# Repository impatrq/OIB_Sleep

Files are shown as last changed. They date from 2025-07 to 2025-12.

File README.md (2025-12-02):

 

ORTHOPEDICAL INTELLIGENT BED

INTEGRANTES:
Ezequiel Bourlot
Lorenzo Fernández
Joaquín Vignettta
Federico Domoñi

Objetivo:
Un colchón que se termo regule dependiendo del estado de sueño en el que se encuentre una persona 

Cómo surgió el proyecto?

La idea del proyecto surgio debido a problemas de sueño generales en la familia de un integrante y cuando buscamos estudios descubrimos que son muy comunes y tienen grandes efectos sobre la mayoria de la población y tambien que se podian aliviar con la temperatura durante el sueño

Video presentación:
https://youtu.be/yen7QRbAJQ8?si=tZINnR11tU10LYak

Página Web e instagram:
https://oib-sleep.vercel.app
https://www.instagram.com/oibsleep?igsh=MXVqZHRpbnUxYzlxYw==

Descripción y aplicaciones:
El proyecto cuenta con una férula la cual toma datos biométricos de la persona (ritmo cardiaco, temperatura ambiente, temperatura corporal, acelerómetro) para determinar el estado de sueño en el que se encuentra un a persona. 
De ahí, manda estos datos a unos tanques de agua donde se determinará si se tiene que mandar agua fría o caliente a través del colchón mediante la utilización de caños de cobre.
La idea es poder prolongar el estado de sueño REM de una persona para así mejorar su calidad de sueño. 
También, al regular la temperatura del colchón, se puede tratar distintas patologías en pacientes de hospitales, ya sean personas con problemas de migrañas, adultos mayores con poca termo regulación, personas cuadripléjicas que no pueden determinar la temperatura de su cuerpo, etc.

Agradecimientos: A Simmons, Layer by Layer y la cooperadora de la escuela por proveernos con los materiales para poder llevar acabo el proyecto y la ayuda.

Contactos:

Joaquin Vignetta: jvignetta@gmail.com
https://www.linkedin.com/in/joaquin-vignetta-2a78a7398 
https://github.com/joavig357

Federico Rodriguez Domoñi: federicorodriguezdomoni@gmail.com
https://www.linkedin.com/in/federico-rodriguez-domoñi-6005b51b8
https://github.com/FedericoRD

Ezequiel Bourlot: ezequiel.bourlot@gmail.com
https://www.linkedin.com/in/ezequiel-bourlot-a96094232
https://github.com/eze2508

Lorenzo Fernandez: lfern9407@gmail.com
https://www.linkedin.com/in/maximo-lorenzo-fernandez-39a160397
https://github.com/lorenzrt

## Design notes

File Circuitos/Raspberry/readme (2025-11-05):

Placa de la raspberry con todas las salidas necesarias

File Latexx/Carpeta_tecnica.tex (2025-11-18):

\documentclass{report}
\usepackage{graphicx}
\usepackage{fancyhdr}
\usepackage[top=2cm]{geometry}
\usepackage{tikz}
\usepackage{etoolbox}
\usepackage[spanish]{babel}
\usepackage[hidelinks]{hyperref}
\usepackage{enumitem}
\usepackage[utf8]{inputenc}
\usepackage[T1]{fontenc}
\usepackage{xcolor}
\usepackage{textgreek}
\usepackage{listings}
\usepackage{float}
\usepackage{amssymb}
\usepackage{amsmath}
\usepackage{siunitx}
\usetikzlibrary{shapes.geometric, arrows.meta, positioning, fit, calc}

\usetikzlibrary{shapes.geometric, arrows.meta, positioning, calc}

\tikzstyle{startstop} = [ellipse, minimum width=2cm, minimum height=0.8cm, text centered, draw=black, fill=blue!20, font=\small\bfseries]
\tikzstyle{process} = [rectangle, minimum width=2.5cm, minimum height=0.8cm, text centered, draw=black, fill=purple!15, font=\scriptsize]
\tikzstyle{decision} = [diamond, minimum width=2cm, minimum height=0.8cm, text centered, draw=black, fill=orange!20, font=\scriptsize, aspect=2]
\tikzstyle{score} = [rectangle, rounded corners, minimum width=2cm, minimum height=0.8cm, text centered, draw=black, fill=green!15, font=\scriptsize]
\tikzstyle{indicator} = [rectangle, rounded corners, minimum width=2cm, minimum height=0.8cm, text centered, draw=black, fill=yellow!20, font=\scriptsize\bfseries]
\tikzstyle{arrow} = [thick,->,>=Stealth]

\setlength{\fboxsep}{0pt}  % elimina el espacio interno
\setlength{\fboxrule}{1pt} % grosor del borde

\renewcommand{\contentsname}{\Huge Índice General}
\renewcommand{\listfigurename}{\Huge Índice de Figuras}
\definecolor{C}{HTML}{2A4190}
\definecolor{Y}{HTML}{FC9B32}

\fancypagestyle{plain}{%
  \fancyhf{}%
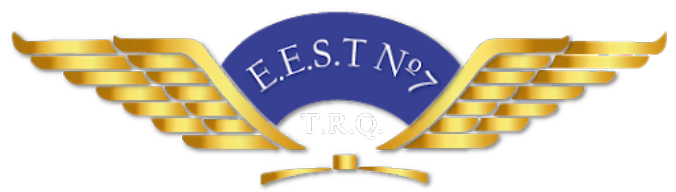
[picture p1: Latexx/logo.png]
  \fancyhead[c]{}%
  \fancyhead[L]{\textbf{\footnotesize OIB Sleep 2025}}%
  \fancyhead[R]{\textbf{\footnotesize E.E.S.T N°7 IMPA "T.R.Q."}}%
  \renewcommand{\footrulewidth}{0.4pt}
  \fancyfoot[C]{\thepage}%
}

% Aplicar el estilo a todas las páginas
\pagestyle{plain}
\renewcommand{\headrulewidth}{0.4pt}

\begin{document}
\begin{center}
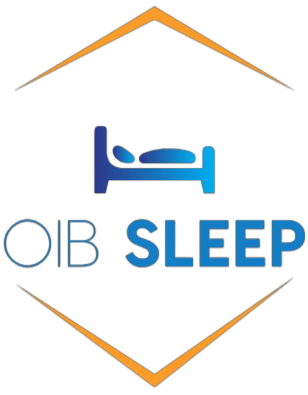
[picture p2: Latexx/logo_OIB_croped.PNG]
    
    \\[1cm]
    {\Huge Carpeta Técnica} \\[0.5cm]
    {\huge 7mo 2da Comision A \\[0.5cm] Año 2025} \\
    \LARGE Bourlot Ezequiel \\
    Fernandez Lorenzo \\
    Domoñi Federico\\
    Vignetta Joaquin\\
\end{center}

\newpage

\tableofcontents 

\newpage
\listoffigures

\newpage
\chapter[\Large Preámbulo]{Preámbulo}

\section[large Nuestro contacto]{\LARGE Nuestro Contacto}
\noindent
\\
\href{https://www.instagram.com/oibsleep}{%
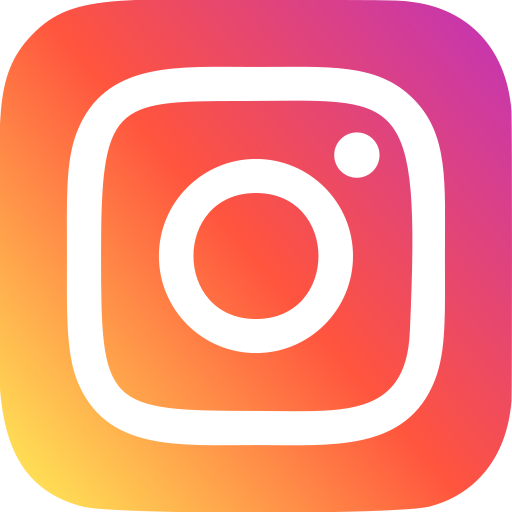
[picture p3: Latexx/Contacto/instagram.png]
    %
} \raisebox{1.25cm}{\Huge\ \ @oibsleep}
\\[0.3cm]
\href{mailto:oibsleep@gmail.com}{%
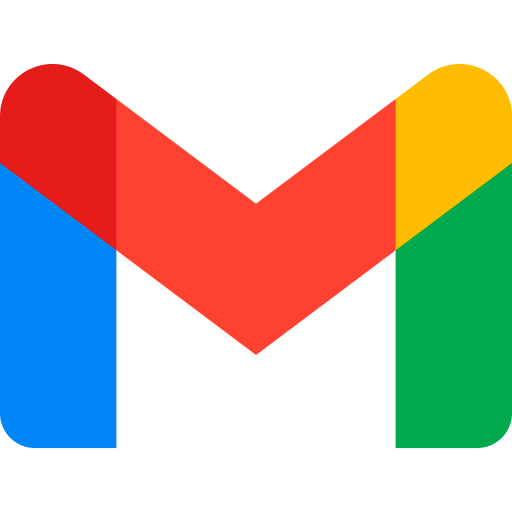
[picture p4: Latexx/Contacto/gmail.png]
    %
}\raisebox{1.25cm}{\Huge\ \ oibsleep@gmail.com}
\\[0.3cm]
\href{https://oib-sleep.vercel.app}{%
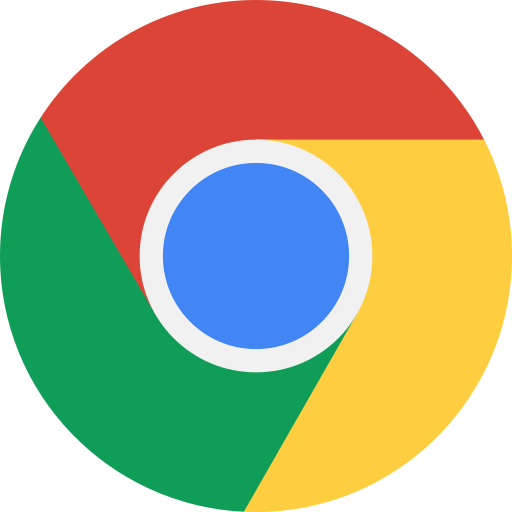
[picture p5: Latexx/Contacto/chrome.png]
    %
}\raisebox{1.25cm}{\Huge\ \ oib-sleep.vercel.app}
\\[0.3cm]
\href{https://github.com/impatrq/OIB_Sleep}{%
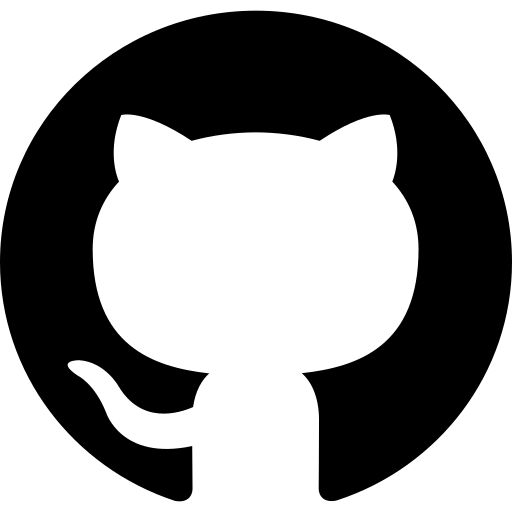
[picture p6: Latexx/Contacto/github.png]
    %
}\raisebox{1.25cm}{\Huge\ \ github.com/impatrq/OIB\_Sleep}%
\\

\section[large ¿Quienes somo?]{\LARGE Quienes somos?}

\setlength{\parskip}{1.5em}

% ---------- Integrante 1 ----------
\begin{minipage}{0.45\linewidth}
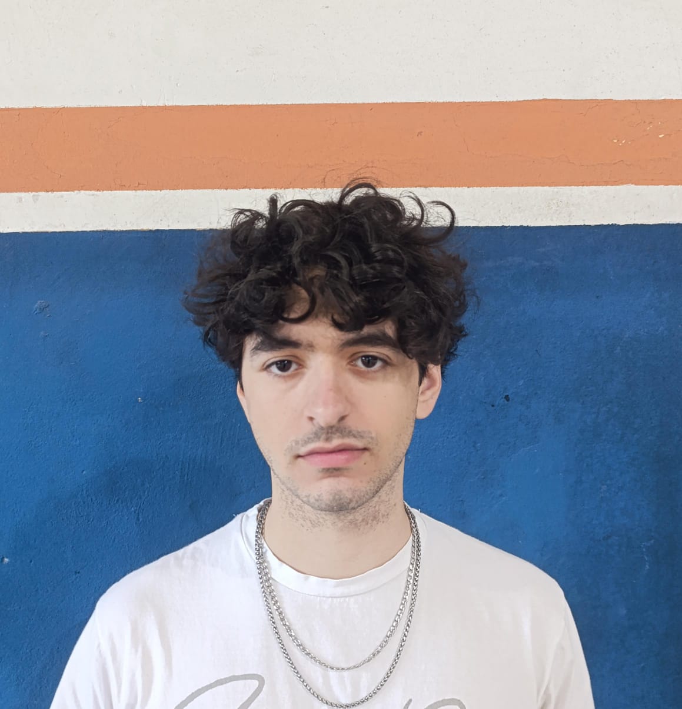
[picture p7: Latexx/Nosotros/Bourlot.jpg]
    
\end{minipage}
\hfill
\begin{minipage}{0.5\linewidth}
    \textbf{\Large Bourlot Ezequiel} \\[4pt]
     \hspace{0.3cm}
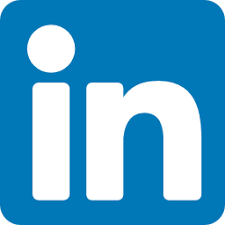
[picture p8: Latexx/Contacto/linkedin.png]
     \hspace{0.3cm}
     \\[10pt]
    \textit{\large Encargado del diseño electrónico, programación y control térmico del sistema.}
\end{minipage}

% ---------- Integrante 2 ----------
\begin{minipage}{0.45\linewidth}
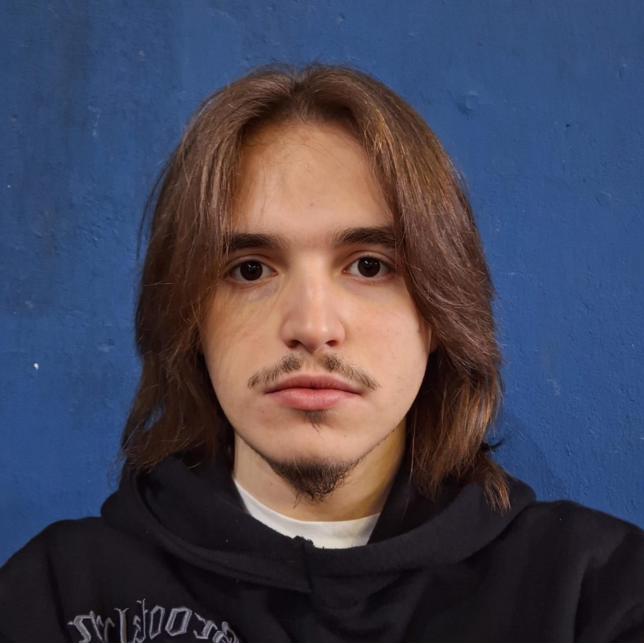
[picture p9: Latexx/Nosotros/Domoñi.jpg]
    
\end{minipage}
\hfill
\begin{minipage}{0.5\linewidth}
    \textbf{\Large Federico Domoñi} \\[4pt]
     \hspace{0.3cm}
     \hspace{0.3cm}
     \\[10pt]
    \textit{\large Responsable del diseño mecánico y estructura del sistema de tanques.}
\end{minipage}

\newpage

% ---------- Integrante 3 ----------
\begin{minipage}{0.45\linewidth}
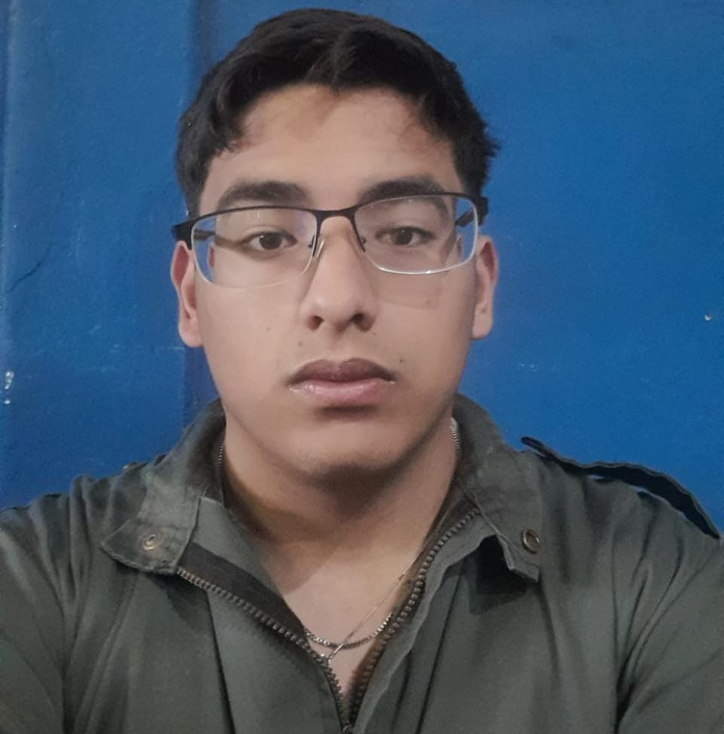
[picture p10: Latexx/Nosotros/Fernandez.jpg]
    
\end{minipage}
\hfill
\begin{minipage}{0.5\linewidth}
    \textbf{\Large Fernández Lorenzo} \\[4pt]
     \hspace{0.3cm}
     \hspace{0.3cm}
     \\[10pt]
    \textit{\large Encargado de documentación técnica, cálculos térmicos y presentación.}
\end{minipage}

% ---------- Integrante 4 ----------
\begin{minipage}{0.45\linewidth}
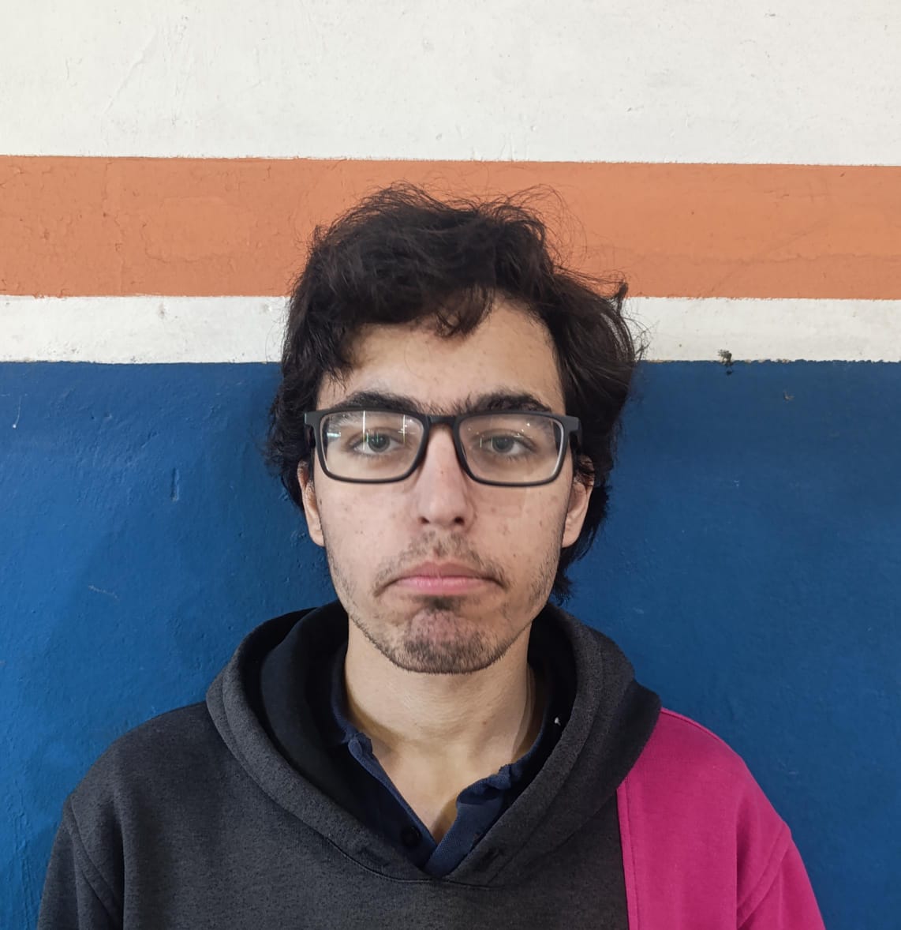
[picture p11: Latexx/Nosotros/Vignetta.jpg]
    
\end{minipage}
\hfill
\begin{minipage}{0.5\linewidth}
    \textbf{\Large Vignetta Joaquín} \\[4pt]
     \hspace{0.3cm}
     \hspace{0.3cm}
     \\[10pt]
    \textit{\large Responsable del diseño visual, edición de video y comunicación del proyecto.}
\end{minipage}

\newpage
\thispagestyle{empty} % sin número ni encabezado

\newgeometry{left=0cm, right=0cm, top=5cm, bottom=0cm}
\begin{figure}[H]
    \centering
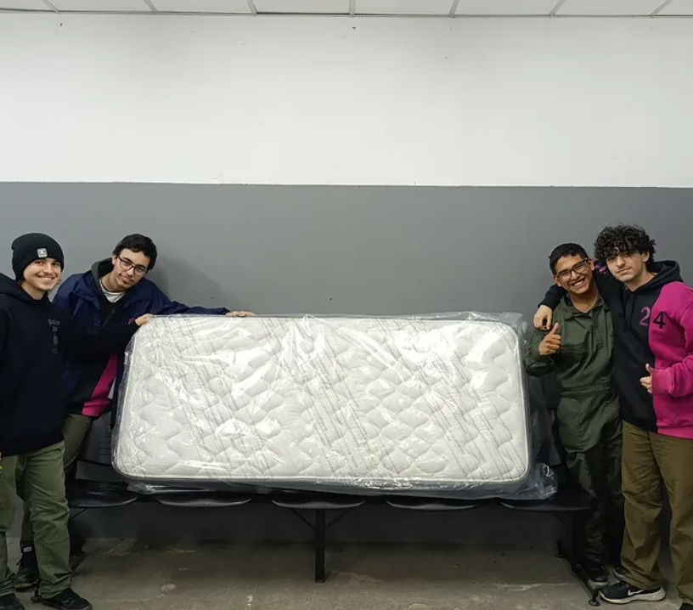
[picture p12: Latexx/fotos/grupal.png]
    
\end{figure}
\restoregeometry

\section[large Docentes a cargo]{\LARGE Docentes a cargo}
\begin{itemize} [label=$\star$]
\Large
    \item Medina Sergio
    \item Carlassara Fabrizio
    \item Palmier Diego
    \item Bianco Carlos 
    \item Arguello Gabriel
    \item Solomiewicz Federico
\end{itemize}

\section[\large Agradecimientos]{\Large agradecimientos}
\noindent
\large
Agradecemos a la Asociación Cooperadora del IMPA.\\
Agradecemos a Simmons Por el colchón, que fue lo principal en nuestro proyecto\\
Agradecemos a layer by layer por los acoples para las mangueras\\
Agradecemos al personal docente de la institución por el inmenso apoyo que nos brindaron.

\section[\large Lenguajes usados]{\Large Lenguajes usados}
\begin{itemize} [label=$\bullet$]
    \item HTML5 \raisebox{-0.1cm} {\includegraphics[height=0.4cm] {lenguajes/html-5}}
    \item CSS3 \raisebox{-0.06cm} {\includegraphics[height=0.4cm] {lenguajes/css-3}}
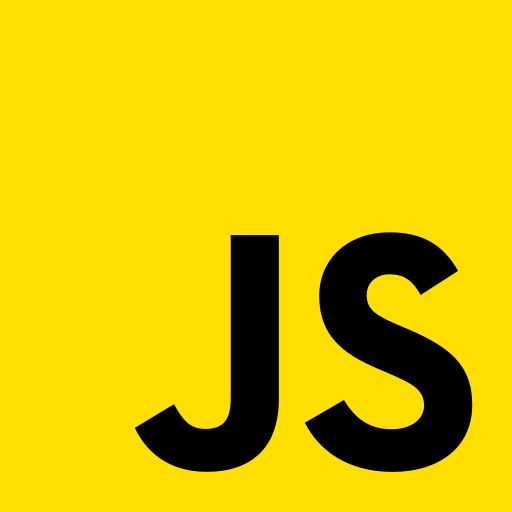
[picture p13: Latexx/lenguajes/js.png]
    \item JavaSCript \raisebox{-0.1cm} {}
    \item Python \raisebox{-0.1cm} {\includegraphics[height=0.4cm] {lenguajes/python}}
    \item C++ \raisebox{-0.1cm} {\includegraphics[height=0.4cm] {lenguajes/c-}}
    \item LaTeX \raisebox{-0.1cm} {\includegraphics[height=0.4cm] {lenguajes/LaTeX_logo.svg}}
\end{itemize}

\section[\large Programas utilizados]{\Large Programas utilizados}
\begin{itemize} [label=$\bullet$]
    \item Visual Studio Code \raisebox{-0.1cm} {\includegraphics[height=0.4cm] {programas/vscode.png}}
    \item OverLeaf \raisebox{-0.06cm} {\includegraphics[height=0.4cm] {programas/overleaf}}
    \item PlatformIO \raisebox{-0.06cm} {\includegraphics[height=0.4cm] {programas/PlatformIO}}
    \item Raspberry PI Imager \raisebox{-0.07cm} {\includegraphics[height=0.4cm] {programas/PI}}
    \item PowerShell \raisebox{-0.07cm} {\includegraphics[height=0.4cm] {programas/PowerShell}}
    \item Ubuntu WSL \raisebox{-0.07cm} {\includegraphics[height=0.4cm] {programas/Ubuntu}}
    \item KiCad \raisebox{-0.07cm} {\includegraphics[height=0.4cm] {programas/KiCad}}
    \item Blender \raisebox{-0.1cm} {\includegraphics[height=0.4cm] {programas/Blender}}
    \item AutoCAD \raisebox{-0.07cm} {\includegraphics[height=0.4cm] {programas/AutoCAD}}
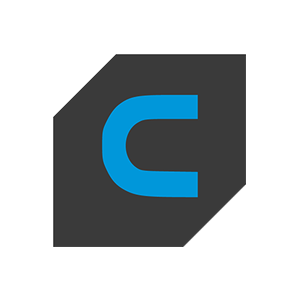
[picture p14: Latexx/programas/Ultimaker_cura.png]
    \item Ultimaker cura \raisebox{-0.15cm}{}
    \item Fusion3D \raisebox{-0.07cm} {\includegraphics[height=0.4cm] {programas/Fusion}}
    \item Word \raisebox{-0.07cm} {\includegraphics[height=0.4cm] {programas/Word}}
    \item Figma \raisebox{-0.07cm} {\includegraphics[height=0.4cm] {programas/Figma}}
    \item Ibis Paint \raisebox{-0.05cm} {\includegraphics[height=0.4cm] {programas/Ibis}}
\end{itemize}

\newpage

\chapter[\Large Introducción]{Introducción}

\section[\large ¿Que es OIBsleep?]{\Huge ¿Que es \textcolor{C}{OIB}\textcolor{Y}{sleep}?}
\large{
La cama ortopédica OIB sleep Es un colchón de uso hospital o personal que cuenta con sistema de calefacción/refrigeración que se regula mediante diferentes mediciones del paciente.
 Esta cama sirve para mejorar la calidad de sueño y prevenir enfermedades como la migraña al regular la temperatura en búsqueda de mantener el sueño REM (profundo) la mayor cantidad de tiempo posible. También se busca solucionar diferentes problemas de salud mediante esta regulación como, por ejemplo:
 \begin{itemize} [label=$\bullet$]
\item Pacientes con problemas de circulación entre ellos diabéticos o personas con problema de artritis suelen tener manos y pies fríos, y pueden no notar bien si están demasiado fríos o calientes (especialmente en el caso de la neuropatía diabética).
\item Adultos mayores, ya que la regulación de la temperatura disminuye con la edad.
\item Personas con fibromialgia o dolor crónico, el calor puede aliviar el dolor muscular y articular mientras que el frío reduce la inflamación.
\item Personas con problemas de sueño como insomnio o despertares nocturnos debido a la temperatura
 \end{itemize}
Se puede conseguir regular la temperatura del colchón mediante un sistema con tubos de agua que se regule con mediciones que se hacen con el colchón mismo o con una pulsera. Esto le ayudaría a los hospitales a mantener a varios pacientes en una misma habitación con las temperaturas necesarias para cada uno.
}

\section[\large Utilidades del proyecto]{\Huge Utilidades del proyecto}
Utilidades del proyecto:
OIB sleep es un proyecto planteado para hospitales que busca ayudar a las personas que tienen problemas debido a la falta de sueño y también a quienes la temperatura puede ayudar con sus respectivas enfermedades.
Tomamos la temperatura como base, ya que El entorno térmico es uno de los factores más importantes que pueden afectar el sueño humano''. Los efectos típicos de la exposición al calor o al frío son un aumento del estado de vigilia y una disminución del sueño de movimientos oculares rápidos (REM) y del sueño de ondas lentas.

\section[\large Impacto en Argentina]{\Huge Impacto en Argentina}
En Argentina, los problemas relacionados con el sueño representan un desafío creciente para la salud pública. 
Según un estudio de la Universidad Favaloro, \textbf{el 75\% de la población presenta algún tipo de alteración del sueño}, lo cual evidencia la necesidad de soluciones innovadoras que contribuyan a mejorar el descanso y la calidad de vida.  

\subsection{Impacto en la salud pública}
\begin{itemize} [label=$\bullet$]
    \item Mejora la calidad del sueño, reduciendo riesgos asociados a insomnio, migrañas y problemas cardiovasculares.  
    \item Favorece a pacientes con enfermedades crónicas como artritis, fibromialgia, diabetes y problemas de circulación, donde la regulación térmica es un factor clave.  
    \item Contribuye al bienestar de adultos mayores, un grupo poblacional que representa más del 11\% de los argentinos y que suele tener dificultades para regular la temperatura corporal durante el descanso.  
\end{itemize}

\subsection{Impacto en hospitales y centros de salud}
\begin{itemize} [label=$\bullet$]
    \item Permite la \textbf{regulación de la temperatura individual en habitaciones compartidas}, lo cual mejora la atención personalizada y optimiza el uso de recursos.  
    \item Potencial ahorro energético al evitar climatizar espacios completos, reduciendo los costos operativos.  
\end{itemize}

\subsection{Impacto en el mercado argentino}
\begin{itemize} [label=$\bullet$]
    \item Dada la alta prevalencia de trastornos del sueño, existe un \textbf{mercado amplio} para este tipo de tecnologías tanto en hospitales como en el uso domiciliario.  
    \item La producción nacional del sistema puede fomentar la \textbf{industria tecnológica local}, generando empleo y reduciendo costos de importación.  
\end{itemize}

\section[\large ¿Por qué OIBsleep?]{\Huge ¿Por qué \textcolor{C}{OIB}\textcolor{Y}{sleep}?}

\subsection{Usuarios que ayuda}
OIB Sleep está diseñado para mejorar la salud del sueño tanto en entornos hospitalarios como domésticos. Esto se logra a través de la regulación inteligente de la temperatura, ayudando a grupos como:
\begin{itemize}
    \item adutlos mayores
    \item Personas diabéticas
    \item Personas con insomnio
    \item Personas con fibromialgia
\end{itemize}

\subsection{Limitaciones de los métodos tradicionales}
El aire acondicionado, la estufa y otros métodos permiten modificar la temperatura del ambiente, pero ninguno de estos sistemas se adapta a las necesidades térmicas específicas de tu cuerpo ni responde a los cambios que experimentás mientras dormís. Estos métodos actúan de forma general sobre toda la habitación, sin tener en cuenta las variaciones naturales de la temperatura corporal a lo largo de la noche.
Además, al climatizar todo el espacio en lugar de centrarse únicamente en la persona, generan un consumo energético considerablemente mayor, lo que se traduce en un uso ineficiente de la energía y en un impacto ambiental más alto.

\subsection{La importancia del confort térmico durante el sueño}
La temperatura corporal no permanece constante durante el sueño: tiende a descender durante las fases más profundas y vuelve a elevarse de manera natural al acercarse el momento del despertar. Este ciclo térmico cumple un rol fundamental en la regulación del descanso y en la transición entre las distintas etapas del sueño.
Cuando el entorno no acompaña estos cambios —por ejemplo, si la habitación se mantiene demasiado cálida o demasiado fría—, el cuerpo debe esforzarse para compensar esa diferencia, lo que puede provocar microdespertares e interrumpir el descanso, reduciendo así la calidad y la continuidad del sueño.

\subsection{Una solución personalizada y directa}
OIB Sleep actúa directamente sobre la cama, en contacto con tu cuerpo, ajustando la temperatura del colchón en tiempo real según tus necesidades. De esta forma, el sistema responde de manera inteligente a los cambios térmicos que se producen durante el sueño, brindando una sensación de confort constante y personalizada.
Al intervenir únicamente sobre el colchón y no sobre el ambiente completo, permite alcanzar el confort térmico ideal con un consumo energético significativamente menor y sin alterar la temperatura del entorno.

\subsection{Confort desde el primer momento}
Más allá de su control inteligente, OIB Sleep ofrece funciones pensadas para maximizar el confort desde el primer momento. Permite precalentar la cama en invierno o enfriarla en verano antes de acostarte, logrando así que el colchón alcance la temperatura ideal incluso antes de que te recuestes.
De esta manera, transforma el momento de ir a dormir en una experiencia más placentera y personalizada, adaptándose a tus preferencias y al clima de cada estación.

\chapter[\Large Estructura]{Estructura}
\section[\large ¿Como esta estructurada la cama?]{\Huge ¿Como esta estructurada la cama?}
La cama cuenta con un colchón especialmente modificado en cuyo interior se instalaron Caños de cobre de 1/4 x 1 m esmaltados.Para colocarlos, utilizamos una plegadora que nos permitió insertar los tubos dentro del colchón realizando una serie de dobleces estratégicos, asegurando así una distribución uniforme del calor a lo largo de toda la superficie.
El sistema está compuesto por dos circuitos independientes: uno por el que circula agua caliente y otro por el que circula agua fría. Ambos tubos están conectados a sus respectivos tanques, lo que permite regular la temperatura del colchón de manera precisa y eficiente.

\begin{figure}[H]
\centering
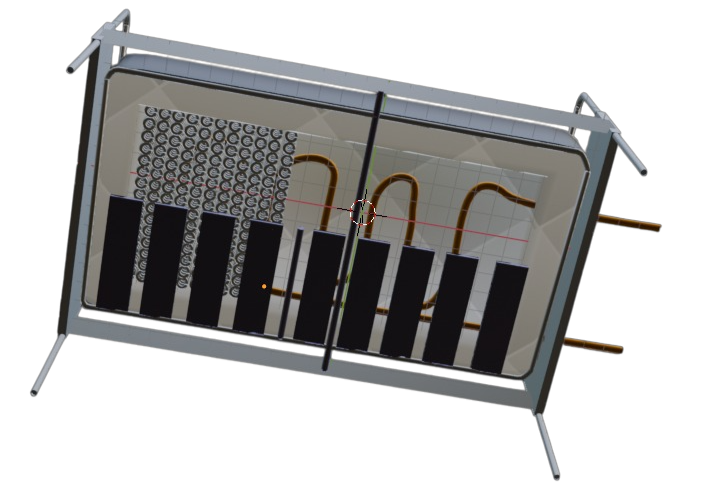
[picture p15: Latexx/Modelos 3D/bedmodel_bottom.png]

\caption{Vista inferior del modelo 3D de la cama con sistema de tubos}
\label{fig:cama_inferior}
\end{figure}

\section[\large ¿Como esta estructurado el brazalete?]{\Huge ¿Como esta estructurado el brazalete?}
El brazalete fue diseñado mediante un modelo 3D desarrollado en Blender y fabricado con material PLA, elegido por su equilibrio entre solidez, ligereza y flexibilidad.
El diseño incluye una serie de perforaciones distribuidas estratégicamente para permitir una adecuada ventilación y el paso del aire, garantizando así mayor comodidad durante su uso. En la siguiente imagen se puede observar la estructura y disposición de dichos orificios.

\begin{figure}[H]
\centering
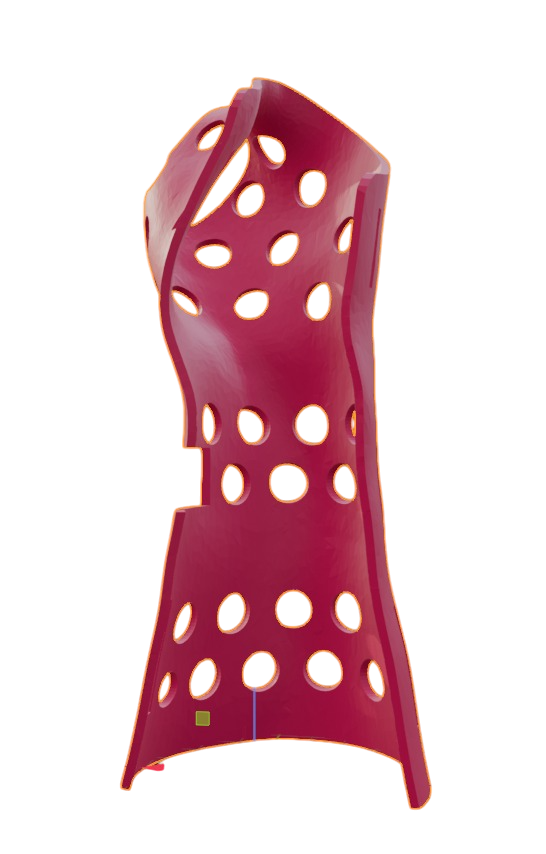
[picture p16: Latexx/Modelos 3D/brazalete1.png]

\caption{Diseño 3D del brazalete - Vista frontal con perforaciones de ventilación}
\label{fig:brazalete_frontal}
\end{figure}

\begin{figure}[H]
\centering
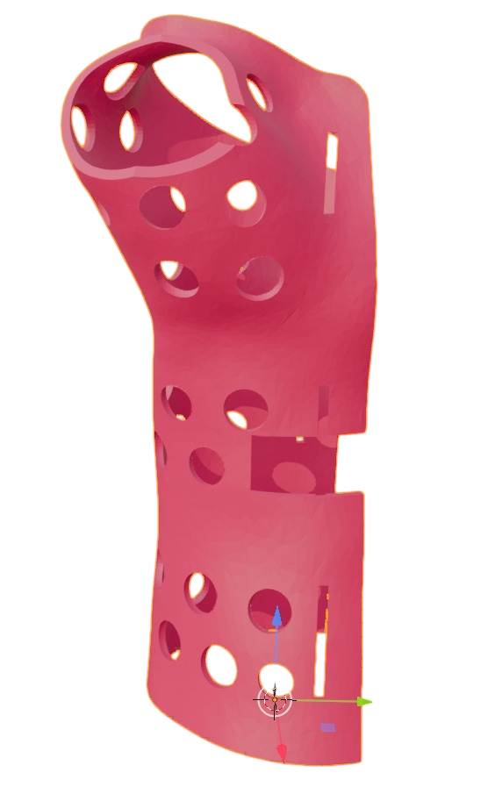
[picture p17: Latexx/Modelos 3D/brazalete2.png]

\caption{Diseño 3D del brazalete - Vista lateral detallada}
\label{fig:brazalete_lateral}
\end{figure}

\newpage
Además, el brazalete está recubierto con una capa de goma espuma, lo que mejora la sensibilidad al tacto y aporta una sensación más cómoda al contacto con la piel.
Una vez impreso, el modelo fue lijado cuidadosamente para eliminar imperfecciones y lograr una superficie uniforme, optimizando tanto su estética como su funcionalidad.

\begin{figure}[H]
\centering
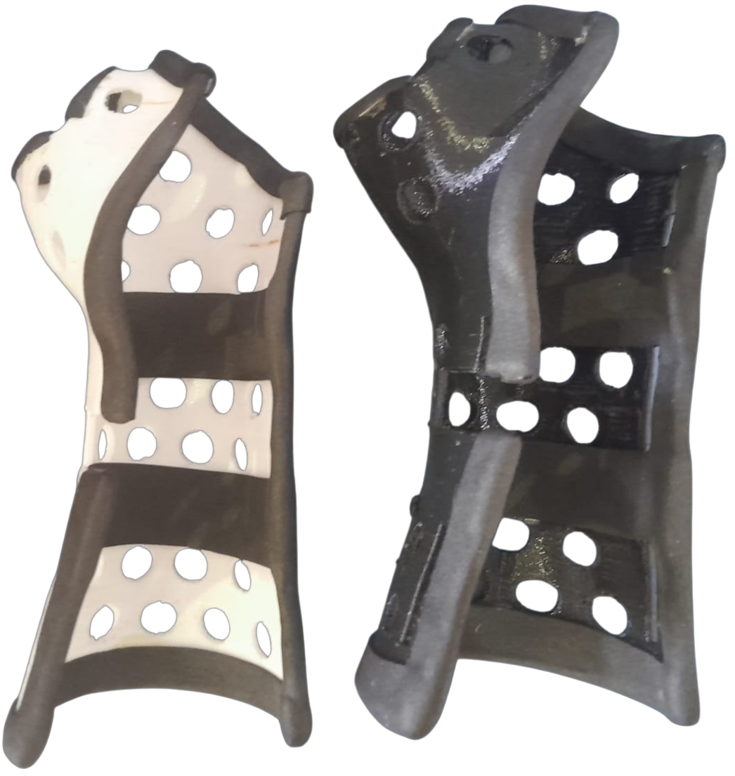
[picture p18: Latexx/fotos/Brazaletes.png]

\caption{Brazaletes impresos y terminados}
\label{fig:brazaletes_terminados}
\end{figure}

El brazalete cuenta con un compartimiento destinado a alojar los diferentes sensores, diseñado para mantenerlos firmemente en su lugar y facilitar su conexión. Este compartimiento se fija al brazalete mediante abrojos (velcro), lo que permite retirarlo o ajustarlo fácilmente según sea necesario, garantizando al mismo tiempo estabilidad y comodidad durante el uso.

\begin{figure}[H]
\centering
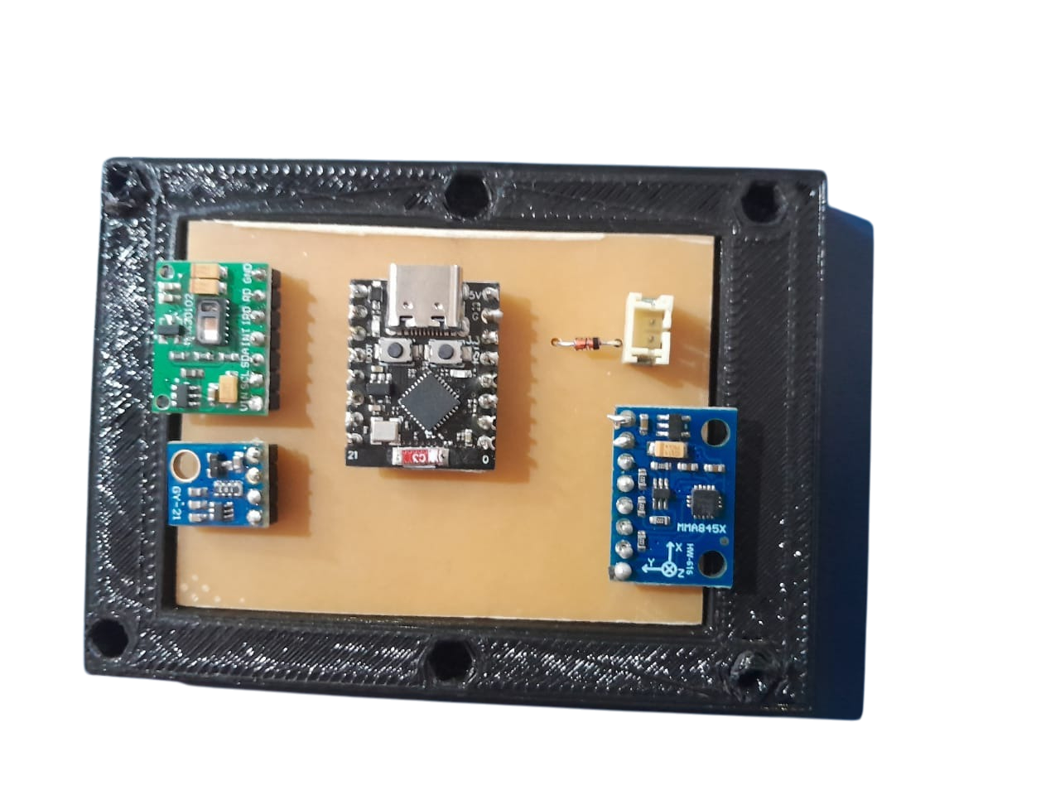
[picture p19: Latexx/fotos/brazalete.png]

\caption{Brazalete con compartimiento para sensores}
\label{fig:brazalete_sensores}
\end{figure}

\begin{figure}[H]
\centering
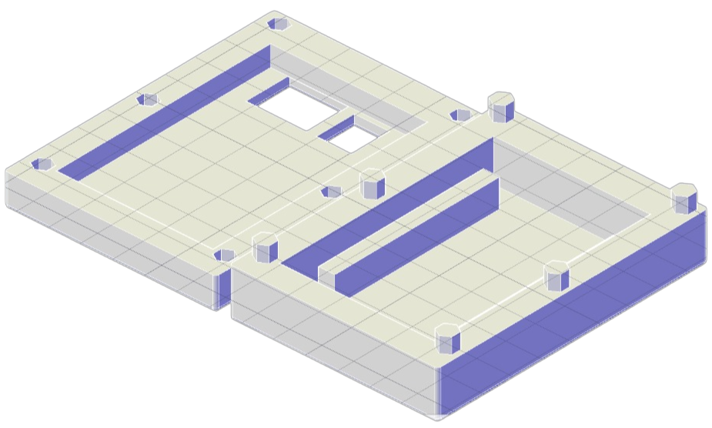
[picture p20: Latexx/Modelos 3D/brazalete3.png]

\caption{Modelo 3D del compartimiento de sensores del brazalete}
\label{fig:brazalete_compartimiento}
\end{figure}

\section[\large ¿Como están estructurados los tanques?]{\Huge ¿Como están estructurados los tanques?}
En este proyecto se utilizan dos tanques principales, uno destinado al agua fría y otro al agua caliente, los cuales desempeñan un papel fundamental en el sistema de regulación térmica. Ambos tanques están aislados térmicamente con espuma de poliuretano, un material de alta densidad que permite mantener la temperatura interna estable, reduciendo significativamente las pérdidas de calor o de frío hacia el exterior.

El tanque de agua fría está equipado con seis celdas Peltier, cada una acompañada de su disipador de calor y su correspondiente cooler, también tienen una placa de metal del la parte del tanque para que se pase mejor el calor. Estas celdas funcionan mediante un principio termoeléctrico: al recibir corriente, una de sus caras absorbe el calor del interior del tanque (enfriando el agua), mientras que la otra lo disipa hacia afuera con la ayuda de los coolers. De esta forma, se logra un proceso de refrigeración activa y controlada, manteniendo la temperatura del agua dentro de los rangos deseados.

\begin{figure}[H]
    \centering
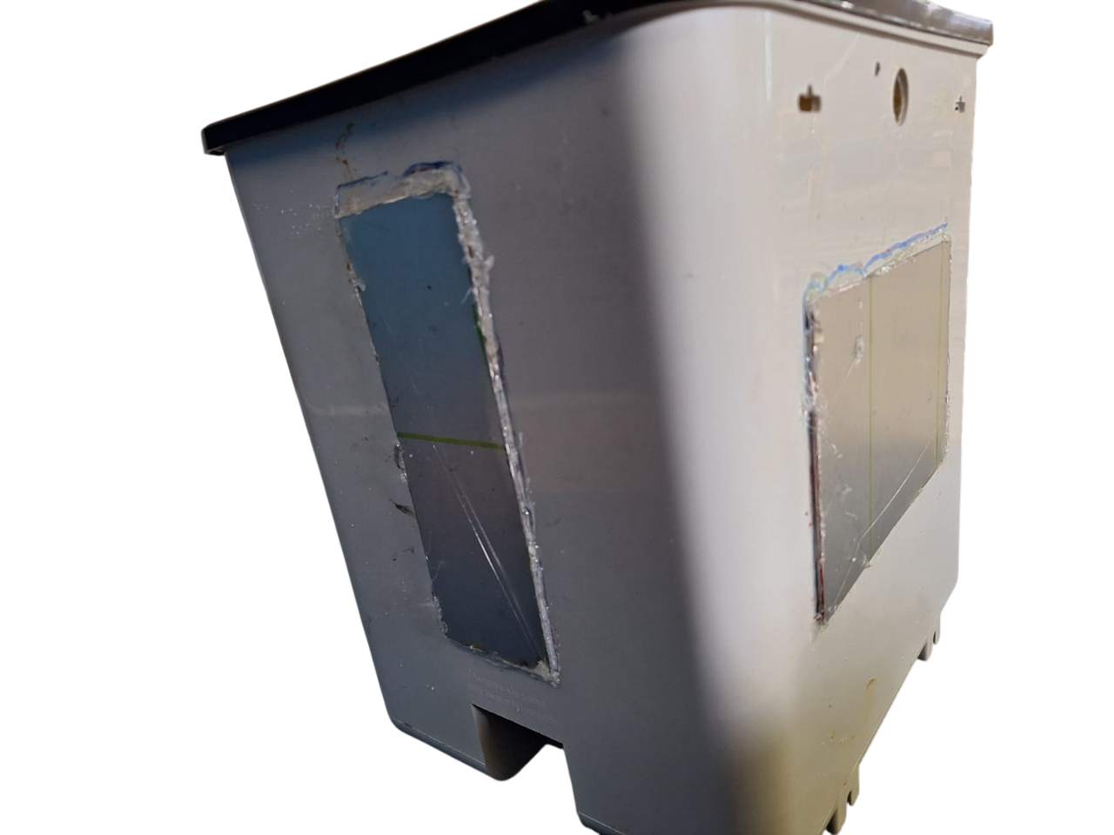
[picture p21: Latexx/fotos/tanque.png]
    \fbox{}
    \caption{Tanque frío sin las celdas}
    \label{fig:tanquefrio}
\end{figure}

Por otro lado, el tanque de agua caliente cuenta con una resistencia eléctrica encargada de elevar la temperatura del agua. Este sistema está supervisado por un sensor de temperatura sumergible, que mide de manera continua el valor térmico del agua y permite pausar automáticamente el calentamiento cuando se alcanza una temperatura preestablecida, evitando sobrecalentamientos y optimizando el consumo energético.

En conjunto, ambos tanques trabajan de forma complementaria dentro del sistema, proporcionando un control térmico eficiente y preciso, esencial para garantizar el confort y la estabilidad del entorno en el que se implementa el proyecto.

\subsection{¿Como están colocados?}

\subsection{Cálculos de temperatura para el agua fría}

El sistema de enfriamiento del tanque de agua fría se basa en la utilización de celdas Peltier TEC1-12706, cada una con una capacidad aproximada de transferencia de calor ($Q_c$) de 60 W cuando opera con una diferencia de temperatura de 10 °C y alimentada a 12 V con un consumo de 6 A (potencia total 72 W). En el diseño propuesto se contempla un tanque con una capacidad total de 20 litros, debidamente aislado con espuma de poliuretano para minimizar las pérdidas térmicas. La temperatura ambiente promedio se considera de 30 °C, y el objetivo es reducir la temperatura del agua a 10 °C.

El agua, con una masa de aproximadamente 20 kg (considerando una densidad de 1 kg/L), requiere una extracción de energía térmica calculada mediante la ecuación:

\[
Q = m \cdot c \cdot \Delta T
\]

donde $c$ es el calor específico del agua (4186 J/kg·°C) y $\Delta T = 20$ °C (de 30 °C a 10 °C). De esta manera, la cantidad total de energía a retirar del sistema es de aproximadamente:

\[
Q = 20\,\text{kg} \times 4186\,\frac{\text{J}}{\text{kg}\cdot{}^\circ\text{C}} \times 20\,^\circ\text{C} = 1{,}674{,}400\,\text{J}
\]

Cada celda Peltier TEC1-12706 puede retirar alrededor de 60 W (60 J/s) en condiciones óptimas; sin embargo, considerando las ineficiencias y pérdidas térmicas del sistema, se estima una eficiencia real del 40 %, lo que reduce la capacidad efectiva de enfriamiento a unos 24 W por celda.

Para el sistema implementado, se utilizan \textbf{6 celdas Peltier TEC1-12706}, por lo que la potencia total efectiva de enfriamiento es:

\[
P = 6 \times 24\,\text{W} = 144\,\text{W} = 144\,\text{J/s}
\]

En estas condiciones, el tiempo teórico requerido para reducir la temperatura del agua de 30 °C a 10 °C sería:

\[
t = \frac{1\,674\,400\,\text{J}}{144\,\text{J/s}} \approx 11\,625\,\text{s} \approx 3\,\text{h}\,13\,\text{min}.
\]

No obstante, en la práctica, debido a pérdidas adicionales por conducción, eficiencia variable de las celdas y disipación incompleta del calor en la cara caliente, el tiempo real estimado de enfriamiento se sitúa entre \textbf{3,5 y 4 horas}. Con esta configuración, el sistema logra no solo enfriar el agua desde 30 °C hasta los 10 °C, sino también mantenerla estable a esa temperatura, incluso con una temperatura ambiente de 30 °C, gracias al aislamiento térmico del tanque.

Para el control térmico, el sistema utiliza sensores de temperatura \textbf{DS18B20} sumergidos en el tanque de agua fría y otro sensor en la parte interna del tanque de agua caliente para compensar el control térmico global del circuito hidráulico. Los sensores DS18B20 permiten una precisión de $\pm 0.5$ °C, facilitando una regulación exacta de la temperatura. La lectura de los sensores y el control de activación de las celdas Peltier se realiza mediante una \textbf{Raspberry Pi}, que además activa los relés asociados a cada grupo de celdas según las condiciones térmicas programadas.

\chapter[\Large Circuitos]{Circuitos}
\section[\large Resumen]{\Huge Resumen}
Para el correcto funcionamiento del proyecto fue necesario implementar distintos circuitos electrónicos encargados de controlar los diversos sistemas que lo componen. El centro de control principal está basado en una Raspberry Pi Zero 2 W, la cual coordina y administra el comportamiento de todos los componentes del sistema.

Esta placa actúa como el cerebro del proyecto, gestionando la activación de las bombas de agua, el control de las válvulas y el funcionamiento de los módulos de refrigeración y calefacción del colchón. Su tarea es asegurar que cada elemento se encienda o apague en el momento que se necesite, de acuerdo con las necesidades de temperatura determinadas por el algoritmo de control.

Además, la Raspberry Pi se comunica de forma inalámbrica mediante Wi-Fi con la pulsera inteligente del usuario, desde la cual recibe datos en tiempo real sobre parámetros relevantes. Esta información es utilizada por el sistema para ajustar dinámicamente la temperatura del colchón, logrando así un mayor confort y eficiencia energética durante el descanso.
\subsection{Pulsera}
La pulsera cuenta con un módulo ESP32 Mini que se encarga de transmitir de manera inalámbrica la información hacia una Raspberry Pi utilizando conectividad Wi-Fi, estableciendo así una comunicación eficiente y continua entre ambos dispositivos. A la ESP32 Mini se encuentran conectados tres sensores mediante el bus de comunicación I²C, cada uno con una función específica dentro del sistema: un sensor de temperatura AHT10, encargado de registrar las variaciones térmicas del entorno y del cuerpo del usuario; un acelerómetro MMA845Q , utilizado para detectar y analizar los movimientos y la posición corporal; y un sensor de ritmo cardíaco Max30102, que permite medir la frecuencia cardíaca en tiempo real.
Toda la información obtenida por estos sensores es procesada por la ESP32 Mini. Una vez procesados, los resultados son enviados a la Raspberry Pi, que se encarga de realizar el cálculo del estado de sueño del usuario y determinar la temperatura óptima requerida para mantener el confort durante el descanso, utilizando algoritmos de análisis de datos. garantizando un funcionamiento inteligente, autónomo y adaptable a las condiciones individuales de cada usuario.

\begin{figure}[H]
\centering
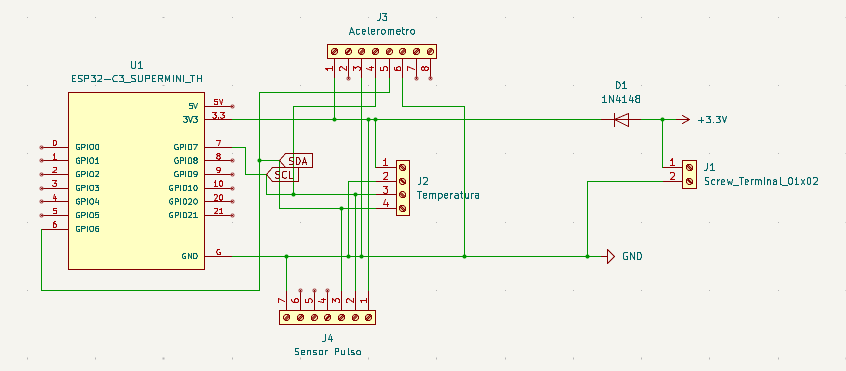
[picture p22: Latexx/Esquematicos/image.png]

\caption{Esquemático del circuito de la pulsera}
\label{fig:EsquematicoPulsera}
\end{figure}

\vspace{1cm}

\begin{figure}[H]
\centering
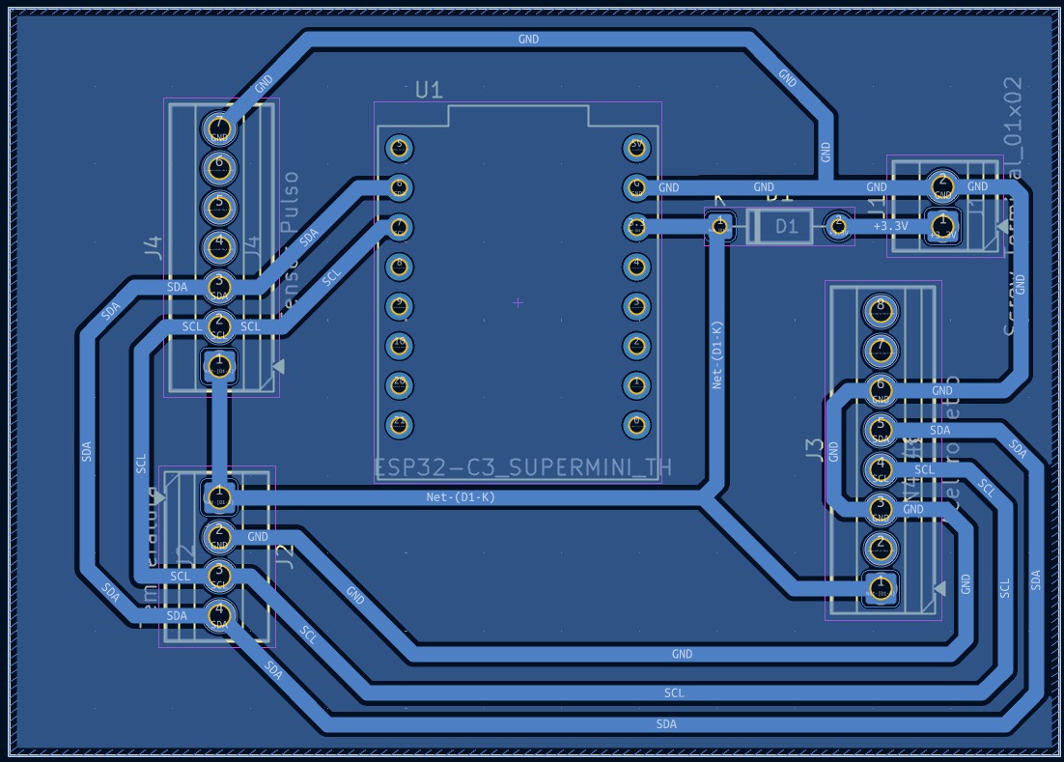
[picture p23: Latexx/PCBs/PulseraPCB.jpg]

\caption{PCB del circuito de la pulsera}
\label{fig:PCBPulsera}
\end{figure}

\subsection{Bombas de agua}
El circuito de bombeo está formado por dos módulos idénticos que permiten la conmutación y alimentación de las bombas mediante control digital desde la Raspberry Pi, cada módulo integra un relé electromecánico modelo SRD-12VDC-SL-C accionado a 12 V para aislar la carga de la lógica de control, un transistor BC337 empleado como interruptor de baja impedancia para manejar la bobina del relé desde un pin GPIO de la Raspberry Pi y los componentes de protección y polarización necesarios para un funcionamiento seguro y fiable, entre estos se consideran la resistencia de base para limitar la corriente hacia la base del BC337, un diodo 1N4007 conectado en paralelo con la bobina del relé para absorber picos inductivos y proteger el transistor.

\begin{figure}[H]
\centering
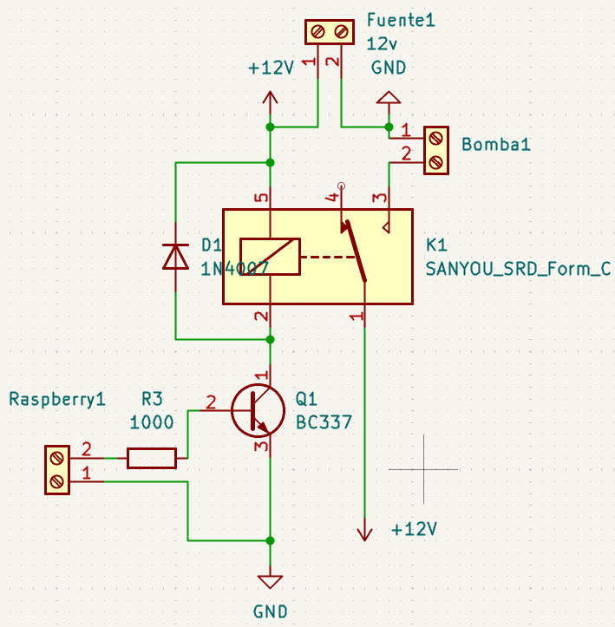
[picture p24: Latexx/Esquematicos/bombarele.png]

\caption{Esquemático del circuito de las bombas de agua}
\label{fig:Esquematicobombarele}
\end{figure}

\begin{figure}[H]
\centering

\caption{PCB del circuito de las bombas de agua}
\label{fig:PCBBombas}
\end{figure}

\subsection{Valvulas/Resistencia}
El circuito encargado del control de las válvulas y de la resistencia del calefón está diseñado bajo el mismo principio de funcionamiento que el utilizado en el sistema de bombas, empleando un relé y un transistor como elementos principales de conmutación y control. Sin embargo, a diferencia del circuito anterior, en este caso los dispositivos controlados operan con tensión de red de 220 V, por lo que la llave de conmutación del relé trabaja directamente sobre la línea de 220 V en lugar de hacerlo sobre una de 12 V, garantizando así la capacidad de manejar las cargas de mayor potencia que requieren estos componentes.

El relé es accionado mediante un transistor BC337, que actúa como interfaz entre la lógica de control de la Raspberry Pi y el circuito de potencia, permitiendo aislar eléctricamente la señal de control de los niveles de tensión elevados. En la entrada de control proveniente de la Raspberry Pi se incorpora una resistencia de 1 kΩ, cuya función principal es limitar la corriente hacia la base del transistor y proteger tanto al microcontrolador como al propio circuito de conmutación y un diodo en paralelo a la bobina del rele, asegurando un funcionamiento estable y seguro en todo momento.

\begin{figure}[H]
\centering

\caption{Esquemático del circuito de las valvulas y resistencia}
\label{fig:EsquematicoValvulasResistencia}
\end{figure}

\begin{figure}[H]
\centering

\caption{PCB del circuito de las valvulas y resistencia}
\label{fig:PCBvalvulasResistencia}
\end{figure}

\subsection{Raspberry Pi Zero 2 W}
Esta placa constituye el núcleo principal de control de todos los sistemas, siendo el elemento encargado de coordinar, procesar y ejecutar las distintas funciones automatizadas del conjunto. Su diseño integra una serie de salidas de 3.3 V y de tierra (GND) destinadas a la alimentación de los módulos y sensores periféricos, además de contar con pines GPIO programables, utilizados para emitir señales de control hacia los diferentes actuadores del sistema, entre ellos las bombas, válvulas y mecanismos de regulación térmica. Asimismo, dispone de una interfaz de comunicación I²C, mediante la cual se establecen las conexiones con los sensores de temperatura distribuidos en las distintas secciones del sistema, permitiendo una adquisición de datos precisa y sincronizada.

La placa tiene como función principal ejecutar el algoritmo de control de sueño, el cual recibe y procesa la información proveniente del módulo ESP32 Mini instalado en la pulsera del usuario. A partir de los datos recopilados por los sensores de temperatura, ritmo cardíaco y movimiento, el algoritmo realiza un análisis integral que permite determinar la temperatura ideal del entorno para optimizar el descanso del usuario. Una vez obtenida esta temperatura objetivo, la placa se encarga de activar y regular los diferentes sistemas asociados, tales como calefacción, refrigeración o circulación de agua, enviando las órdenes correspondientes a cada componente mediante las salidas de control.

Este diseño garantiza una integración completa entre la etapa de sensado y la de actuación, logrando una operación eficiente, segura y adaptable a las condiciones variables del entorno y las necesidades del usuario. Además, su arquitectura modular facilita futuras actualizaciones o ampliaciones del sistema, permitiendo incorporar nuevos sensores o funciones sin modificar la estructura general del hardware.

\begin{figure}[H]
\centering

\caption{PCB del circuito de la Raspberry Pi Zero 2 W}
\label{fig:EsquematicoRaspberryPi}
\end{figure}

\begin{figure}[H]
\centering

\caption{PCB del circuito de la Raspberry Pi Zero 2 W}
\label{fig:PCBRaspberryPi}
\end{figure}

\subsection{Celdas de Peltier y Coolers}

El sistema de enfriamiento del tanque de agua fría se basa en el uso de \textbf{celdas Peltier} combinadas con \textbf{coolers} que actúan como disipadores de calor para evitar el sobrecalentamiento de los módulos. Este conjunto permite mantener una temperatura baja y estable dentro del tanque, garantizando un rendimiento eficiente y seguro durante el funcionamiento.

En total, el sistema cuenta con \textbf{seis celdas Peltier modelo TEC1-12706}, seleccionadas por su capacidad de enfriar de manera efectiva mediante el principio termoeléctrico. Estas celdas están dispuestas estratégicamente para maximizar la transferencia térmica y optimizar la distribución del frío dentro del tanque.

Cada celda se encuentra acompañada por su respectivo \textbf{cooler y disipador de aluminio}, cuya función principal es evacuar el calor generado en la cara caliente de la Peltier, asegurando así su correcto desempeño y prolongando su vida útil.

La alimentación eléctrica del sistema se realiza mediante una \textbf{fuente de 12V y 40Ah}, modelo \textbf{FG-40M}, la cual provee la corriente necesaria para el funcionamiento simultáneo de las seis celdas. Las conexiones se establecen en \textbf{paralelo}, lo que permite mantener una tensión constante en cada módulo y equilibrar el consumo total del sistema, garantizando estabilidad y eficiencia energética.

Este diseño proporciona un método de refrigeración controlado, confiable y adaptable, ideal para mantener las condiciones térmicas requeridas por el sistema principal del proyecto.

\chapter[\Large Código]{Código}      

\section[\large Resumen]{\Huge Resumen}
Una de las partes más vitales del proyecto es el desarrollo del código, ya que representa el núcleo lógico que permite la comunicación, el procesamiento de datos y la toma de decisiones dentro del sistema. La arquitectura del software se divide en cuatro módulos principales, cada uno con una función específica y complementaria que, en conjunto, garantizan el correcto funcionamiento de la cama inteligente.

El primer módulo es el Presence Detector, encargado de analizar en tiempo real si hay una persona sobre la cama. Para ello, realiza una fusión de datos provenientes de distintos sensores —como temperatura, movimiento y ritmo cardíaco— con el fin de estimar de manera precisa la presencia o ausencia del usuario. Este componente es fundamental, ya que su salida condiciona el funcionamiento de los demás módulos.

El segundo módulo, denominado analyzer.py, es responsable de ejecutar todos los cálculos del algoritmo principal. A partir de la información recibida del Presence Detector y de los sensores, este componente determina las acciones a tomar para mantener la temperatura del colchón dentro del rango de confort del usuario. En función de las condiciones detectadas, el módulo decide si se debe activar el sistema de enfriamiento o el de calentamiento del agua, buscando siempre optimizar la experiencia de descanso.

El tercer módulo es el Smart Bed Controller, el cual actúa como intermediario entre el software lógico y el hardware físico. Su función es enviar señales de control —en forma de valores binarios (1 o 0)— hacia los tanques de agua fría y caliente y a sus valvulas electricas, activando o desactivando los relés correspondientes, tambien apaga las bombas a cada cierto tiempo para que no se quemen. Gracias a este controlador, las decisiones tomadas por el algoritmo pueden traducirse en acciones concretas sobre el sistema hidráulico.

Por último, se encuentra el módulo correspondiente a la pulsera inteligente, que cumple un rol clave en la adquisición de datos fisiológicos del usuario. Este dispositivo portátil recopila información proveniente de sus sensores (como frecuencia cardíaca, temperatura y movimiento) y la transmite a la Raspberry Pi mediante el protocolo MQTT, utilizando una conexión Wi-Fi local. De esta forma, la cama inteligente dispone de datos actualizados y precisos para alimentar el algoritmo de control térmico.

En conjunto, estos cuatro módulos conforman un sistema integral capaz de detectar la presencia del usuario, analizar su estado, tomar decisiones autónomas y ejecutar las acciones necesarias para ajustar la temperatura del colchón. Esta estructura modular permite un desarrollo escalable, fácil de mantener y adaptable a futuras mejoras del proyecto.

\section[\large Explicación Técnica Detallada - Presence Detector]{\Huge Explicación Técnica Detallada - Presence Detector}

\subsection{Arquitectura General del Sistema}

El módulo \texttt{presence\_detector.py} implementa un sistema de detección de presencia en cama inteligente mediante fusión multi-sensor, utilizando cinco indicadores independientes que se combinan para generar un nivel de confianza global.

\subsection{Clase Principal: BedPresenceDetector}

\subsubsection*{Atributos de Estado}

\textbf{Estado de presencia actual:}
\begin{itemize}
  \item \texttt{bed\_occupied (bool)}: Indica si la cama está ocupada actualmente.
  \item \texttt{presence\_confidence (float)}: Nivel de confianza de presencia en porcentaje (0-100).
  \item \texttt{presence\_history (list)}: Buffer circular que almacena los últimos N valores de confianza.
  \item \texttt{presence\_start\_time (float)}: Timestamp Unix del momento en que se detectó entrada a la cama.
\end{itemize}

\textbf{Valores de referencia (baseline):}
\begin{itemize}
  \item \texttt{baseline\_temperature (float)}: Temperatura de referencia de la cama vacía, actualizable dinámicamente.
  \item \texttt{baseline\_activity (float)}: Nivel de actividad de referencia (actualmente no utilizado).
\end{itemize}

\textbf{Parámetros configurables:}
\begin{itemize}
  \item \texttt{confidence\_threshold\_enter}: Umbral para detectar entrada (60\% por defecto).
  \item \texttt{confidence\_threshold\_exit}: Umbral para detectar salida (20\% por defecto).
  \item \texttt{thermal\_threshold}: Incremento térmico sobre baseline (1.5°C por defecto).
  \item \texttt{activity\_threshold}: Nivel mínimo de actividad (0.001 por defecto).
  \item \texttt{hr\_min} y \texttt{hr\_max}: Rango válido de frecuencia cardíaca (40–150 BPM).
  \item \texttt{history\_size}: Tamaño del buffer de historial (30 muestras).
  \item \texttt{confirmation\_time}: Muestras consecutivas necesarias para confirmar salida (15 muestras).
\end{itemize}

Todos los parámetros se cargan desde el módulo \texttt{bed\_config}, permitiendo ajuste sin modificar el código.

\subsection{Método Principal: \texttt{detect\_presence()}}

\subsubsection*{Flujo de Procesamiento}

El método recibe un diccionario \texttt{sensor\_data} con:
\begin{itemize}
  \item \texttt{bed\_temperature}: Lectura del sensor HTU21D.
  \item \texttt{activity}: Magnitud del vector del acelerómetro MMA8451.
  \item \texttt{heart\_rate}: Frecuencia cardíaca calculada por el MAX30102.
  \item \texttt{hr\_valid}: Booleano que indica si la medición de HR es confiable.
  \item \texttt{finger\_present}: Booleano indicando contacto físico con el sensor óptico.
\end{itemize}

\subsubsection*{Sistema de Puntuación Multi-Indicador}

\paragraph{1. Indicador Térmico (máximo 40 puntos)}
\begin{verbatim}
temp_elevation = bed_temp - baseline_temperature
\end{verbatim}

\textbf{Criterios:}
\begin{itemize}
  \item Si \texttt{temp\_elevation > thermal\_threshold}: +30 puntos.
  \item Si \texttt{temp\_elevation > thermal\_threshold * 2}: +10 puntos adicionales.
\end{itemize}

\textbf{Fundamento:} La presencia humana eleva la temperatura de la cama entre 1.5°C y 4°C.

\paragraph{2. Indicador de Movimiento (máximo 25 puntos)}
\begin{verbatim}
activity_score = min(25, int(activity * 25 / 0.1))
\end{verbatim}

\textbf{Fundamento:} Los micro-movimientos durante el sueño generan actividad detectable.

\paragraph{3. Indicador Cardiovascular (máximo 40 puntos)}

\textbf{Criterios:}
\begin{itemize}
  \item Si HR válida y en rango 40–150 BPM: +35 puntos.
  \item Si HR en rango de sueño (50–80 BPM): +5 puntos adicionales.
\end{itemize}

\textbf{Fundamento:} La frecuencia cardíaca válida confirma presencia humana con alta certeza.

\paragraph{4. Indicador de Contacto (máximo 20 puntos)}

\textbf{Criterios:}
\begin{itemize}
  \item Si \texttt{finger\_present == True}: +20 puntos.
\end{itemize}

\textbf{Fundamento:} Detecta contacto físico mediante señal infrarroja reflejada.

\paragraph{5. Indicador Temporal (máximo 10 puntos)}
\begin{verbatim}
avg_confidence = sum(presence_history[-5:]) / 5
\end{verbatim}

\textbf{Criterio:} Si el promedio de las últimas 5 muestras > 50\%, +10 puntos.

\textbf{Fundamento:} La presencia real genera señales consistentes en el tiempo.

\subsubsection*{Cálculo de Confianza Global}
\begin{verbatim}
confidence = min(sum(all_indicators), 100)
\end{verbatim}

La suma ponderada de indicadores se limita a 100\%, siendo tolerante a fallos parciales.

\subsection{Mecanismo de Histéresis}

\subsubsection*{Propósito}
Evita transiciones rápidas entre estados de presencia.

\subsubsection*{Implementación en \texttt{\_update\_presence\_state()}}

\textbf{Entrada (vacía → ocupada):}
\begin{itemize}
  \item Condición: \texttt{confidence >= threshold\_enter}
  \item Acción inmediata: activa ocupación y registra timestamp
\end{itemize}

\textbf{Salida (ocupada → vacía):}
\begin{itemize}
  \item Condición: \texttt{confidence <= threshold\_exit}
\item Confirmación: últimos \texttt{confirmation\_time} valores $\leq 30\%$

  \item Acción: cambia a vacía tras baja confianza sostenida
\end{itemize}

\textbf{Nota:} La asimetría evita falsas salidas durante quietud prolongada.

\subsection{Gestión del Baseline Térmico}

\subsubsection*{Inicialización}
El baseline se toma automáticamente con la primera lectura térmica.

\subsubsection*{Actualización Dinámica}
Cuando la cama está vacía:
\[
baseline = (1 - \alpha) \times baseline_{old} + \alpha \times temp_{current}
\]
con $\alpha = 0.05$.

\subsubsection*{Calibración Manual}
\begin{itemize}
  \item Toma N lecturas en 5 minutos.
  \item Calcula la mediana para eliminar outliers.
  \item Reemplaza el baseline actual.
\end{itemize}

\subsection{Métodos de Utilidad y Debugging}

\begin{itemize}
  \item \texttt{get\_presence\_summary()}: Retorna estado global.
  \item \texttt{get\_detailed\_indicators()}: Análisis granular de indicadores.
  \item \texttt{reset\_presence\_state()}: Limpia historial y banderas.
  \item \texttt{\_get\_time\_occupied()}: Calcula minutos desde detección de entrada.
\end{itemize}

\subsection{Consideraciones de Diseño}

\textbf{Fusión de Sensores:} Suma ponderada de sensores heterogéneos.\\
\textbf{Tolerancia a Fallos:} El sistema sigue operativo ante fallos parciales.\\
\textbf{Adaptabilidad Temporal:} Baseline térmico adaptable a cambios ambientales.\\
\textbf{Escalabilidad:} Parámetros configurables vía \texttt{bed\_config}.

\subsection{Retorno del Método Principal}

El método \texttt{detect\_presence()} retorna:
\begin{itemize}
  \item \texttt{occupied}: estado binario actual.
  \item \texttt{confidence}: nivel de confianza (\%).
  \item \texttt{indicators}: detalle de cada indicador.
  \item \texttt{time\_occupied}: minutos desde entrada.
  \item \texttt{temp\_elevation}: incremento térmico sobre baseline.
  \item \texttt{presence\_changed}: bandera de transición de estado.
\end{itemize}

Este formato estructurado facilita la integración con módulos superiores del sistema de cama inteligente.

\newgeometry{left=1cm, right=0cm, top=2cm, bottom=2cm}
\thispagestyle{empty}

\vspace{1cm}

\begin{tikzpicture}[node distance=1.2cm and 1cm]

% FILA 1 (Izquierda a Derecha)
\node (start) [startstop] {INICIO};
\node (init) [process, right=of start] {Inicializar\\Variables};
\node (detect) [process, right=of init] {detect\\presence};
\node (getdata) [process, right=of detect] {Obtener\\Datos Sensores};

% FILA 2 (Derecha a Izquierda)
\node (checkbase) [decision, below=of getdata] {Baseline\\establecido?};
\node (setbase) [score, left=of checkbase] {Establecer\\baseline};
\node (analyze) [process, left=of setbase] {Analizar 5\\Indicadores};
\node (thermal) [indicator, left=of analyze] {INDICADOR\\TÉRMICO};

% FILA 3 (Izquierda a Derecha)
\node (tempcheck) [decision, below=of thermal] {Elevación\\temp?};
\node (tempscore) [score, right=of tempcheck] {+30 puntos\\+10 bonus};
\node (movement) [indicator, right=of tempscore] {INDICADOR\\MOVIMIENTO};
\node (actcheck) [decision, right=of movement] {Actividad\\>threshold?};

% FILA 4 (Derecha a Izquierda)
\node (actscore) [score, below=of actcheck] {+0 a 25\\puntos};
\node (cardio) [indicator, left=of actscore] {INDICADOR\\CARDIOVASCULAR};
\node (hrcheck) [decision, left=of cardio] {HR válida\\40-150?};
\node (hrscore) [score, left=of hrcheck] {+35 puntos\\+5 bonus};

% FILA 5 (Izquierda a Derecha)
\node (contact) [indicator, below=of hrscore] {INDICADOR\\CONTACTO};
\node (fingercheck) [decision, right=of contact] {Dedo\\presente?};
\node (fingerscore) [score, right=of fingercheck] {+20\\puntos};
\node (temporal) [indicator, right=of fingerscore] {INDICADOR\\TEMPORAL};

% FILA 6 (Derecha a Izquierda)
\node (histcheck) [decision, below=of temporal] {Confianza\\promedio\\>50\%?};
\node (tempscore2) [score, left=of histcheck] {+10\\puntos};
\node (calculate) [process, left=of tempscore2] {Calcular\\Confianza\\Total};
\node (update) [process, left=of calculate] {update\\presence\\state};

% FILA 7 (Izquierda a Derecha)
\node (occcheck) [decision, below=of update] {Cama\\ocupada?};
\node (entrycheck) [decision, right=of occcheck] {Confianza\\>=entrada?};
\node (enter) [process, right=of entrycheck] {\textcolor{green}{$\checkmark$} PRESENCIA\\DETECTADA};
\node (exitcheck) [decision, right=of enter] {Confianza\\<=salida?};

% FILA 8 (Derecha a Izquierda)
\node (confirm) [decision, below=of exitcheck] {Últimas 15\\<30\%?};
\node (exit) [process, left=of confirm] {\textcolor{red}{$\times$} AUSENCIA\\DETECTADA};
\node (return) [process, left=of exit] {Retornar\\Resultado};
\node (end) [startstop, left=of return] {FIN};

% CONEXIONES FILA 1
\draw [arrow] (start) -- (init);
\draw [arrow] (init) -- (detect);
\draw [arrow] (detect) -- (getdata);

% BAJADA A FILA 2
\draw [arrow] (getdata) -- (checkbase);
\draw [arrow] (checkbase) -- node[anchor=south, font=\tiny] {No} (setbase);
\draw [arrow] (checkbase.south) -- ++(0,-0.3) -| node[near start, anchor=south, font=\tiny] {Sí} (analyze);
\draw [arrow] (setbase) -- (analyze);
\draw [arrow] (analyze) -- (thermal);

% BAJADA A FILA 3
\draw [arrow] (thermal) -- (tempcheck);
\draw [arrow] (tempcheck) -- node[anchor=south, font=\tiny] {Sí/No} (tempscore);
\draw [arrow] (tempscore) -- (movement);
\draw [arrow] (movement) -- (actcheck);

% BAJADA A FILA 4
\draw [arrow] (actcheck) -- (actscore);
\draw [arrow] (actscore) -- (cardio);
\draw [arrow] (cardio) -- (hrcheck);
\draw [arrow] (hrcheck) -- node[anchor=south, font=\tiny] {Sí/No} (hrscore);

% BAJADA A FILA 5
\draw [arrow] (hrscore) -- (contact);
\draw [arrow] (contact) -- (fingercheck);
\draw [arrow] (fingercheck) -- node[anchor=south, font=\tiny] {Sí/No} (fingerscore);
\draw [arrow] (fingerscore) -- (temporal);

% BAJADA A FILA 6
\draw [arrow] (temporal) -- (histcheck);
\draw [arrow] (histcheck) -- node[anchor=south, font=\tiny] {Sí/No} (tempscore2);
\draw [arrow] (tempscore2) -- (calculate);
\draw [arrow] (calculate) -- (update);

% BAJADA A FILA 7
\draw [arrow] (update) -- (occcheck);
\draw [arrow] (occcheck) -- node[anchor=south, font=\tiny] {No} (entrycheck);
\draw [arrow] (entrycheck) -- node[anchor=south, font=\tiny] {Sí/No} (enter);
\draw [arrow] (enter) -- (exitcheck);

% BAJADA A FILA 8
\draw [arrow] (occcheck.south) -- ++(0,-0.3) -| node[near start, anchor=south, font=\tiny] {Sí} (exitcheck);
\draw [arrow] (exitcheck) -- node[anchor=west, font=\tiny] {Sí/No} (confirm);
\draw [arrow] (confirm) -- node[anchor=south, font=\tiny] {Sí/No} (exit);
\draw [arrow] (exit) -- (return);
\draw [arrow] (return) -- (end);

% CONEXIÓN DESDE ENTER A RETURN
\draw [arrow] (enter.south) -- ++(0,-0.3) -| (return);

\end{tikzpicture}
    \restoregeometry
    
\newpage

% Sección LaTeX para la documentación técnica del módulo analyzer.py
\section{Módulo de análisis de señales fisiológicas: \texttt{analyzer.py}}
\label{sec:analyzer}

\subsection{Arquitectura general}
El módulo \texttt{analyzer.py} constituye el núcleo de procesamiento analítico del sistema, centralizando las funciones encargadas del análisis de señales fisiológicas y series temporales de estados de sueño. Este módulo se diseñó siguiendo el principio de separación de responsabilidades: no implementa clases de estado ni gestiona operaciones de entrada/salida, limitándose exclusivamente a recibir datos previamente muestreados y preprocesados para devolver métricas cuantificables y eventos de interés clínico.

La única dependencia externa es la biblioteca NumPy, empleada para cálculo vectorizado y operaciones estadísticas básicas, lo que garantiza eficiencia computacional y portabilidad del código.

\subsection{Funciones principales}
A continuación se describen las funciones principales implementadas en el módulo, detallando sus parámetros de entrada, comportamiento esperado y fundamento teórico cuando aplique.

\begin{description}
  \item[\texttt{calculate\_rmssd(ibi)}] Calcula el RMSSD (\emph{root mean square of successive differences}) a partir de una secuencia de intervalos inter-latido (IBI). Esta métrica cuantifica la variabilidad de corto plazo del ritmo cardíaco y es un indicador reconocido de la actividad del sistema nervioso parasimpático~\cite{hrv_standards}. 
  
  La función retorna \texttt{None} si la ventana temporal no contiene suficientes muestras para el cálculo. Matemáticamente, el RMSSD se define como:
  \vspace{1cm}
  \begin{center}
      \[
    \mathrm{RMSSD} = \sqrt{\frac{1}{N-1}\sum_{i=1}^{N-1} (IBI_{i+1} - IBI_i)^2 }
      \]
  \end{center}
  \vspace{1cm}

  La implementación utiliza diferencias sucesivas (\texttt{np.diff}), elevación al cuadrado y cálculo de la raíz de la media aritmética.

  \item[\texttt{calculate\_sdnn(ibi)}] Calcula la desviación estándar (SDNN, \emph{standard deviation of NN intervals}) de la serie completa de IBI. Esta métrica describe la variabilidad global del ritmo cardíaco en la ventana temporal considerada y se obtiene mediante \texttt{np.std}. La función retorna \texttt{None} si la ventana contiene menos de dos muestras válidas.

  \item[\texttt{calculate\_stress\_score(hr, rmssd, sdnn, \ldots)}] Construye un índice heurístico de estrés en escala 0--100 mediante la integración ponderada de tres componentes fisiológicos: frecuencia cardíaca instantánea (\texttt{hr}), RMSSD y SDNN. El proceso de normalización se estructura así:
  \begin{itemize}
    \item \textbf{Frecuencia cardíaca (HR):} Se normaliza respecto a un umbral inferior fijo y un tope configurable, asumiendo una relación monotónica entre FC y nivel de estrés.
    \item \textbf{RMSSD y SDNN:} Se normalizan frente a valores máximos esperados. La contribución al índice de estrés se calcula como $1 - \text{valor normalizado}$, de modo que una mayor variabilidad cardíaca (asociada a mejor regulación autonómica) reduce la puntuación de estrés.
  \end{itemize}
  
  Los pesos por defecto asignados son 0.4 para HR, 0.3 para RMSSD y 0.3 para SDNN. Las normalizaciones se recortan al intervalo $[0, 1]$ para evitar valores fuera de rango. 
  
  \textbf{Nota:} Este índice es una aproximación heurística útil para sistemas de alerta temprana, pero requiere calibración experimental con población objetivo y validación clínica antes de su uso en entornos de producción.

  \item[\texttt{calculate\_sleep\_quality(sleep\_states, hr\_values=None, activity\_levels=None)}] Genera una puntuación de calidad del sueño en escala 0--100 mediante la integración de tres dimensiones fisiológicas y conductuales:
  
  \begin{enumerate}
    \item \textbf{Distribución de estados de sueño:} Se asume una codificación estándar (0=WAKE, 1=LIGHT\_SLEEP, 2=REM\_SLEEP, 3=DEEP\_SLEEP) con resolución temporal de un minuto por muestra. La función compara la distribución observada contra proporciones heurísticas óptimas documentadas en la literatura del sueño (aproximadamente 20\% sueño profundo, 25\% REM, 50\% sueño ligero, $<$5\% vigilia)~\cite{sleep_standards}.
    
    \item \textbf{Consistencia de frecuencia cardíaca:} Si se proporciona el vector \texttt{hr\_values}, se calcula la variabilidad (desviación estándar) durante las fases de sueño. Una menor variabilidad se interpreta como indicador de sueño consolidado y se mapea a una puntuación favorable.
    
    \item \textbf{Nivel de actividad motora:} Si se proporciona \texttt{activity\_levels}, se penaliza la actividad media elevada durante periodos de sueño, dado que refleja fragmentación o inquietud nocturna.
  \end{enumerate}
  
  La puntuación final combina estos tres componentes con pesos de 0.5, 0.25 y 0.25 respectivamente, y se recorta al intervalo $[0, 100]$. En caso de ausencia de datos de HR o actividad, la función emplea valores neutros para mantener la computabilidad con información parcial.

  \item[\texttt{analyze\_sleep\_transitions(sleep\_states)}] Cuantifica las transiciones entre estados de sueño consecutivos y retorna una tupla $(\text{transitions}, \text{fragmentation\_index})$, donde el índice de fragmentación se expresa como transiciones por hora de sueño (asumiendo 1 muestra = 1 minuto). Un índice elevado sugiere sueño fragmentado o inestable. La función retorna $(\text{None}, \text{None})$ si la entrada contiene menos de dos muestras.

  \item[\texttt{detect\_sleep\_onset(sleep\_states, window\_size=10, threshold=0.8)}] Identifica el índice temporal correspondiente al inicio del sueño mediante un algoritmo de ventana deslizante. Se considera iniciado el sueño cuando al menos el 80\% de las muestras en una ventana de tamaño configurable (por defecto 10 minutos) corresponden a estados de sueño (valor $>0$). Retorna el índice de inicio o \texttt{None} si no se satisface el criterio en toda la serie.

  \item[\texttt{detect\_wake\_periods(sleep\_states, min\_duration=5)}] Detecta segmentos contiguos de vigilia (estado WAKE = 0) y retorna una lista de tuplas $(start\_index, duration)$ para aquellos periodos cuya duración supera el umbral mínimo configurable (por defecto 5 minutos). Esta información es útil para caracterizar despertares nocturnos y estimar eficiencia del sueño.
\end{description}

\subsection{Entradas y salidas}
El módulo sigue convenciones consistentes para el manejo de datos:

\begin{itemize}
  \item Las funciones aceptan secuencias numéricas en formato lista Python o{numpy.ndarray}; internamente se realiza conversión implícita cuando es necesario.
  \item Las funciones \texttt{calculate\_rmssd} y \texttt{calculate\_sdnn} retornan un valor \texttt{float} o \texttt{None} en caso de datos insuficientes.
  \item Las funciones \texttt{calculate\_stress\_score} y \texttt{calculate\_sleep\_quality} retornan un \texttt{float} en el intervalo $[0, 100]$.
  \item La función \texttt{analyze\_sleep\_transitions} retorna una tupla $(\text{int}, \text{float})$ o $(\text{None}, \text{None})$.
  \item La función \texttt{detect\_sleep\_onset} retorna un índice entero o \texttt{None}.
  \item La función \texttt{detect\_wake\_periods} retorna una lista de tuplas $(start\_index, duration)$.
\end{itemize}

\textbf{Importante:} El módulo no implementa funcionalidades de lectura de sensores ni parsing de protocolos. Se asume que los datos de entrada están previamente alineados temporalmente, libres de valores no numéricos y han pasado por etapas de preprocesamiento básico.

\subsection{Supuestos y consideraciones temporales}
El diseño del módulo se basa en los siguientes supuestos operacionales:

\begin{itemize}
  \item La serie \texttt{sleep\_states} está uniformemente muestreada con resolución de un minuto por muestra.
  \item Los umbrales, pesos de ponderación y valores máximos empleados en las normalizaciones son aproximaciones heurísticas derivadas de la literatura científica disponible. Estos parámetros requieren calibración específica con datos reales del hardware implementado y características de la población objetivo.
  \item Las funciones no aplican filtrado de artefactos de forma automática. Señales con picos espurios o artefactos de medición en los IBI pueden introducir sesgos significativos en las métricas RMSSD y SDNN.
\end{itemize}

\subsection{Casos límite y estrategias de validación}
El módulo implementa manejo básico de casos límite mediante retorno de valores \texttt{None} o puntuaciones neutras cuando los datos son insuficientes. No obstante, no se realizan operaciones de interpolación, imputación ni recuperación de series corruptas.

Para garantizar robustez en entornos de producción, se recomienda:

\begin{itemize}
  \item Validar las entradas antes de invocar las funciones: verificar tipo numérico (\texttt{dtype}), longitudes mínimas y eliminar outliers en secuencias de IBI mediante criterios fisiológicos (por ejemplo, rechazar IBI $<$ 300\,ms o $>$ 2000\,ms).
  \item Desarrollar un conjunto de pruebas unitarias que incluya:
  \begin{itemize}
    \item Ventanas con datos insuficientes.
    \item Episodios de sueño continuo sin interrupciones.
    \item Despertares breves y frecuentes.
    \item Ausencia de señales opcionales (HR, actividad).
    \item Valores extremos de HR para verificar la saturación correcta en \texttt{calculate\_stress\_score}.
  \end{itemize}
\end{itemize}

\subsection{Recomendaciones para uso en producción}
Para la transición del módulo a entornos operacionales se sugieren las siguientes mejoras:

\begin{enumerate}
  \item \textbf{Validación explícita de entradas:} Implementar funciones auxiliares que verifiquen tipo numérico, rangos fisiológicamente plausibles y conversión forzada a \texttt{np.array} con manejo de excepciones informativo.
  
  \item \textbf{Filtrado de artefactos:} Incorporar un filtrado ligero o truncado estadístico (por ejemplo, Tukey's fences) en las secuencias de IBI previo al cálculo de RMSSD, reduciendo así la sensibilidad a artefactos de medición.
  
  \item \textbf{Parametrización configurable:} Externalizar umbrales y pesos a un archivo de configuración (por ejemplo, \texttt{config/bed\_config.py}) para facilitar ajustes por entorno sin modificación del código fuente.
  
  \item \textbf{Documentación ejecutable:} Incluir un script demostrativo en \texttt{examples/demo\_analyzer.py} y un conjunto de pruebas con \texttt{pytest} en \texttt{tests/test\_analyzer.py} que cubra tanto casos de uso típicos como escenarios límite.
\end{enumerate}

\subsection{Formato de salida y consumo de resultados}
Los módulos consumidores del análisis pueden esperar los siguientes formatos de retorno:

\begin{itemize}
  \item \textbf{Métricas escalares:} Valor \texttt{float} o \texttt{None} (para RMSSD, SDNN, índice de estrés, calidad del sueño).
  \item \textbf{Análisis de transiciones:} Tupla $(\text{int}, \text{float})$ representando conteo de transiciones e índice de fragmentación.
  \item \textbf{Periodos de vigilia:} Lista de tuplas $(start\_index, duration)$ con índices temporales y duraciones en minutos.
\end{itemize}

Estos valores son directamente integrables en pipelines de logging, sistemas de visualización en tiempo real y algoritmos de fusión multimodal implementados en módulos superiores de la arquitectura.

\subsection{Ejemplo de uso}
A continuación se presenta un fragmento de código ilustrativo del uso típico del módulo:

\begin{lstlisting}[language=Python, caption={Ejemplo de invocación de funciones del módulo analyzer.py}, label={lst:analyzer_example}]
from analyzer import (
    calculate_rmssd, calculate_sdnn, calculate_stress_score,
    calculate_sleep_quality, analyze_sleep_transitions,
    detect_sleep_onset, detect_wake_periods
)

# Datos de ejemplo: IBI en milisegundos
ibi = [800, 810, 795, 805, 790]
rmssd = calculate_rmssd(ibi)
sdnn = calculate_sdnn(ibi)
stress = calculate_stress_score(hr=72, rmssd=rmssd, sdnn=sdnn)

sleep_states = [0, 0, 1, 1, 3, 3, 2, 2, 1, 0]
onset = detect_sleep_onset(sleep_states)
wake_periods = detect_wake_periods(sleep_states)
quality = calculate_sleep_quality(sleep_states)

print(f"RMSSD: {rmssd:.2f} ms")
print(f"Stress Score: {stress:.1f}/100")
print(f"Sleep Onset: minuto {onset}")
print(f"Sleep Quality: {quality:.1f}/100")
\end{lstlisting}

\subsection{Referencias sugeridas}
Para fundamentar las métricas y umbrales empleados en este módulo, se recomienda consultar:

\begin{itemize}
  \item Task Force of the European Society of Cardiology and the North American Society of Pacing and Electrophysiology. ``Heart rate variability: standards of measurement, physiological interpretation and clinical use.'' \emph{Circulation}, 1996.
  \item Ohayon et al. ``National Sleep Foundation's sleep quality recommendations.'' \emph{Sleep Health}, 2017.
\end{itemize}

\begin{figure}[htbp]
\centering
\begin{tikzpicture}[
    node distance=1.5cm and 0.8cm,
    block/.style={rectangle, draw, fill=blue!20, text width=2.8cm, text centered, rounded corners, minimum height=1cm, font=\scriptsize},
    input/.style={rectangle, draw, fill=green!20, text width=2.8cm, text centered, rounded corners, minimum height=0.9cm, font=\scriptsize},
    output/.style={rectangle, draw, fill=orange!20, text width=2.8cm, text centered, rounded corners, minimum height=0.9cm, font=\scriptsize},
    arrow/.style={-Stealth, thick}
]

% Fila 1 (izquierda a derecha)
\node[input] (ibi) at (0,0) {Entrada: IBI\\{\tiny intervalos inter-latido}};
\node[block, right=of ibi] (rmssd) {calculate\\rmssd()\\{\tiny raiz cuadratica}};
\node[block, right=of rmssd] (sdnn) {calculate\\sdnn()\\{\tiny desv. estandar}};
\node[input, right=of sdnn] (hr) {Entrada: HR\\{\tiny freq. cardiaca}};

% Fila 2 (derecha a izquierda)
\node[block, below=1.8cm of hr] (stress) {calculate\\stress score\\{\tiny indice 0-100}};
\node[output, left=of stress] (stress_out) {Salida:\\Estres\\{\tiny score}};
\node[input, left=of stress_out] (sleep_in) {Entrada:\\sleep states\\{\tiny 0=WAKE}\\{\tiny 1-3=SLEEP}};

% Fila 3 (izquierda a derecha)
\node[block, below=1.8cm of sleep_in] (quality) {calculate\\sleep quality\\{\tiny dist+HR+act}};
\node[block, right=of quality] (transitions) {analyze sleep\\transitions\\{\tiny fragmentacion}};
\node[block, right=of transitions] (onset) {detect sleep\\onset\\{\tiny ventana deslizante}};

% Fila 4 (derecha a izquierda)
\node[block, below=1.8cm of onset] (wake) {detect wake\\periods\\{\tiny seg. vigilia}};
\node[output, left=of wake] (quality_out) {Salida:\\Calidad\\{\tiny 0-100}};
\node[output, left=of quality_out] (trans_out) {Salida:\\Transiciones\\{\tiny count}};
\node[output, left=of trans_out] (periods_out) {Salida:\\Periodos\\{\tiny tuplas}};

% Conexiones fila 1
\draw[arrow] (ibi) -- (rmssd);
\draw[arrow] (rmssd) -- (sdnn);
\draw[arrow] (sdnn) -- (hr);

% Conexion hacia abajo
\draw[arrow] (hr) -- (stress);

% Conexiones fila 2
\draw[arrow] (rmssd.south) |- ([yshift=-0.5cm]rmssd.south) -| (stress.north);
\draw[arrow] (sdnn.south) |- ([yshift=-0.5cm]sdnn.south) -| (stress.north);
\draw[arrow] (stress) -- (stress_out);
\draw[arrow] (stress_out) -- (sleep_in);

% Conexion hacia abajo
\draw[arrow] (sleep_in) -- (quality);

% Conexiones fila 3
\draw[arrow] (quality) -- (transitions);
\draw[arrow] (transitions) -- (onset);

% Conexion hacia abajo
\draw[arrow] (onset) -- (wake);

% Conexiones fila 4
\draw[arrow] (wake) -- (quality_out);
\draw[arrow] (quality_out) -- (trans_out);
\draw[arrow] (trans_out) -- (periods_out);

% Conexiones de sleep_states a multiples funciones
\draw[arrow] (sleep_in.south) -- ([yshift=-0.4cm]sleep_in.south) -| (quality.north);
\draw[arrow] ([yshift=-0.4cm]sleep_in.south) -| (transitions.north);
\draw[arrow] ([yshift=-0.4cm]sleep_in.south) -| (onset.north);

% Entradas adicionales opcionales
\node[input, below=0.3cm of quality] (hr_vals) {{\tiny (opcional)}\\hr values};
\node[input, below=0.3cm of transitions] (activity) {{\tiny (opcional)}\\activity levels};

\draw[arrow, dashed] (hr_vals) -- (quality);
\draw[arrow, dashed] (activity) -- (quality);

% Titulo
\node[font=\large\bfseries, anchor=south] at ([yshift=0.2cm]ibi.north west -| current bounding box.center) {Modulo analyzer.py - Flujo de Procesamiento};

\end{tikzpicture}
\caption{Diagrama de bloques del modulo analyzer.py mostrando el flujo de datos tipo serpiente.}
\label{fig:analyzer_diagram}
\end{figure}

\section{Explicación Detallada del Bed Controller}

Este proyecto implementa un sistema de monitoreo y control automático inteligente para una cama ortopédica médica. El sistema está diseñado para mejorar la calidad del sueño mediante el ajuste dinámico de la temperatura del colchón basándose en el estado de sueño del usuario, sus signos vitales y principios científicos de termorregulación corporal. La arquitectura del sistema integra múltiples sensores médicos de grado profesional con actuadores controlados por GPIO en una Raspberry Pi, todo orquestado mediante algoritmos de análisis en tiempo real.

\subsection{Fundamento Científico}

El sistema se basa en investigaciones científicas que demuestran que durante el sueño, la temperatura corporal experimenta un descenso natural de aproximadamente \SI{0.8}{\celsius}. Este descenso térmico no es uniforme, sino que varía según la fase de sueño en la que se encuentre la persona. Durante el sueño ligero inicial, la temperatura desciende entre \SIrange{0.2}{0.4}{\celsius}. En la fase REM, donde la actividad cerebral se asemeja al estado de vigilia, la temperatura se mantiene relativamente estable. Durante el sueño profundo, se alcanza el descenso máximo de \SI{0.8}{\celsius}. El sistema aprovecha este conocimiento para anticipar y facilitar las transiciones naturales entre estados de sueño mediante el control preciso de la temperatura del microclima de la cama.

Adicionalmente, estudios de variabilidad térmica han demostrado que existe una tolerancia natural de \SIrange{\pm 1}{\pm 2}{\celsius} en el microclima de la cama sin afectar el confort. El sistema utiliza estos parámetros para establecer rangos de confort personalizados según el estado de sueño detectado, evitando cambios bruscos que puedan interrumpir el descanso.

\subsection{Arquitectura de Sensores}

El sistema integra cuatro sensores principales que trabajan de manera coordinada para obtener una imagen completa del estado fisiológico del usuario y las condiciones ambientales.

\subsubsection{Sensor MAX30102}

El MAX30102 es un sensor óptico de oximetría de pulso que utiliza fotopletismografía para medir la frecuencia cardíaca y la saturación de oxígeno en sangre. Se comunica mediante protocolo I\textsuperscript{2}C en la dirección \texttt{0x57}. Este sensor es fundamental para la detección del estado de sueño, ya que la frecuencia cardíaca varía significativamente entre las diferentes fases del sueño. Durante el sueño profundo, la frecuencia cardíaca puede descender por debajo de 55~BPM, mientras que durante el sueño REM puede elevarse a niveles similares a los de vigilia (por encima de 70~BPM). El sensor también proporciona mediciones de saturación de oxígeno (SpO\textsubscript{2}), críticas para detectar posibles eventos de apnea del sueño. El sistema genera alertas cuando el SpO\textsubscript{2} cae por debajo del 90\%, indicando una posible condición de hipoxemia que requiere atención médica.

La implementación incluye validación de datos, verificando que el sensor detecte correctamente la presencia del dedo del usuario. Cuando no se detecta un dedo válido, el sistema recurre a valores simulados para mantener la operación continua, aunque con capacidades de análisis reducidas.

\subsubsection{Sensor HTU21D}

El HTU21D es un sensor de temperatura y humedad digital de alta precisión que se instala directamente en el colchón de la cama, comunicándose por I\textsuperscript{2}C en la dirección \texttt{0x40}. Este sensor es el componente crítico del sistema de control térmico, proporcionando lecturas en tiempo real de la temperatura del microclima de la cama. El sistema valida que las lecturas estén dentro del rango operativo seguro de \SIrange{15}{30}{\celsius} antes de utilizarlas para el control de válvulas.

El HTU21D también mide la humedad relativa del ambiente de la cama, un parámetro importante para el confort térmico general, aunque no se utiliza directamente en el algoritmo de control de temperatura. La combinación de temperatura y humedad proporciona información valiosa sobre las condiciones generales del microclima de la cama.

\subsubsection{Sensor AHT10}

El AHT10 es un sensor de temperatura corporal ubicado en una pulsera que lleva el usuario, comunicándose por I\textsuperscript{2}C en la dirección \texttt{0x38}. Este sensor es fundamental para detectar desviaciones de la temperatura corporal normal. El rango normal de temperatura corporal se establece entre \SIrange{35.0}{42.0}{\celsius}, con una temperatura basal promedio de \SI{36.8}{\celsius} según estudios clínicos.

El sistema implementa lógica avanzada de compensación térmica basada en las lecturas del AHT10. Cuando se detecta una temperatura corporal elevada (hipertermia), superior a \SI{37.5}{\celsius}, el sistema ajusta automáticamente la temperatura objetivo de la cama hacia abajo para ayudar a la termorregulación natural del cuerpo. En casos de fiebre (temperatura corporal $\geq$ \SI{38.0}{\celsius}), el ajuste de enfriamiento es más agresivo, con un descenso progresivo que puede alcanzar hasta \SI{3}{\celsius} más el exceso sobre \SI{38}{\celsius} multiplicado por 0.5. Inversamente, cuando se detecta hipotermia leve (temperatura corporal $\leq$ \SI{35.5}{\celsius}), el sistema activa un calentamiento progresivo para ayudar al cuerpo a recuperar su temperatura normal.

\subsubsection{Acelerómetro MMA8452Q}

El MMA8452Q es un acelerómetro triaxial de alta sensibilidad que detecta los movimientos corporales del usuario durante el sueño. Se comunica por I\textsuperscript{2}C en la dirección \texttt{0x1D} y proporciona lecturas de aceleración en los tres ejes ($X$, $Y$, $Z$). El sistema procesa estas lecturas para calcular un índice de actividad que es fundamental para la clasificación del estado de sueño.

El algoritmo de procesamiento de actividad implementa un modelo de integración temporal con decaimiento exponencial. Cada movimiento súbito incrementa el nivel de actividad instantáneamente, pero si no hay movimientos subsecuentes, la actividad decae gradualmente siguiendo una constante de tiempo configurable. Este comportamiento modela la forma en que percibimos la actividad física: un movimiento reciente tiene más relevancia que uno ocurrido hace varios segundos.

El cálculo específico compara la diferencia promedio de aceleración en los tres ejes con un umbral de actividad configurable. Cuando la diferencia supera el umbral, se registra un ``pico'' de actividad y el nivel se incrementa según un factor de fuerza de pico. Entre picos, el sistema espera un tiempo de retardo antes de comenzar el decaimiento exponencial, lo que evita que movimientos rápidos consecutivos se interpreten como períodos de calma.

\subsection{Detección de Estados de Sueño}

La clasificación del estado de sueño es el algoritmo central del sistema, combinando datos de actividad física y frecuencia cardíaca en un modelo de fusión sensorial. El sistema reconoce cuatro estados principales: despierto (\texttt{WAKE}), sueño ligero (\texttt{LIGHT\_SLEEP}), sueño REM (\texttt{REM\_SLEEP}) y sueño profundo (\texttt{DEEP\_SLEEP}).

\subsubsection{Clasificación por Actividad}

El primer nivel de clasificación utiliza el índice de actividad calculado desde el acelerómetro. Se establecen tres umbrales principales: 

\begin{itemize}[noitemsep]
    \item Si la actividad es menor a 0.01, se clasifica como actividad compatible con sueño profundo.
    \item Si está entre 0.01 y 0.008, se marca como ``\texttt{REM\_OR\_LIGHT}'' para análisis posterior.
    \item Si la actividad está entre 0.008 y 0.7, se clasifica como sueño ligero.
    \item Cualquier actividad superior a 0.7 indica estado de vigilia.
\end{itemize}

\subsubsection{Clasificación por Frecuencia Cardíaca}

Paralelamente, el sistema clasifica el estado basándose exclusivamente en la frecuencia cardíaca:

\begin{itemize}[noitemsep]
    \item Una frecuencia cardíaca inferior a 55~BPM sugiere sueño profundo.
    \item Frecuencias entre 55 y 75~BPM son compatibles con sueño ligero.
    \item Frecuencias superiores a 75~BPM indican vigilia o sueño REM.
\end{itemize}

\subsubsection{Fusión de Datos}

El algoritmo de fusión combina ambas clasificaciones mediante reglas lógicas basadas en el conocimiento fisiológico del sueño. Si tanto la actividad como la frecuencia cardíaca indican sueño profundo, el sistema clasifica con alta confianza como \texttt{DEEP\_SLEEP}. Este es el caso más inequívoco.

La detección de sueño REM es más compleja y representa una de las características más avanzadas del sistema. El sueño REM se caracteriza por una paradoja fisiológica: alta actividad cerebral (reflejada en frecuencia cardíaca elevada, típicamente $\geq$ 65~BPM) combinada con atonía muscular (parálisis temporal de los músculos voluntarios). El sistema detecta REM cuando la actividad física es muy baja (micro-movimientos menores a 0.008) pero la frecuencia cardíaca es relativamente alta. Esto distingue el REM del sueño profundo (baja actividad Y baja frecuencia cardíaca) y del estado despierto (alta actividad Y alta frecuencia cardíaca).

Cuando los indicadores son ambiguos o contradictorios, el sistema aplica reglas de desambiguación conservadoras. Por ejemplo, si la actividad sugiere sueño ligero pero la frecuencia cardíaca es muy alta, se clasifica como vigilia, asumiendo que la persona está despierta pero relativamente quieta.

\subsection{Sistema de Control de Temperatura}

El control de temperatura es el actuador principal del sistema, diseñado para mantener un microclima óptimo que facilite y preserve el sueño de calidad.

\subsubsection{Cálculo de Temperatura Objetivo}

El sistema mantiene zonas de confort diferenciadas para cada estado de sueño, basadas en investigación científica sobre termorregulación:

\begin{itemize}[noitemsep]
    \item \textbf{Vigilia:} \SIrange{21}{25}{\celsius}, reflejando la temperatura corporal basal alta típica del estado despierto.
    \item \textbf{Sueño ligero:} \SIrange{19}{23}{\celsius} para facilitar el descenso térmico inicial.
    \item \textbf{Sueño REM:} \SIrange{20}{24}{\celsius}, ligeramente más cálida debido a la actividad cerebral elevada.
    \item \textbf{Sueño profundo:} \SIrange{17}{21}{\celsius}, facilitando el descenso térmico máximo de \SI{0.8}{\celsius}.
\end{itemize}

El algoritmo calcula primero una temperatura base como el punto medio de la zona de confort del estado actual. Luego aplica un offset térmico científico: \SI{-0.3}{\celsius} para sueño ligero, \SI{0}{\celsius} para REM, \SI{-0.8}{\celsius} para sueño profundo, y \SI{0}{\celsius} para vigilia.

\subsubsection{Ajustes por Temperatura Ambiente}

El sistema ajusta la temperatura objetivo según la temperatura ambiente medida por el MAX30102:

\begin{itemize}[noitemsep]
    \item Si la temperatura ambiente supera \SI{25}{\celsius}, se aplica un ajuste de enfriamiento de \SI{-1.0}{\celsius}.
    \item Si la temperatura ambiente es inferior a \SI{15}{\celsius}, se aplica un ajuste de calentamiento de \SI{+1.0}{\celsius}.
\end{itemize}

\subsubsection{Compensación por Temperatura Corporal}

El ajuste más sofisticado se basa en la temperatura corporal del AHT10. El sistema detecta desviaciones de la temperatura corporal normal (\SI{36.8}{\celsius}) y ajusta la cama para ayudar a la termorregulación:

\begin{itemize}[noitemsep]
    \item \textbf{Fiebre} ($\geq$ \SI{38.0}{\celsius}): Enfriamiento agresivo de hasta \SI{-3.0}{\celsius} más un componente proporcional.
    \item \textbf{Hipertermia leve} (\SIrange{37.5}{38.0}{\celsius}): Ajuste moderado de \SI{-1.5}{\celsius} más un factor proporcional.
    \item \textbf{Hipotermia leve} ($\leq$ \SI{35.5}{\celsius}): Calentamiento progresivo de \SI{+2.0}{\celsius} más un componente proporcional.
\end{itemize}

\subsubsection{Control Predictivo}

Una característica avanzada del sistema es el control predictivo basado en el análisis de tendencias térmicas. El sistema mantiene un historial de las últimas 30 lecturas de temperatura (aproximadamente 10 minutos) y calcula la velocidad de cambio térmico en \si{\celsius\per\minute}. Con esta información, el algoritmo predice la temperatura en los próximos 5 minutos mediante extrapolación lineal.

Si la predicción indica que se alcanzará una temperatura fuera de los límites seguros, el sistema actúa preventivamente antes de que ocurra el problema. Este enfoque anticipativo mejora significativamente la estabilidad térmica y evita que el usuario experimente temperaturas incómodas.

\subsubsection{Análisis de Estabilidad Térmica}

El sistema calcula continuamente la varianza de las últimas 10 lecturas de temperatura. Una varianza alta (superior a un umbral de tolerancia configurable) indica inestabilidad térmica y activa un modo de estabilización que utiliza tolerancias más estrictas para el control de válvulas. Cuando la varianza es muy baja (menor a \SI{0.1}{\celsius\squared}), el sistema reporta estabilidad térmica óptima.

\subsubsection{Suavizado de Transiciones}

Para evitar cambios térmicos bruscos que puedan interrumpir el sueño, el sistema implementa un algoritmo de suavizado que limita la velocidad máxima de cambio de la temperatura objetivo. El cambio máximo permitido por ciclo de control se calcula como una fracción de la tolerancia de varianza térmica. Si el cambio calculado excede este límite, se aplica solo el cambio máximo permitido, distribuyendo la transición térmica a lo largo de múltiples ciclos.

\subsection{Control de Válvulas}

El sistema controla dos válvulas eléctricas de 220~V mediante relés conectados a pines GPIO de la Raspberry Pi: una válvula de agua caliente y una válvula de agua fría. Existe también un relé de seguridad general.

\subsubsection{Lógica de Control}

El algoritmo de control de válvulas implementa un controlador de banda muerta (\textit{deadband controller}). Se define una tolerancia térmica (típicamente $\pm$\SI{0.5}{\celsius}) alrededor de la temperatura objetivo:

\begin{itemize}[noitemsep]
    \item Si la temperatura actual está dentro de esta banda de tolerancia, ambas válvulas se cierran.
    \item Si la temperatura actual es inferior al límite inferior, se abre la válvula de agua caliente.
    \item Si la temperatura actual supera el límite superior, se abre la válvula de agua fría.
\end{itemize}

\subsubsection{Ajuste Dinámico de Tolerancia}

El sistema ajusta dinámicamente la tolerancia del controlador según el estado de sueño:

\begin{itemize}[noitemsep]
    \item \textbf{Sueño profundo:} Tolerancia ampliada en 50\% (de $\pm$\SI{0.5}{\celsius} a $\pm$\SI{0.75}{\celsius}).
    \item \textbf{Sueño REM:} Tolerancia reducida en 20\% (a $\pm$\SI{0.4}{\celsius}).
\end{itemize}

\subsubsection{Medidas de Seguridad}

El sistema implementa múltiples capas de seguridad críticas:

\begin{enumerate}[noitemsep]
    \item \textbf{Interlock de Válvulas:} Previene la apertura simultánea de ambas válvulas. Si se detecta esta condición, el sistema bloquea ambas válvulas y registra una alerta de seguridad.
    
    \item \textbf{Rangos de Temperatura Absolutos:} Todas las temperaturas objetivo se limitan a un rango absoluto de \SIrange{15}{30}{\celsius}.
    
    \item \textbf{Parada de Emergencia:} El método \texttt{emergency\_stop()} cierra inmediatamente todas las válvulas cuando se detectan condiciones críticas como frecuencias cardíacas peligrosamente altas ($>$120~BPM) o bajas ($<$40~BPM).
    
    \item \textbf{Validación de Sensores:} Antes de utilizar cualquier lectura de sensor, el sistema valida que el valor esté dentro de rangos físicamente plausibles.
\end{enumerate}

\subsubsection{Algoritmo de Confianza}

Cada indicador aporta un porcentaje de confianza al cálculo final. La confianza total se calcula como la suma ponderada de todos los indicadores activos. El sistema implementa histéresis en la detección:

\begin{itemize}[noitemsep]
    \item \textbf{Umbral para detectar entrada:} 60\% de confianza.
    \item \textbf{Umbral para detectar salida:} 20\% de confianza.
\end{itemize}

Esta asimetría reduce falsos positivos en la detección de entrada.

\subsection{Análisis Avanzado de Sueño}

El sistema implementa un conjunto sofisticado de algoritmos de análisis que proporcionan métricas cuantitativas de calidad de sueño y estrés fisiológico.

\subsubsection{Variabilidad de Frecuencia Cardíaca (HRV)}

El sistema calcula métricas estándar de HRV:

\begin{itemize}[noitemsep]
    \item \textbf{RMSSD} (\textit{Root Mean Square of Successive Differences}): Mide la variabilidad de corto plazo entre latidos consecutivos. Un RMSSD alto indica buena capacidad de adaptación del sistema nervioso autónomo.
    
    \item \textbf{SDNN} (\textit{Standard Deviation of NN intervals}): Mide la variabilidad general de todos los intervalos entre latidos. Valores más altos se asocian con mejor salud cardiovascular.
\end{itemize}

\subsubsection{Puntuación de Estrés}

El sistema calcula una puntuación de estrés de 0--100 combinando frecuencia cardíaca actual y métricas de HRV. Una frecuencia cardíaca elevada con HRV reducido indica alto estrés fisiológico:

\begin{itemize}[noitemsep]
    \item \textbf{Estrés alto:} Puntuación $>$ 70
    \item \textbf{Estrés medio:} Puntuación 40--70
    \item \textbf{Estrés bajo:} Puntuación $<$ 40
\end{itemize}

\subsubsection{Calidad de Sueño}

La métrica de calidad de sueño se calcula cuando hay suficiente historial de datos (al menos 30 muestras, equivalente a 1 hora de monitoreo). El algoritmo analiza la distribución de estados de sueño y compara con patrones ideales:

\begin{itemize}[noitemsep]
    \item Aproximadamente 20\% de sueño profundo
    \item 20--25\% de sueño REM
    \item El resto en sueño ligero
    \item Menos del 5\% de vigilia
\end{itemize}

La puntuación final de 0--100 se clasifica como:

\begin{itemize}[noitemsep]
    \item \textbf{Excelente:} $>$ 80
    \item \textbf{Buena:} 60--80
    \item \textbf{Regular:} 40--60
    \item \textbf{Deficiente:} $<$ 40
\end{itemize}

\subsubsection{Detección de Inicio de Sueño}

El sistema detecta automáticamente el momento en que el usuario transiciona de vigilia a sueño. La latencia de inicio de sueño (tiempo desde acostarse hasta dormirse) es un indicador importante:

\begin{itemize}[noitemsep]
    \item \textbf{Normal:} $<$ 15 minutos
    \item \textbf{Elevada:} 15--30 minutos
    \item \textbf{Muy elevada:} $>$ 30 minutos (posible insomnio)
\end{itemize}

\subsubsection{Análisis de Fragmentación de Sueño}

Cada 5 minutos, el sistema analiza las transiciones entre estados de sueño. El algoritmo calcula un índice de fragmentación normalizado por hora:

\begin{itemize}[noitemsep]
    \item \textbf{Muy consolidado:} $<$ 10 transiciones/hora
    \item \textbf{Consolidado:} 10--15 transiciones/hora
    \item \textbf{Ligeramente fragmentado:} 15--25 transiciones/hora
    \item \textbf{Muy fragmentado:} $>$ 25 transiciones/hora
\end{itemize}

\subsubsection{Detección de Despertares Nocturnos}

El sistema identifica períodos de vigilia durante el sueño que excedan una duración mínima configurable (típicamente 6--10 segundos). Se registra el número de despertares y el tiempo total en estado de vigilia. Más de 2 despertares o más de 30 minutos acumulados despierto se consideran indicadores de sueño interrumpido.

\subsubsection{Reporte Final de Sueño}

Al finalizar una sesión de monitoreo, el sistema genera un reporte completo que incluye:

\begin{enumerate}[noitemsep]
    \item \textbf{Duración Total:} Tiempo total de monitoreo desde que se detectó presencia.
    \item \textbf{Distribución de Estados:} Porcentajes y tiempos absolutos en cada estado.
    \item \textbf{Calidad Final de Sueño:} Puntuación 0--100 con interpretación cualitativa.
    \item \textbf{Análisis de Fragmentación:} Número total de transiciones e índice por hora.
    \item \textbf{Latencia de Sueño:} Tiempo hasta el inicio del sueño con evaluación.
    \item \textbf{Despertares Nocturnos:} Número de despertares y tiempo total despierto.
    \item \textbf{Recomendaciones Personalizadas:} Basadas en los resultados del análisis.
\end{enumerate}

\subsection{Integración y Flujo de Ejecución}

El sistema opera mediante un bucle asíncrono principal que se ejecuta cada 2 segundos. En cada iteración:

\begin{enumerate}[noitemsep]
    \item Se leen todos los sensores (MAX30102, HTU21D, AHT10, MMA8452Q).
    \item Se validan las lecturas y se filtran valores espurios.
    \item Se calcula el nivel de actividad integrado desde el acelerómetro.
    \item Se actualiza el detector de presencia con los datos actuales.
    \item Si se detecta presencia, se clasifica el estado de sueño actual.
    \item Se actualizan los historiales de datos para análisis temporal.
    \item Se calcula la temperatura objetivo basada en estado de sueño y compensaciones.
    \item Se ejecuta el controlador de válvulas para alcanzar la temperatura objetivo.
    \item Cada 30 segundos se ejecuta el análisis avanzado (HRV, estrés, calidad).
    \item Se muestra en consola el estado actual completo del sistema.
\end{enumerate}

Este ciclo continúa hasta que el usuario interrumpe el programa o se detecta una condición de error crítica. Al finalizar, se ejecuta el procedimiento de limpieza que cierra todas las válvulas, libera los recursos GPIO y genera el reporte final.

\subsection{Manejo de Errores y Robustez}

El sistema implementa múltiples capas de manejo de errores para garantizar operación continua incluso con fallos parciales de hardware:

\begin{itemize}[noitemsep]
    \item Cada sensor está envuelto en bloques \texttt{try-except} que capturan excepciones y permiten que el sistema continúe con valores simulados o el último valor válido conocido.
    \item Los pines GPIO se configuran con manejo de advertencias desactivado para evitar mensajes espurios en reconfiguración.
    \item El destructor de la clase asegura que incluso si el programa termina abruptamente, se ejecute la limpieza de recursos y la parada de emergencia de válvulas.
\end{itemize}

\newgeometry{left=1cm, right=0cm, top=2cm, bottom=2cm}
\thispagestyle{empty}

\begin{figure}[htbp]
\centering
\resizebox{\linewidth}{!}{%
\begin{tikzpicture}[
    node distance=1.0cm and 0.6cm,
    block/.style={rectangle, draw, fill=blue!18, text width=2.2cm, text centered, rounded corners, minimum height=0.8cm, font=\scriptsize},
    input/.style={rectangle, draw, fill=green!18, text width=2.2cm, text centered, rounded corners, minimum height=0.7cm, font=\scriptsize},
    output/.style={rectangle, draw, fill=orange!18, text width=2.2cm, text centered, rounded corners, minimum height=0.7cm, font=\scriptsize},
    arrow/.style={-Stealth, line width=0.7pt}
]

% Fila 1 (sensores, izquierda a derecha)
\node[input] (max) at (0,0) {MAX30102\\{\tiny HR / SpO2 / Ambient}};
\node[input, right=of max] (mma) {MMA8452Q\\{\tiny Acelerómetro}};
\node[input, right=of mma] (htu) {HTU21D\\{\tiny Temp cama / Humedad}};
\node[input, right=of htu] (aht) {AHT10 (opt.)\\{\tiny Temp corporal}};
\node[input, right=of aht] (presence) {presence\_detector\\{\tiny Presencia}};

% Fila 2 (fusión)
\node[block, below=1.6cm of mma] (fusion) {process\_sensor\_data\\{\tiny fusión + presencia + historiales}};

% Conexiones sensores -> fusión
\draw[arrow] (max) -- (fusion);
\draw[arrow] (mma) -- (fusion);
\draw[arrow] (htu) -- (fusion);
\draw[arrow] (aht) -- (fusion);
\draw[arrow] (presence) -- (fusion);

% Historiales (izquierda centro)
\node[output, left=1.0cm of fusion] (store) {Historiales\\{\tiny hr / activity / sleep / temps}};
\draw[arrow] (fusion.west) -- (store.east);

% Detección de sueño (izq medio, serpiente)
\node[block, below=1.6cm of store, xshift=-0.6cm] (sleepdet) {detect\_sleep\_state\\{\tiny actividad + HR}};
\draw[arrow] (fusion) |- (sleepdet);

% Análisis avanzado (centro derecha)
\node[block, right=2.9cm of sleepdet] (analyzer) {perform\_advanced\_analysis\\{\tiny HRV / stress / quality}};
\draw[arrow] (sleepdet) -- ++(0.4cm,0) |- (analyzer.west);
\draw[arrow] (store.south) -- ++(0,-0.5cm) -| (analyzer.west);

% Cálculo temperatura objetivo (abajo-centro)
\node[block, below=1.6cm of analyzer, xshift=-0.1cm] (target) {calculate\_target\_temperature\\{\tiny comfort + ambient + body}};
\draw[arrow] (analyzer) -- (target);

% Tendencias térmicas (derecha de target)
\node[block, right=2.1cm of target] (trend) {analyze\_thermal\_trends\\{\tiny predicción / varianza}};
\draw[arrow] (target) -- (trend);

% Control científico (centro inferior)
\node[block, below=1.6cm of trend, xshift=-0.4cm] (apply) {apply\_scientific\_thermal\_control\\{\tiny predictivo + tolerancias}};
\draw[arrow] (trend) -- (apply);
\draw[arrow] (target) |- (apply);

% Decisión de válvulas (derecha)
\node[block, right=3.2cm of apply] (control) {control\_valves\\{\tiny heat / cool / maintain}};
\draw[arrow] (apply) -- (control);

% Set valves -> actuadores
\node[block, right=of control] (setvalve) {set\_valve\_states\\{\tiny safety: no ambas}};
\draw[arrow] (control) -- (setvalve);

\node[block, below=0.7cm of setvalve] (gpio) {GPIO / Relés\\{\tiny HOT / COLD / SAFETY}};
\draw[arrow] (setvalve) -- (gpio);

\node[output, below=0.7cm of gpio] (actuators) {Actuadores\\{\tiny Válvulas / Seguridad}};
\draw[arrow] (gpio) -- (actuators);

% Emergency stop (izq de actuadores)
\node[block, left=2.0cm of actuators] (emergency) {emergency\_stop\\{\tiny cerrar todo}};
\draw[arrow] (fusion.south) |- (emergency.north);
\draw[arrow, red, thick] (emergency.east) -- ++(0.6cm,0) |- (gpio.west);

% Reporte final (abajo-izq)
\node[block, below=1.8cm of sleepdet, xshift=-0.1cm] (report) {generate\_sleep\_report\\{\tiny resumen / fragmentación / recomendaciones}};
\draw[arrow] (analyzer.south) -- ++(0,-0.4cm) -| (report.north);
\draw[arrow] (store.south) -- ++(0,-0.6cm) -| (report.east);

% Bucle de monitoreo (arriba-izq)
\node[input, above=0.6cm of max, xshift=-0.3cm] (start) {start\_monitoring\\{\tiny bucle 2s}};
\draw[arrow] (start) -- ++(0.6cm,0) |- (fusion.north);

% Conexiones auxiliares (discretas, en línea)
\node[input, below=0.4cm of target] (bodytemp) {{\tiny (opt)}\\AHT10 body};
\draw[arrow, dashed] (bodytemp) -- (target);

\node[input, below=0.4cm of analyzer] (hrvals) {{\tiny (opt)}\\HR history};
\draw[arrow, dashed] (hrvals) -- (analyzer);

% Leyenda compacta
\node[font=\footnotesize, anchor=north] at ([yshift=-1.1cm]actuators.south) {
  \begin{tabular}{l}
    Azul = Módulos / funciones \\
    Verde = Sensores / Entradas \\
    Naranja = Salidas / Historiales
  \end{tabular}
};

% Título muy compacto
\node[font=\normalsize\bfseries, anchor=south] at ([yshift=0.25cm]max.north -| current bounding box.center) {Smart Bed -- Diagrama (estrecho)};

\end{tikzpicture}%
}
\caption{Diagrama compacto (serpiente) del sistema de cama inteligente — versión ajustada para ancho de página.}
\label{fig:smartbed_diagram_narrow}
\end{figure}
\restoregeometry

\begin{thebibliography}{9}

\bibitem{REM}
Clininca Universidad de Navarra, 
\textit{¿Qué es el sueño REM?}, 
Disponible en:\url{https://www.cun.es/diccionario-medico/terminos/sueno-rem#:~:text=El%20sueño%20REM%20es%20una,de%20actividad%20cerebral%20y%20fisiológica.}

\bibitem{Cama inteligente}
Sleep Number, \textit{Una cama inteligente que monitorea los ronquidos y cambia de temperatura sola}, 
Disponible en:\url{https://www.infobae.com/america/tecno/2022/01/06/una-cama-inteligente-que-monitorea-los-ronquidos-y-se-calienta-sola}

\bibitem{refrigeración}
Radal., \textit{PELTIER TEC1-12706 Cómo montar una mini nevera produce flores de hielo}, 
Disponible en:\url{https://www.youtube.com/watch?v=C9LASZjX1Wc}

\bibitem{programación}
Simon Howroyd., \textit{ESP-IDF in CPP 10: Non-volatile Storage and Templates}, 
Disponible en:\url{https://www.youtube.com/watch?v=2C3rD9wiXFw&list=PLowIV8ZSSsAWjoPJomVi_s1ZMghc9gNn9}

\bibitem{tohoku}
Tohoku Fukushi University, 
\textit{Effects of thermal environment on sleep and circadian rhythm}, 
Disponible en: \url{https://jphysiolanthropol.biomedcentral.com/articles/10.1186/1880-6805-31-14#Abs1}

\end{thebibliography}

\end{document}

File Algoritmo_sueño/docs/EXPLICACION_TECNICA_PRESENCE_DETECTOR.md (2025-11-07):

# EXPLICACIÓN TÉCNICA DETALLADA - PRESENCE DETECTOR

## ARQUITECTURA GENERAL DEL SISTEMA

El módulo `presence_detector.py` implementa un sistema de detección de presencia en cama inteligente mediante fusión multi-sensor, utilizando cinco indicadores independientes que se combinan para generar un nivel de confianza global

## CLASE PRINCIPAL: BedPresenceDetector

### Atributos de Estado

**Estado de presencia actual:**
- `bed_occupied` (bool): Bandera que indica si la cama está ocupada actualmente
- `presence_confidence` (float): Nivel de confianza de presencia expresado en porcentaje (0-100)
- `presence_history` (list): Buffer circular que almacena los últimos N valores de confianza para análisis temporal
- `presence_start_time` (float): Timestamp Unix del momento en que se detectó entrada a la cama

**Valores de referencia (baseline):**
- `baseline_temperature` (float): Temperatura de referencia de la cama vacía, se actualiza dinámicamente cuando no hay presencia
- `baseline_activity` (float): Nivel de actividad de referencia (actualmente no utilizado)

**Parámetros configurables:**
- `confidence_threshold_enter`: Umbral de confianza requerido para detectar entrada (por defecto 60%)
- `confidence_threshold_exit`: Umbral de confianza bajo el cual se detecta salida (por defecto 20%)
- `thermal_threshold`: Incremento de temperatura sobre baseline para considerar presencia térmica (por defecto 1.5°C)
- `activity_threshold`: Nivel mínimo de actividad del acelerómetro para detectar movimiento (por defecto 0.001)
- `hr_min` y `hr_max`: Rango válido de frecuencia cardíaca (40-150 BPM)
- `history_size`: Tamaño del buffer de historial de confianza (30 muestras)
- `confirmation_time`: Número de muestras consecutivas de baja confianza requeridas para confirmar salida (15 muestras)

Todos estos parámetros se cargan desde el módulo `bed_config`, permitiendo ajuste sin modificar el código

## MÉTODO PRINCIPAL: detect_presence()

### Flujo de Procesamiento

El método recibe un diccionario `sensor_data` con las siguientes claves:
- `bed_temperature`: Lectura actual del sensor HTU21D
- `activity`: Magnitud del vector de aceleración del MMA8451
- `heart_rate`: Frecuencia cardíaca calculada por el MAX30102
- `hr_valid`: Booleano indicando si la medición de HR es confiable
- `finger_present`: Booleano indicando contacto físico con el sensor óptico

### Sistema de Puntuación Multi-Indicador

**1. INDICADOR TÉRMICO (máximo 40 puntos)**

Compara la temperatura actual con el baseline almacenado
```
temp_elevation = bed_temp - baseline_temperature
```

Criterios de puntuación:
- Si `temp_elevation > thermal_threshold`: otorga 30 puntos base
- Si `temp_elevation > thermal_threshold * 2`: otorga 10 puntos adicionales (total 40)

Fundamento: La presencia humana eleva la temperatura de la cama entre 1.5°C y 4°C debido al calor corporal, siendo uno de los indicadores más confiables de presencia sostenida

**2. INDICADOR DE MOVIMIENTO (máximo 25 puntos)**

Analiza la actividad del acelerómetro en tiempo real

Criterios de puntuación:
```
activity_score = min(25, int(activity * 25 / 0.1))
```

La puntuación escala linealmente con el nivel de actividad hasta un máximo de 25 puntos cuando la actividad alcanza 0.1

Fundamento: Los micro-movimientos durante el sueño (cambios de posición, respiración) generan actividad detectable por el acelerómetro, aunque una persona dormida puede permanecer inmóvil por períodos prolongados

**3. INDICADOR CARDIOVASCULAR (máximo 40 puntos)**

Valida la presencia de señal de frecuencia cardíaca válida

Criterios de puntuación:
- Si HR es válida y está en rango 40-150 BPM: otorga 35 puntos
- Si HR está en rango óptimo de sueño (50-80 BPM): otorga 5 puntos adicionales (total 40)

Fundamento: La detección de frecuencia cardíaca válida confirma presencia humana con alta certeza, ya que requiere contacto directo con el sensor óptico y flujo sanguíneo detectable

**4. INDICADOR DE CONTACTO (máximo 20 puntos)**

Detecta contacto físico con el sensor MAX30102 mediante análisis de la señal infrarroja

Criterios de puntuación:
- Si `finger_present == True`: otorga 20 puntos

Fundamento: El sensor óptico detecta contacto cuando la señal infrarroja reflejada supera un umbral mínimo, indicando que hay tejido biológico en contacto con el sensor

**5. INDICADOR TEMPORAL (máximo 10 puntos)**

Analiza la consistencia de la presencia en una ventana temporal deslizante

Criterios de puntuación:
```
avg_confidence = sum(presence_history[-5:]) / 5
```
- Si el promedio de los últimos 5 valores supera 50%: otorga 10 puntos

Fundamento: La presencia real en la cama genera señales consistentes en el tiempo, mientras que las falsas detecciones tienden a ser esporádicas

### Cálculo de Confianza Global

El puntaje final se calcula como suma de todos los indicadores activos, limitado a un máximo de 100%:
```
confidence = min(sum(all_indicators), 100)
```

Esta arquitectura permite que ningún sensor individual sea crítico, el sistema es tolerante a fallos de sensores individuales mientras múltiples indicadores estén activos

## MECANISMO DE HISTÉRESIS

### Propósito

Evitar transiciones rápidas (flapping) entre estados de presencia cuando las señales están cerca de los umbrales, proporcionando estabilidad al sistema

### Implementación en _update_presence_state()

**Detección de ENTRADA (vacía → ocupada):**
- Condición: `confidence >= threshold_enter` (60% por defecto)
- Acción inmediata: cambia estado a ocupada y registra timestamp

**Detección de SALIDA (ocupada → vacía):**
- Condición primaria: `confidence <= threshold_exit` (20% por defecto)
- Condición secundaria: requiere confirmación temporal
- Verificación: los últimos `confirmation_time` valores del historial deben ser todos ≤ 30%
- Acción: solo después de confirmar baja confianza sostenida cambia a vacía

Esta asimetría (entrada rápida, salida lenta) es intencional para evitar falsas detecciones de salida durante momentos de quietud prolongada (sueño profundo)

## GESTIÓN DE BASELINE TÉRMICO

### Inicialización

Al arrancar el sistema, `baseline_temperature` se inicializa con `None`, la primera lectura térmica se toma automáticamente como referencia inicial

### Actualización Dinámica (método update_baseline_temperature)

Solo se actualiza cuando `bed_occupied == False`, utilizando filtro de paso bajo con factor de suavizado α = 0.05:
```
baseline = (1 - α) * baseline_old + α * temp_current
```

Este filtro exponencial permite que el baseline se adapte lentamente a cambios de temperatura ambiente sin reaccionar a fluctuaciones breves

### Calibración Manual (método calibrate_baseline)

Permite establecer un baseline preciso mediante múltiples lecturas:
- Toma N lecturas durante un período definido (típicamente 5 minutos)
- Calcula la mediana (no la media) para eliminar outliers
- Reemplaza el baseline con este valor calibrado

El uso de la mediana es crucial para robustez contra lecturas anómalas

## MÉTODOS DE UTILIDAD Y DEBUGGING

**get_presence_summary()**

Retorna un diccionario con el estado global del detector, útil para monitoreo y logging

**get_detailed_indicators()**

Proporciona análisis granular de cada indicador individual con sus valores actuales, umbrales y estado de activación, esencial para debug y ajuste de parámetros

**reset_presence_state()**

Limpia completamente el estado del detector (limpia historial, resetea banderas), útil para reinicio del sistema sin reiniciar el proceso completo

**_get_time_occupied()**

Calcula el tiempo transcurrido desde que se detectó entrada a la cama, convertido a minutos para facilitar interpretación

## CONSIDERACIONES DE DISEÑO

**Fusión de Sensores**

El sistema implementa fusión de sensores heterogéneos (térmico, inercial, óptico) mediante suma ponderada de indicadores, cada sensor tiene un peso máximo diferente basado en su confiabilidad empírica

**Tolerancia a Fallos**

Si un sensor falla o proporciona datos inválidos, el sistema continúa operando con los sensores restantes, la confianza se ajusta automáticamente en ausencia de ciertos indicadores

**Adaptabilidad Temporal**

El baseline térmico se adapta automáticamente a cambios de temperatura ambiente durante períodos de ausencia, evitando falsas detecciones por cambios diurnos o estacionales

**Escalabilidad de Parámetros**

Todos los umbrales son configurables externamente mediante `bed_config`, permitiendo ajuste fino sin modificar código, facilitando optimización para diferentes entornos y usuarios

## RETORNO DEL MÉTODO PRINCIPAL

El método `detect_presence()` retorna un diccionario completo con:
- `occupied`: estado binario actual
- `confidence`: nivel de confianza porcentual
- `indicators`: diccionario con estado de cada indicador individual
- `time_occupied`: minutos transcurridos desde entrada
- `temp_elevation`: incremento térmico sobre baseline
- `presence_changed`: bandera indicando si hubo transición de estado en esta iteración

Este formato estructurado facilita la integración con módulos superiores del sistema de cama inteligente

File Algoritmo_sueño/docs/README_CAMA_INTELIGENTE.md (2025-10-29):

# 🛏️ Sistema de Cama Ortopédica Inteligente

Control automático de temperatura basado en estado de sueño, temperatura ambiente y **temperatura corporal**.

## 🎯 Funcionalidades

- **Detección de Estado de Sueño**: Combina acelerómetro + frecuencia cardíaca
- **Control de Temperatura Inteligente**: Ajusta automáticamente según el sueño y temperatura corporal
- **Monitoreo en Tiempo Real**: Seguimiento continuo de HR, SpO2 y temperatura
- **Seguridad**: Límites de temperatura y alertas de frecuencia cardíaca + fiebre

## 📊 Estados de Sueño y Temperatura (4 Estados)

| Estado | Descripción | Rango Temperatura | HR Típica | Actividad |
|---|---|---|---|---|
| 🌅 **DESPIERTO** | Actividad normal | 20-24°C | >75 BPM | >0.7 |
| 😴 **SUEÑO LIGERO** | Poco movimiento | 18-22°C | 55-75 BPM | 0.01-0.7 |
| 🌙 **SUEÑO REM** | HR alta + micro-mov | 19-23°C | ≥70 BPM | <0.008 |
| 🌌 **SUEÑO PROFUNDO** | Sin movimiento | 16-20°C | <55 BPM | <0.01 |

## 🎯 **Arquitectura de Sensores**

### **1. MAX30102 (I2C: 0x57)**
- **Función**: Oximetría (SpO2) + Frecuencia cardíaca + Temperatura ambiente
- **Ubicación**: Dedo (sensor principal)
- **Datos**: HR, SpO2, Temperatura ambiente del entorno
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

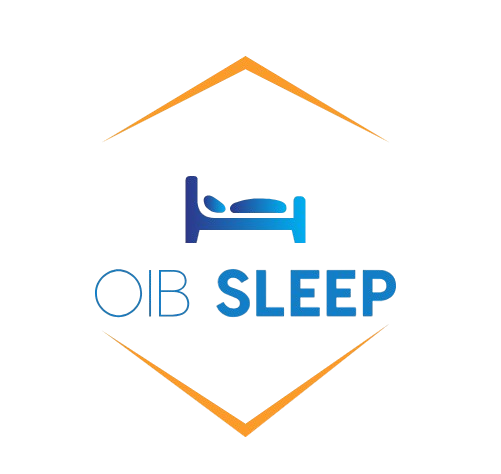
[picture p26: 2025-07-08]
pagina web/Img/Screenshot_2025-03-26_081756-removebg-preview.png

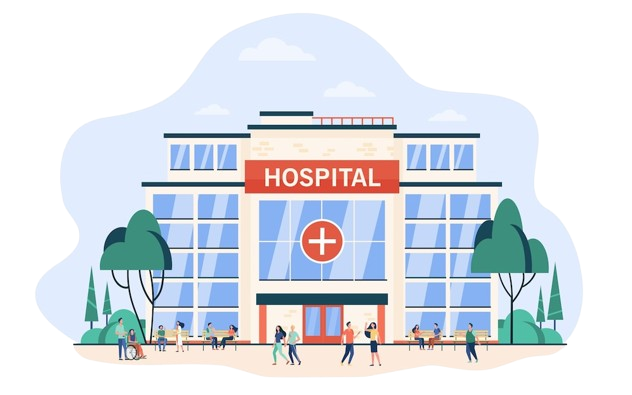
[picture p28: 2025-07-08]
pagina web/Img/Hospital.png

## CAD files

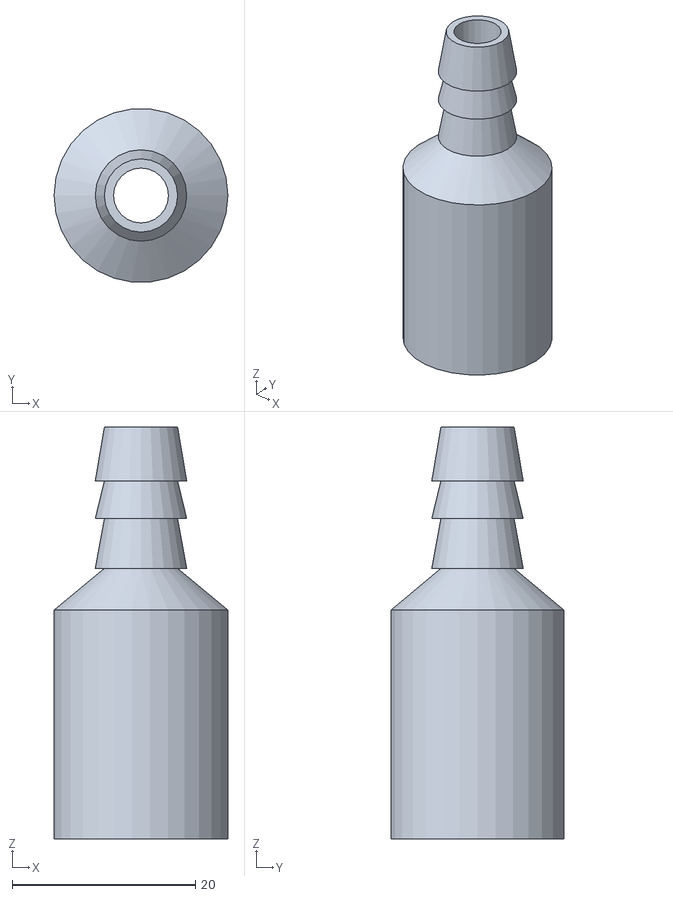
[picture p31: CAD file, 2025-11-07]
Modelo 3D/Acople/acople 2 .stl
19.0 x 18.9 x 45.0

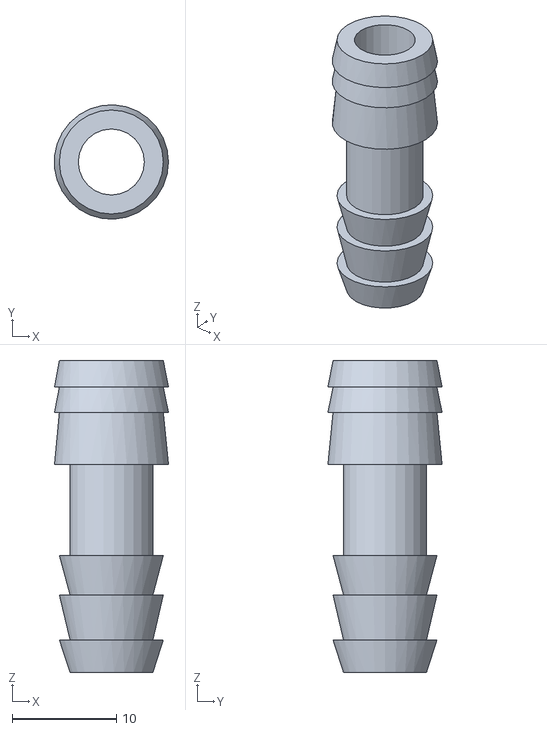
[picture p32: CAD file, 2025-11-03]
Modelo 3D/Acople/acople.stl
11.0 x 11.0 x 30.0

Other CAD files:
Modelo 3D/Soportes de circuitos/soportes.dwg

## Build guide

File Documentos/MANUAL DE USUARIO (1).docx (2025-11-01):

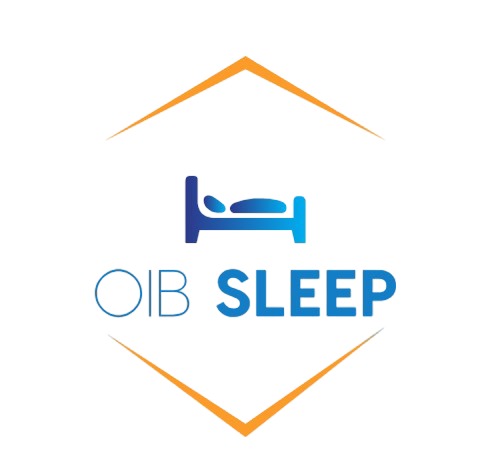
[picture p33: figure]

MANUAL DE USUARIO

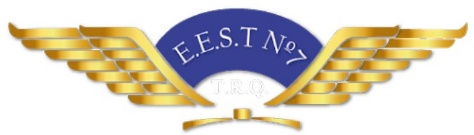
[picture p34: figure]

Dirección: Av. Otamendi, B1878 Quilmes, Provincia de Buenos Aires

1. INTRODUCCION
  1.1. Objetivo………………………………………………………….
  1.2. Requerimientos……………………………………………….
2. GUIA DE USO
  2.1. Encendido……………………………………………………….
  2.2. Mantenimiento………………………………………………..
  2.3. Brazalete…………………………………………………………
  2.4. Recomendaciones……………………………………………
  2.5. Uso del colchón……………………………………………….
  2.6. Precauciones…………………………………………………...
  2.7. Limitaciones……………………………………………………
3. CONTACTOS

INTRODUCCION

OBJETIVO

OIB Sleep es un colchón inteligente que se encarga de regular la temperatura de este dependiendo del estado de sueño de la persona durmiendo en él, todo esto con el fin de prolongar el estado del sueño REM.

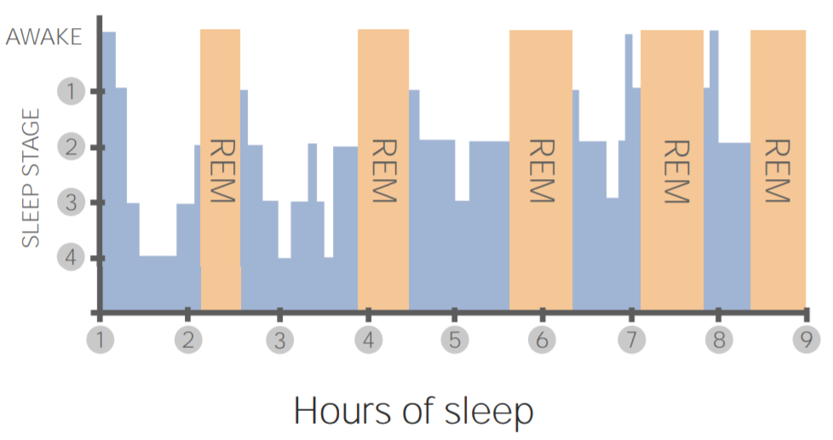
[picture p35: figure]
Fisiología del Sueño | Concise Medical Knowledge

REQUERIMIENTOS

- El brazalete necesitara wifi
- Conexión a tomacorrientes
- Agua para los tanques
- Batería con carga

GUIA DE USO

ENCENDIDO

Se debe conectar la alimentación del sistema para el funcionamiento de las bombas, cargar la batería del brazalete y tener los tanques con agua. También debe haber conexión wifi estable, si en algún momento se corta la conexión y deja de funcionar simplemente reconectar la pulsera y el control de las bombas a la red.

MANTENIMIENTO

Los tanques deberán ser llenados de agua por el mismo usuario y este deberá cambiar la misma cada cierto tiempo. En lo recomendable, en un plazo aproximado de 2 meses como máximo. La batería del brazalete debe ser cargada después de cada noche para asegurar que no se apague durante el sueño. En caso de falla el modelo de la batería es MH39766.

BRAZALETE

El brazalete contara con distintas medidas dependiendo a cuál le resulte más cómodo al usuario, tiene un sensor de temperatura corporal, uno de ritmo cardiaco y un acelerómetro. El diseño del brazalete permite movimiento en la cama, pero evitar que se caiga la caja para no dañar el circuito interno. La batería del brazalete debe estar cargada. Cuenta con variedad de tamaño y de mano a usar.

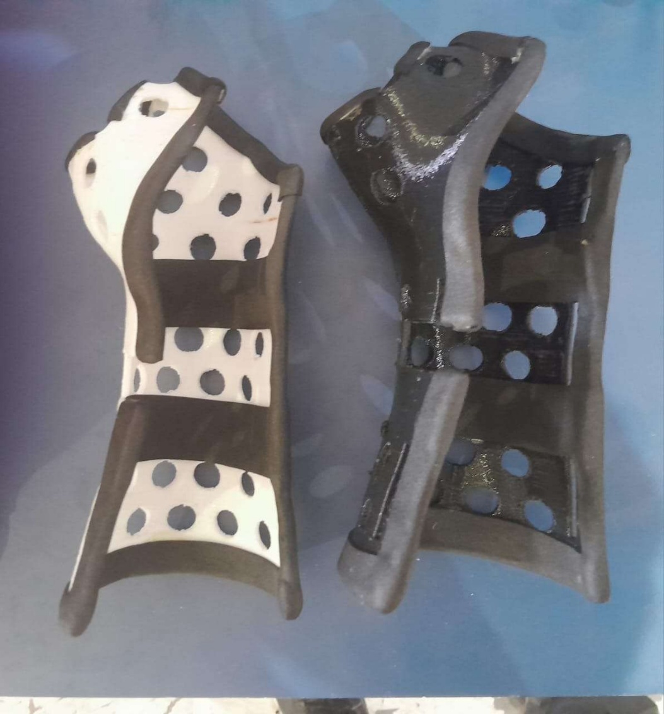
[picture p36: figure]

RECOMENDACIONES

Para mantener el agua limpia dentro de los tanques de agua, es recomendable utilizar pastillas de cloro para mantener la calidad del agua y así prolongar su cambio necesario.

USO DE COLCHON

El funcionamiento del colchón es automático y regulara la temperatura de si mismo. Para que comience debe estar alimentado el sistema, con conexión a wifi y el usuario en la cama con el brazalete. Con la información del brazalete del estado del usuario se empezará a regular la temperatura de la cama con las bombas. Las bombas solo se encienden mientras haya una diferencia con la temperatura deseada y cuando se alcance el rango de esta temperatura se apagarán hasta ser necesitadas devuelta. Se puede regular la temperatura deseada manualmente si se quiere. Mientras esta funcionando el colchón fluirá agua fría o caliente por los caños de cobre internos que no afectaran la comodidad del colchón.

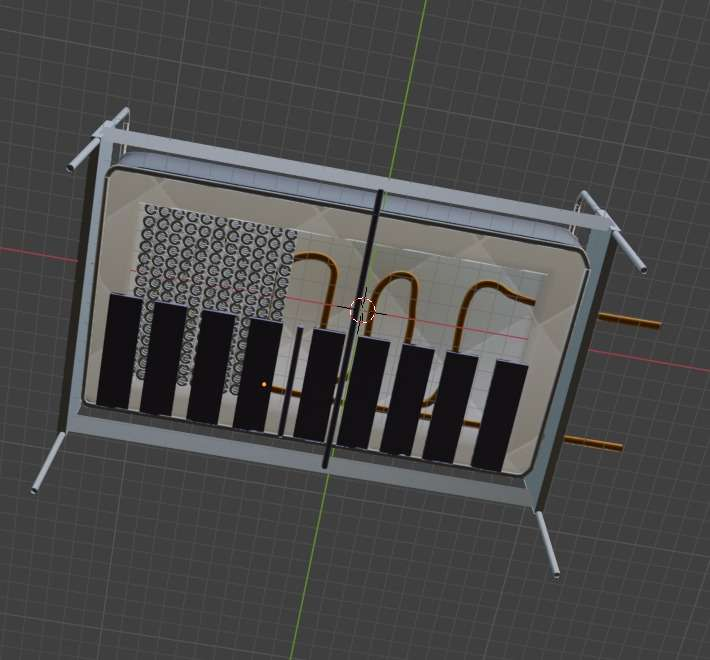
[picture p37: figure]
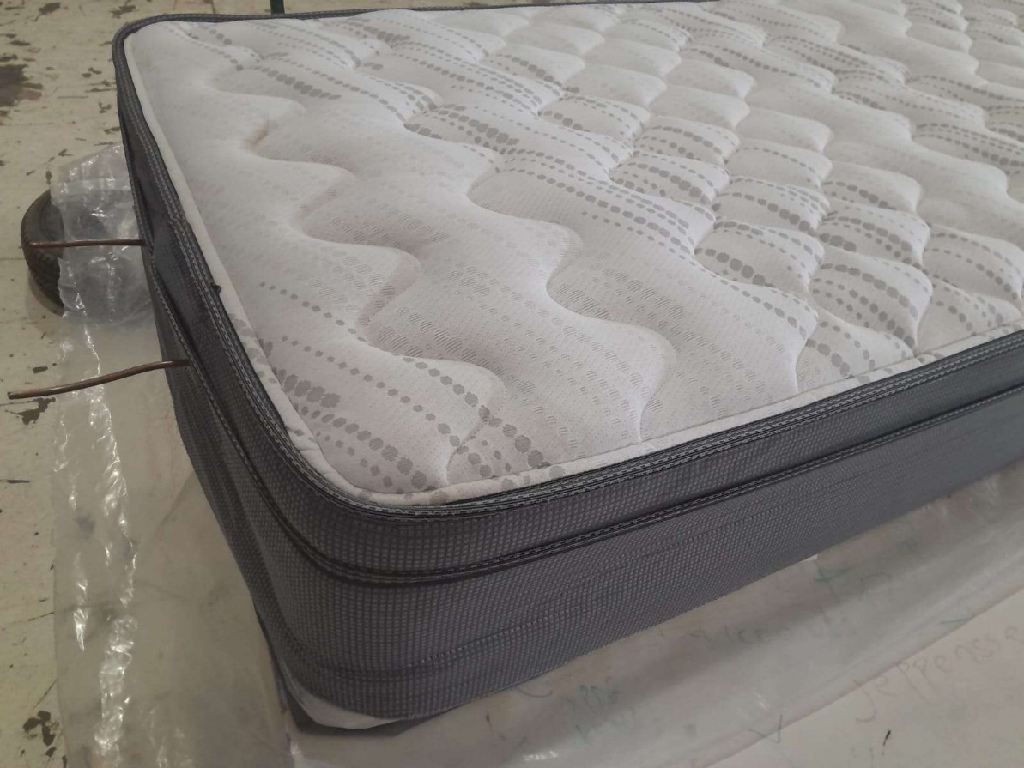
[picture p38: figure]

PRECAUCIONES

NO encender las bombas sin suficiente agua en los tanques ya que puede causar que se rompen y que necesiten cambio, siempre tener agua cuando se vaya a usar y si no mantener apagado todo.
NO entrar en contacto con el agua mientras estén encendidos los sistemas de refrigeración y calefacción.
Solo usar agua con una temperatura ambiente o levemente fría, los tanques se encargaran de regular su temperatura automáticamente.

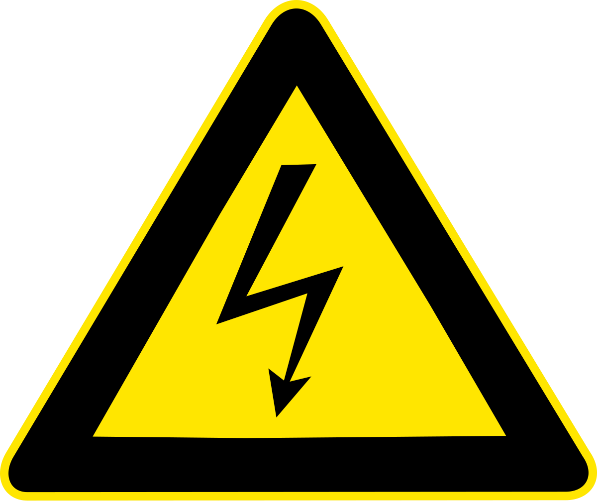
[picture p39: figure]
Choque eléctrico - Wikipedia, la enciclopedia libre

LIMITACIONES
Evitar excederse de 150 kilos en la cama para evitar daño a los caños de cobres internos.
Sin wifi no funcionara el sistema de regulación automática durante la noche.
La batería del brazalete durara aproximadamente 8-10 horas en carga máxima, si se desea usar mayor tiempo se deberá cambiar la batería. Sin el brazalete aun se puede regular manualmente mientras no se esta durmiendo.

CONTACTOS

- Link a la web.

https://oib-sleep.vercel.app/

- Link a trello.

https://trello.com/b/l2F858gx/kanban

- Link a github.

https://github.com/impatrq/OIB_Sleep

- Link redes sociales.

https://www.instagram.com/oibsleep?igsh=cHZ5NTRwdWFwMXAz

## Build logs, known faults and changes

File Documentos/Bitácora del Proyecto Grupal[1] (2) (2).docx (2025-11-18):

Bitácora del Proyecto: Oib Sleep

• Nombre del proyecto: Oib Sleep

• Responsables: Lorenzo Maximo Fernandez color naranja, Ezequiel Bourlot color azul, Vignetta Joaquin violeta, Federico Rodriguez Domoñi verde.

• Objetivo general: Lograr concretar el proyecto de una manera eficiente con una distribución de tareas equitativa

Integrante: Ezequiel Bourlot

📍 Entrada 1

• Fecha: [15 de marzo]

• Hora de inicio – fin: [12:00pm 5:00pm]

• 🔧 Actividades realizadas:

Comienzo del ante proyecto, investigación de como se podría hacer análisis de costos y armado de la lista de materiales.

Investigación de a que grupos podríamos ayudar.

📍 Entrada 2

• Fecha: [16 de marzo]

• Hora de inicio – fin: [1:00pm 4:30pm]

• 🔧 Actividades realizadas:

Armado del análisis de factibilidad y el diagrama de bloques.

📍 Entrada 3

• Fecha: [17 de marzo]

• Hora de inicio – fin: [8:30am 11:30am]

• 🔧 Actividades realizadas:

Armado del diagrama de tiempo de desarrollo.

Charla con los profesores sobre el proyecto y que deberíamos cambiar.

📍 Entrada 4

• Fecha: [21 de marzo]

• Hora de inicio – fin: [8:30am 11:30am]

🔧 Actividades realizadas:

Investigación sobre cuanto afecta la temperatura a la hora de modificar el sueño, como alargar el sueño REM con esta, investigación concluyente de la Tohoku Fukushi University.

📍 Entrada 5

• Fecha: [11 de abril]

• Hora de inicio – fin: [1:30pm-3:30pm]

• 🔧 Actividades realizadas:

Realize la presentación de Instagram utilizando prezi con lo que logre que al buscar Oib sleep en Google la ia de Google te tire la información del proyecto.

La presentación la había creado estilo power point pero la tuve que modificar para mejor visibilidad en celulares.

📍 Entrada 6

• Fecha: [18 de abril]

• Hora de inicio – fin: [1pm-7pm]

• 🔧 Actividades realizadas:

Comienzo de la página web, estructura inicial del index y su estilo. (el estilo inicial iba a ser con colores marrones)

Aprendizaje de la función model viewer para agregar un modelo de la cama a la página web

📍 Entrada 7

• Fecha: [19 de abril]

• Hora de inicio – fin: [3pm-9pm]

• 🔧 Actividades realizadas:

Comienzo de la pestaña sobre nosotros, búsqueda de fotos para los diferentes párrafos, cambio de paleta de colores de la pagina para ir de la mano con el logotipo de Oib Sleep.

Se empieza a hacer @media para hacer la pagina web responsive

📍 Entrada 8

• Fecha: [20 de abril]

• Hora de inicio – fin: [1pm-4am]

• 🔧 Actividades realizadas:

Armado de las ultimas 2 pestañas se la pagina web (contáctanos y galería) diseño del forms y de la estructura de la pestaña en donde van a ir las fotos y un cobertor hasta que subamos fotos.

Cambio de fondo por uno de un hospital con una gama de colores azules, se le agrega transiciones de aparición al texto y fotos del sitio para dar un scroll más suave.

Agregado de código java script para hacer una flecha para volver arriba de toda la página, animaciones a algunas imágenes al pasar el mouse por arriba y Efecto al mover el mouse.

📍 Entrada 9

• Fecha: [22 de abril]

• Hora de inicio – fin: [8:30-11:30am]

• 🔧 Actividades realizadas:

Optimización del modelo 3D de la cama para correr mejor en celulares.

El problema era que en computadoras iba fluido, pero en celulares a la hora de mover el modelo se trababa mucho. Investigue las propiedades del model viewer y diferentes formas de optimización. Sigue sin tener el mayor rendimiento posible, pero es debido a que el modelo provisorio cuenta con demasiados polígonos.

📍 Entrada 10

• Fecha: [25 de abril]

• Hora de inicio – fin: [8:30-11:30am]

• 🔧 Actividades realizadas:

Hosteo de la página web, modificación de todas las fotos para estar en la nube y poder usarlas desde la página web ya subida.

Agregado de detalles como un apartado con la dirección maps del IMPA

Habilitación del forms para el dominio nuevo ya que este funciona por dominio y lo había que actualizar.

📍 Entrada 11

• Fecha: [26 de abril]

• Hora de inicio – fin: [2:00pm a 7:00pm]

• 🔧 Actividades realizadas:

Agregué transiciones al moverse entre las diferentes pestañas de la página web

Agregue un botón para poder ver las medidas del modelo 3D al verlas el modelo no se puede mover para mayor rendimiento también agregue uno para poder cambiar entre cm y inches.

📍 Entrada 12

• Fecha: [28 de abril]

• Hora de inicio – fin: [9:00am a 10:00am]

• 🔧 Actividades realizadas:

Contacté con sponsors como Xiaomi, cannon, ElectroComponentes, TodoMicro, etc

📍 Entrada 13

• Fecha: [29 de abril]

• Hora de inicio – fin: [9:00am a 11:00am]

• 🔧 Actividades realizadas:

Comienzo curso de python para programar la raspberry pi zero w.

📍 Entrada 14

• Fecha: [5 de mayo]

• Hora de inicio – fin: [1:00pm a 3:00pm]

• 🔧 Actividades realizadas:

Seguí con el curso de Python hasta la hora 2:15 de video

📍 Entrada 15

• Fecha: [ 6 de mayo]

• Hora de inicio – fin: [9:00am a 12:00am]

• 🔧 Actividades realizadas:

Curso de python hasta la hora 4:10

📍 Entrada 16

• Fecha: [7 de mayo]

• Hora de inicio – fin: [8:30am a 11:40am]

• 🔧 Actividades realizadas:

Seguí con el curso de Python hasta la hora 5 e investigué que tipo de colchón necesitamos junto con lorenzo, para pedir a Simmons con los cuales tendremos un encuentro presencial el viernes 9/5

📍 Entrada 17

• Fecha: [8 de mayo]

• Hora de inicio – fin: [8:00am a 2:30am]

• 🔧 Actividades realizadas:

Seguí con el curso de Python hasta la hora 6 y terminé de poner los datos en la pagina web para tener algo que mostrar en el encuentro con Simmons. Cambie el place holder del modelo al modelo terminado hecho por lorenzo.

Prepare lo que vamos a decir en la presentación.

📍 Entrada 18

• Fecha: [8 de mayo]

• Hora de inicio – fin: [5:00pm a 9:00pm]

• 🔧 Actividades realizadas:

Investigue como poner el modelo de auto cad en la pagina web usando model viewer para eso lo tuve que pasar a glb pero hubo complicaciones con el escalado que estuve tratando de resolver unas dos horas y no lo logre. Terminé la página web agregándole imágenes a los participantes y sus roles con descripción además agregué el contacto de todos a losbotones de la tarjeta. Por último, modifique el index para que el parámetro para cambiar la medida que te muestra la cama entre centímetros y inches se muestre solo si clickeas la regla.

📍 Entrada 19

• Fecha: [9 de mayo]

• Hora de inicio – fin: [8:00am a 11:30am]

• 🔧 Actividades realizadas:

Nos encontramos con la gerente de marketing de Simmons argentina y con el gerente de la sucursal de argentina. Hicimos un recorrido por las instalaciones y aprendimos sobre los diferentes tipos de colchones y su fabricación, conseguimos que nos patrocinaron con un colchón de resortes de una plaza.

📍 Entrada 20

• Fecha: [13 de mayo]

• Hora de inicio – fin: [8:30am a 11:30am]

• 🔧 Actividades realizadas:

Seguí con el curso de Python hasta la hora 7 y estudié sobre cómo hacer el código para la regulación de temperatura

📍 Entrada 21

• Fecha: [15 de mayo]

• Hora de inicio – fin: [8:30am a 11:30am]

• 🔧 Actividades realizadas:

Termine el curso de Python 8:10hs e instale Python en la raspberry pi zero w

📍 Entrada 22

• Fecha: [20 de mayo]

• Hora de inicio – fin: [8:30am a 11:30am]

• 🔧 Actividades realizadas:

Hice la lista de compras para el proyecto con todo lo necesario y la subí al Excel del drive

📍 Entrada 23

• Fecha: [20 de mayo]

• Hora de inicio – fin: [8:00am a 11:00am]

• 🔧 Actividades realizadas:

Modifiqué el fav-icon de la página web para mayor legibilidad además mejor la redacción para el motor de búsqueda de Google, ahora la pagina aparece primero y la ia de Google responde diferentes consultas sobre nuestro proyecto

📍 Entrada 24

• Fecha: [13 de abril]

• Hora de inicio – fin: [9:00am a 11:00am]

• 🔧 Actividades realizadas:

Investigue sobre formas de conectar una Xiaomi band a una raspberry pi pico, por lo que se tomó la decisión de una Xiaomi band 3 por que se encontró repositorios de conexión directa entre estos dos elementos vía bluetooth

📍 Entrada 25

• Fecha: [20 de abril]

• Hora de inicio – fin: [2:30pm a 5:00pm]

Modificamos la lista de materiales junto a Vignetta ya que tenemos materiales como bomas eléctricas que nos dio el jefe de área además de sacar disipadores y collers de la lista ya que Carlassara nos dio 4 de las 6 necesarias.

📍 Entrada 26

• Fecha: [5 de junio]

• Hora de inicio – fin: [3:30pm a 5:00pm]

Estuve buscando algoritmos de sueño en GitHub para calcular el estado de sueño en el que se encuentra la persona basada en el ritmo cardiaco y un acelerómetro.

📍 Entrada 27

• Fecha: [14 de junio]

• Hora de inicio – fin: [8:30am a 11:30am]

Charlamos con Carlassara el tema de la lista de compras y nos dio el okay después de todo menos de la Xiaomi band.

📍 Entrada 28

• Fecha: [19 de junio]

• Hora de inicio – fin: [2:30pm a 5:30pm]

Fuimos con Vignetta y el jefe de área a pedir los materiales a coperadora después de agregar precio de envío que no habíamos tenido en cuenta y dio un sobrante de 80k redondead. Los caños de cobre no llegaban a la escuela por lo cual lleve a federico y a lorenzo a Quilmes centro a comprarlos lo demás fue todo aceptado y comprado por mercado libre.

📍 Entrada 29

• Fecha: [24 de junio]

• Hora de inicio – fin: [2:30pm a 3:30pm]

Los primeros componentes llegaron por lo cual los fuimos a buscar y verificamos el estado de todos los componentes, además de verificar que no falte ninguno, faltaban la espuma de poliuretano y los coolers pero nos dijieron que llegarían en los próximos días.

📍 Entrada 30

• Fecha: [3 de julio]

• Hora de inicio – fin: [2:30pm a 5:30pm]

Fui a buscar los últimos componentes y planeamos con Vignetta el armado de una banda con los sensores de temperatura, ritmo cardiaco y un acelerómetro debido a la recomendación que nos dio carlassara sobre que hacer esto tenía mas valor en el proyecto y no era tan complejo.

📍 Entrada 31

• Fecha: [7 de julio]

• Hora de inicio – fin: [1:30pm a 5:00pm]

Subí el modelo 3d y la página web al repositorio clonado y lo pushee al origen además de cambiar el host de la página web a vercel ya que dieron de baja el host en glitch debido al tiempo que llevaba subida la página.

📍 Entrada 32

• Fecha: [14 de julio]

• Hora de inicio – fin: [8:30am a 10:00am]

Fui a comprar los materiales para la Smart band a electrónica 80 pero ellos no contaban con estos.

📍 Entrada 33

• Fecha: [28 de julio]

• Hora de inicio – fin: [1:30am a 6:30am]

Trabaje en el código del proyecto empezando por el ritmo cardiaco y haciendo modificaciones en el código ya conseguido para agregarle las funciones de acelerómetro para así poder calcular la etapa de sueño.

📍 Entrada 34

• Fecha: [29 de julio]

• Hora de inicio – fin: [1:30am a 3:30am]

Seguí trabajando en conseguir que el código determine el estado del sueño también cambie el acelerómetro pedido en la lista de compras

📍 Entrada 35

• Fecha: [6 de agosto]

• Hora de inicio – fin: [8:30am a 11:30am]

Trabaje en el código que controla la cama dependiendo del estado de sueño puliendo la detección del estado de sueño.

Características Implementadas:

Análisis Avanzado de Sueño:

- Calidad de sueño
- Análisis de fragmentación
- Detección de inicio de sueño
- Registro de despertares

📍 Entrada 36

• Fecha: [7 de agosto]

• Hora de inicio – fin: [8:30am a 11:30am]

Seguí trabajando en el código que controla la cama dependiendo del estado de sueño puliendo la detección del estado de sueño.

Características Implementadas:

Análisis de Variabilidad Cardíaca (HRV):

- RMSSD (Raíz Cuadrada de la Media de las Diferencias Sucesivas al Cuadrado)
- SDNN (Desviación Estándar de los Intervalos Normales)
- Puntuación de estrés
- Distribución Detallada de Estados:
- Seguimiento porcentual de cada fase de sueño
- Comparación con valores ideales
- Recomendaciones automáticas
- Sensores Integrados:
- MAX30102: Ritmo cardíaco, SpO2, temperatura ambiente
- MMA8452Q: Detección de movimiento
- AHT10: Temperatura corporal via weara
- Htu21d: Temperatura ambiente

📍 Entrada 37

• Fecha: [8 de agosto]

• Hora de inicio – fin: [8:00am a 11:40am]

Trabaje en el código para la detección del estado del sueño

Características Implementadas:

Distribución Detallada de Estados:

- Seguimiento porcentual de cada fase de sueño
- Comparación con valores ideales
- Recomendaciones automáticas

Sensores Integrados:

- MAX30102: Ritmo cardíaco, SpO2, temperatura ambiente
- MMA8452Q: Detección de movimiento
- AHT10: Temperatura corporal via weara
- Htu21d: Temperatura ambiente

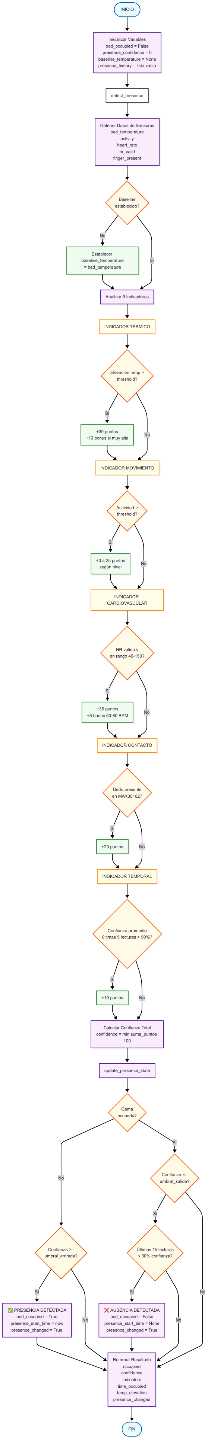
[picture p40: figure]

📍 Entrada 38

• Fecha: [11 de agosto]

• Hora de inicio – fin: [1:20pm a 2:30pm]

Trabaje en un sistema para detectar la presencia sobre la cama para que se apague cuando no hay nadie encima para esto use los diferentes sensores con las que ya contábamos, para no agregar costos innecesarios.

- Analize requisitos del sistema de detección de presencia
- Diseñe arquitectura multi-sensor
- Definí sensores necesarios y sus funciones

📍 Entrada 39

• Fecha: [12 de agosto]

• Hora de inicio – fin: [1:30pm a 5:00pm]

Seguí trabajando en el sistema de detección de presencia:

- Implemente sistema de histéresis para evitar falsas alarmas
- Desarrolle baseline térmico adaptativo
- Cree filtros temporales para estabilidad

📍 Entrada 40

• Fecha: [13 de agosto]

• Hora de inicio – fin: [8:30am a 12:00pm]

Trabaje en la parte para conectar todos los sensores y el acelerómetro con control de errores para que salte si hay alguno que el sistema no este registrando o que este mandando datos incorrectos.

implemente un sistema de análisis predictivo y monitoreo térmico avanzado basado en los estudios científicos de la imagen del ante proyecto

📍 Entrada 41

• Fecha: [28 de agosto]

• Hora de inicio – fin: [8:30pm a 12:00pm]

Trabaje en leer los sensores mediante la esp32 C3.

📍 Entrada 42

• Fecha: [1 de septiembre]

• Hora de inicio – fin: [1:20pm a 5:20pm]

Hice el código para probar los sensores instalando sus librerías correspondientes e instalando plataformIO para crear el espacio de prueba. Además, ayude a Vignetta a hacer el circuito para la pulsera.

📍 Entrada 43

• Fecha: [2 de septiembre]

• Hora de inicio – fin: [7:40am a 11:40am]

Estuve tratando de hacer que funcioné de diferentes formas, comprobé que el esp32 recibía código, pero no devolvía. Después de probar mucho concluí que era tema de un componente que faltaba en la ESP32 c3(se rompió).

📍 Entrada 44

• Fecha: [4 de septiembre]

• Hora de inicio – fin: [8:00am a 11:40am]

Instale la sd a la raspberry, después de instalar el sistema operativo e intentar varias formas que ya habían quedado obsoletas para conectarla a wifi logre conectarla al reinstalar pioslite con piImager ya configurando el wifi desde este instalador. Después de lograr conectar la raspberry estuve tratando de transmitir datos simulados de la esp 32 sin resultado.

📍 Entrada 45

• Fecha: [5 de septiembre]

• Hora de inicio – fin: [7:40am a 11:40am]

Trate difentes formas y cambie el código varias veces hasta que en un momento funcionó. También tuve problemas para conectar todo a wifi debido a que las redes estaban colapsadas estuve 2 horas tratando con ese wifi hasta que decisidi usar hotspot del celular

📍 Entrada 46

• Fecha: [10 de septiembre]

• Hora de inicio – fin: [10:00am a 12:00am]

Estuve trabajando con la esp 32 ahora para probar los componentes, pero la esp 32 no se está conectando a wifi a diferencia de antes tras estar viendo de todo no encontré solución. Concluí que lo tengo que hablar con algún profesor porque no encuentro cual es el problema. Lo único que encontré que podría ser una solución es alimentar la eso32 de otra manera ya que usuarios tuvieron problemas con que andaba pero no se conectaba a wifi debido a la alimentación via usb

📍 Entrada 47

• Fecha: [12 de septiembre]

• Hora de inicio – fin: [1:10pm a 5:00pm]

Estuve trabajando en el código para la pulsera, Fabri me presto su esp 32 y con esta el código si funciona ya que se conecta a internet, tras hacer el código este dio que los sensores no estaban bien conectados o había un error en el código por el cual no se mandaban las mediciones correspondientes

Bitácora del Proyecto: Oib Sleep

• Nombre del proyecto: Oib Sleep

• Responsable: Lorenzo Maximo Fernandez

• Objetivo general: Realizar un modelo 3D para poder llegar de manera mas sencilla a la gente, encargado de la estructura del colchón y realizar investigaciones de problemas que surjan.

📆 Entradas de desarrollo

📍 Entrada 1

• Fecha: [15 de marzo]

• Hora de inicio – fin: [12:00pm 5:00pm]

• 🔧 Actividades realizadas:

Comienzo del ante proyecto, investigación de cómo se podría hacer análisis de costos y armado de la lista de materiales.

Investigación de a que grupos podríamos ayudar.

📍 Entrada 2

- Fecha [18 de marzo]
- Hora de inicio – fin: [08:00am 11:30am]
- 🔧 Actividades realizadas:

Comienzo del planificado del armado del proyecto y búsqueda de posibles materiales.

📍 Entrada 3

- Fecha [20 de marzo]
- Hora de inicio – fin: [08:00am 10:00am]
- 🔧 Actividades realizadas:

Comienzo de bocetos en hoja de posibles maneras de el armado de colchón.

📍 Entrada 4

- Fecha [25 de marzo]
- Hora de inicio – fin: [08:00am 11:30am]
- 🔧 Actividades realizadas:

Comienzo del planificado del armado del proyecto y búsqueda de posibles materiales de los tubos que pasan por el colchón.

📍 Entrada 5

- Fecha [27 de marzo]
- Hora de inicio – fin: [08:00am 10:30am]
- 🔧 Actividades realizadas:

Se vio distintas maneras de distribución de los caños y se siguió investigando cual era el material más factible para usar.

📍 Entrada 6

- Fecha [7 de abril]
- Hora de inicio – fin: [08:00am 10:40am]
- 🔧 Actividades realizadas:

Comienzo con el curso de AutoCAD. Se aprendieron las herramientas básicas.

📍 Entrada 7

- Fecha [14 de abril]
- Hora de inicio – fin: [08:00am 10:40am]
- 🔧 Actividades realizadas:

Se siguió con el curso de AutoCAD y se comenzó a planificar el modelo 3D.

📍 Entrada 7

- Fecha [16 de abril]
- Hora de inicio – fin: [13:20pm 15:00]
- 🔧 Actividades realizadas:

Se comenzó con el modelo 3D

📍 Entrada 8

- Fecha [21 de abril]
- Hora de inicio – fin: [08:00am 10:40am]
- 🔧 Actividades realizadas:

Se comenzó con la distribución y definición de detalles del modelo 3D.

📍 Entrada 9

- Fecha [23 de abril]
- Hora de inicio – fin: [08:00am 11:40am]
- 🔧 Actividades realizadas:

Se comenzó con el realizado del renderizado y se empezó a imprimir en 3D

📍 Entrada 10

- Fecha [14 de abril]
- Hora de inicio – fin: [08:00am 10:40am]
- 🔧 Actividades realizadas:

Se siguió con el curso de AutoCAD y se comenzó a planificar el modelo 3D.

https://drive.google.com/file/d/14pkr3VzxZoFKF6RDCOGXCe6tkGAMV2Io/view?usp=sharing

📍 Entrada 11

- Fecha [29 de abril]
- Hora de inicio – fin: [08:00am 10:40am]
- 🔧 Actividades realizadas:

Se hablo con picca hogar y se hablo con German picca

📍 Entrada 12

• Fecha: [7 de mayo]

• Hora de inicio – fin: [8:30am a 11:40am]

• 🔧 Actividades realizadas:

nvestigué que tipo de colchón necesitamos junto con Ezequiel, para pedir a Simmons con los cuales tendremos un encuentro presencial el viernes 9/5

📍 Entrada 13

• Fecha: [9 de mayo]

• Hora de inicio – fin: [8:30am a 11:40am]

• 🔧 Actividades realizadas:

Nos encontramos con la gerente de marketing de Simmons argentina y con el gerente de la sucursal de argentina. Hicimos un recorrido por las instalaciones y aprendimos sobre los diferentes tipos de colchones y su fabricación, conseguimos que nos patrocinaron con un colchón de resortes de una plaza.

📍 Entrada 14

• Fecha: [21 de mayo]

• Hora de inicio – fin: [14:20pm 15:00pm]

• 🔧 Actividades realizadas:

Se recibió el colchón

📍 Entrada 15

• Fecha: [24 de mayo]

• Hora de inicio – fin: [19:00pm 21:00pm]

• 🔧 Actividades realizadas:

Se empezó con el curso de blender

📍 Entrada 16

• Fecha: [12 de junio]

• Hora de inicio – fin: [8:00am 12:00pm]

• 🔧 Actividades realizadas: Se empezó el modelo 3D final para la pagina

Se empezó a realizar el modelo que va a estar en la pagina.

📍 Entrada 17

• Fecha: [16 de junio]

• Hora de inicio – fin: [8:00am 12:00pm]

• 🔧 Actividades realizadas: Se continuo con el modelo 3D final para la pagina

Se continuo con el renderizado de el modelo 3D.

📍 Entrada 18

• Fecha: [ 26 de junio]

• Hora de inicio – fin: [8:00am 12:00pm]

• 🔧 Actividades realizadas: Se termino modelo 3D final para la pagina

Se termino el modelo 3D final para la pagina poniéndole texturas y renderizados metálicos.

📍 Entrada 19

• Fecha: [1 de julio]

• Hora de inicio – fin: [8:00am 10:00am]

• 🔧 Actividades realizadas: Se diseño un acople para las bombas de agua.

Se realizo un acople para conectas las bombas de agua con los caños de cobre.

📍 Entrada 20

• Fecha: [1 de julio]

• Hora de inicio – fin: [11:00am]

• 🔧 Actividades realizadas: Se termino el diseño del acople para las bombas de agua

Se termino el diseño del acople de las bombas de agua ahora se lo busca imprimir.

📍 Entrada 21

• Fecha: [2 de julio]

• Hora de inicio – fin: [9:15am 12:00pm]

• 🔧 Actividades realizadas: diseñado de soportes de circuitos

Se empezó a crear un modelo 3D para el soporte de los circuitos.

📍 Entrada 22

• Fecha: [2 de julio]

• Hora de inicio – fin: [13:00pm 13:30pm]

• 🔧 Actividades realizadas: diseñado de soportes de circuitos

Se termino el diseñado de soportes de circuitos

📍 Entrada 23

• Fecha: [4 de julio]

• Hora de inicio – fin: [13:30pm 16:00pm]

• 🔧 Actividades realizadas: Impresión de acoples

Se imprimieron los acoples de las bombas ahora se buscan imprimir 2 mas en abs

📍 Entrada 24

• Fecha: [11 de julio]

• Hora de inicio – fin: [8:00am 12:00pm]

• 🔧 Actividades realizadas: creado de soportes

Se empezó a realizar los soportes de los circuitos

📍 Entrada 25

• Fecha: [13 de julio]

• Hora de inicio – fin: [19:00m 22:00pm]

• 🔧 Actividades realizadas: creado de presentación

Se empezó con la primera presentación del proyecto.

📍 Entrada 26

• Fecha: [14 de julio]

• Hora de inicio – fin: [13:30 pm 14:00pm]

• 🔧 Actividades realizadas: creado de presentación

Se termino la primera presentación del proyecto.

📍 Entrada 27

• Fecha: [14 de julio]

• Hora de inicio – fin: [14:00pm 17:00pm]

• 🔧 Actividades realizadas: primeras pruebas de apertura de colchón

Se empezó con la primera prueba de la apertura de colchón

📍 Entrada 28

• Fecha: [5 de agosto]

• Hora de inicio – fin: [14:00pm 16:30 pm]

• 🔧 Actividades realizadas: primeras pruebas de temperatura de colchón

Se empezó a probar el control de temperatura del colchón

📍 Entrada 29

• Fecha: [6 de agosto]

• Hora de inicio – fin: [8:00am 12:00pm]

• 🔧 Actividades realizadas: modificación de las historias de usuario

Se modificaron historias de usuario

📍 Entrada 30

• Fecha: [13 de agosto]

• Hora de inicio – fin: [8:00am 12:00pm]

• 🔧 Actividades realizadas: adaptación de planchas de aluminio

Se Modifico los tanques de agua adaptando planchas de aluminio previamente cortadas

📍 Entrada 31

• Fecha: [26 de agosto]

• Hora de inicio – fin: [8:00am 12:00pm]

• 🔧 Actividades realizadas: adaptación de planchas de aluminio

Se terminaron de poner las planchas de aluminio y se sellaron fugas

📍 Entrada 32

• Fecha: [28 de agosto]

• Hora de inicio – fin: [8:00am 12:00pm]

• 🔧 Actividades realizadas: adaptación de planchas de aluminio

se sellaron fugas de los tanques.

📍 Entrada 32

• Fecha: [1 de septiempre]

• Hora de inicio – fin: [8:00am 12:00pm]

• 🔧 Actividades realizadas: Se realizo el primer modelo de el brazalete

Se creo y se imprimió el primer modelo de el brazalete sensor de ritmo cardiaco

📍 Entrada 33

• Fecha: [10 de septiempre]

• Hora de inicio – fin: [8:00am 12:00pm]

• 🔧 Actividades realizadas: Se Rediseño el modelo del brazalete y el sensor de ritmo cardiaco

📍 Entrada 34

• Fecha: [16 de septiempre]

• Hora de inicio – fin: [10:00am 10:30 am]

• 🔧 Actividades realizadas: Se abrió parte del colchon y se sacaron medidas

📍 Entrada 35

• Fecha: [23 de septiempre]

• Hora de inicio – fin: [10:00am 12:00 pm]

• 🔧 Actividades realizadas: Se empezó a hacer un rediseño de las placas

📍 Entrada 36

• Fecha: [26 de septiempre]

• Hora de inicio – fin: [10:00am 12:00 pm]

• 🔧 Actividades realizadas: Se Probaron las nuevas placas y se arreglaron errores

📍 Entrada 37

• Fecha: [30 de septiempre]

• Hora de inicio – fin: [10:00am 12:00 pm]

• 🔧 Actividades realizadas: Se hizo el ultimo diseño de la placa del sensor de ritmo cardiaco

📍 Entrada 38

• Fecha: [7 de octubre ]

• Hora de inicio – fin: [10:00am 12:00 pm]

• 🔧 Actividades realizadas: Se empezó con la apertura del colchón

📍 Entrada 39

• Fecha: [8 de octubre ]

• Hora de inicio – fin: [10:00am 12:00 pm]

• 🔧 Actividades realizadas: Se termino con la apertura del colchon y el pasado de los caños

📍 Entrada 40

• Fecha: [10 de octubre ]

• Hora de inicio – fin: [10:00am 12:00 pm]

• 🔧 Actividades realizadas: Se empezó con el forrado de la pulsera de ritmo cardiaco

📍 Entrada 41

• Fecha: [14 de octubre ]

• Hora de inicio – fin: [10:00am 12:00 pm]

• 🔧 Actividades realizadas: Se probaron placas y se buscaron errores

📍 Entrada 42

• Fecha: [17 de octubre ]

• Hora de inicio – fin: [10:00am 12:00 pm]

• 🔧 Actividades realizadas: Se termino con el forrado de el brazalete

📍 Entrada 43

• Fecha: [21 de octubre ]

• Hora de inicio – fin: [10:00am 12:00 pm]

• 🔧 Actividades realizadas: Se Actualizo la bitácora

📍 Entrada 44

• Fecha: [30 de octubre ]

• Hora de inicio – fin: [10:00am 12:00 pm]

• 🔧 Actividades realizadas: Se pasaron los caños de cobre en la cama

📍 Entrada 45

• Fecha: [3 de noviembre ]

• Hora de inicio – fin: [13:00pm 17:00 pm]

• 🔧 Actividades realizadas: Se cortaron y pulieron patas de la cama

📍 Entrada 46

• Fecha: [31 de noviembre ]

• Hora de inicio – fin: [13:00pm 17:00 pm]

• 🔧 Actividades realizadas: Se grabo el video de presentación del proyecto

📍 Entrada 47

• Fecha: [3 de noviembre ]

• Hora de inicio – fin: [13:00pm 17:00 pm]

• 🔧 Actividades realizadas: Se cortaron y pulieron patas de la cama

📍 Entrada 48

• Fecha: [7 de noviembre ]

• Hora de inicio – fin: [10:00 am 12:00 pm]

• 🔧 Actividades realizadas: Se instalaron sujetadores en el brazalete

Integrante: Federico Rodríguez Domoñi

📆 Entradas de desarrollo

📍 Entrada 1

• Fecha: [15 de marzo]

• Hora de inicio – fin: [12:00pm 5:00pm]

•🔧 Actividades realizadas:

Comienzo del ante proyecto, investigación de cómo se podría hacer análisis de costos y armado de la lista de materiales.

Investigación de a que grupos podríamos ayudar.

📍 Entrada 2

• Fecha: [16 de marzo]

• Hora de inicio – fin: [1:00pm 4:30pm]

•🔧 Actividades realizadas:

Armado del análisis de factibilidad y el diagrama de bloques.

📍 Entrada 3

• Fecha: [17 de marzo]

• Hora de inicio – fin: [8:30am 11:30am]

•🔧 Actividades realizadas:

Armado del diagrama de tiempo de desarrollo.

Charla con los profesores sobre el proyecto y que deberíamos cambiar.

📍 Entrada 4

- Fecha [20 de marzo]
- Hora de inicio – fin: [08:00am 10:00am]
- 🔧 Actividades realizadas:

Comienzo de bocetos en hoja de posibles maneras de el armado de colchón.

📍 Entrada 5

- Fecha [25 de marzo]
- Hora de inicio – fin: [08:00am 11:30am]
- 🔧 Actividades realizadas:

Comienzo del planificado del armado del proyecto y búsqueda de posibles materiales de los tubos que pasan por el colchón.

📍 Entrada 6

• Fecha: [28 de abril]

• Hora de inicio – fin: [9:00am a 10:00am]

•🔧 Actividades realizadas:

Contacto con sponsors como Simmons, Picca, Electro Componentes

📍 Entrada 7

- Fecha [29 de abril]
- Hora de inicio – fin: [08:00am 10:40am]
- 🔧 Actividades realizadas:

Se hablo con Picca hogar y se habló con German Picca

📍 Entrada 8

• Fecha: [9 de mayo]

• Hora de inicio – fin: [8:00am a 11:30am]

•🔧 Actividades realizadas:

Nos encontramos con la gerente de marketing de Simmons argentina y con el gerente de la sucursal de argentina. Hicimos un recorrido por las instalaciones y aprendimos sobre los diferentes tipos de colchones y su fabricación, conseguimos que nos patrocinaron con un colchón de resortes de una plaza.

📍 Entrada 9

• Fecha: [21 de mayo]

• Hora de inicio – fin: [14:20pm 15:00pm]

•🔧 Actividades realizadas:

Se recibió el colchón

📍 Entrada 10

• Fecha: [19 de junio]

• Hora de inicio – fin: [17:00pm 18:00pm]

•🔧 Actividades realizadas:

Compra y retiro de materiales

📍 Entrada 11

• Fecha: [ 8 de junio]

• Hora de inicio – fin: [9:00am 11:30am]

•🔧 Actividades realizadas:

Sellado de los tanques con espuma de poliuretano

📍 Entrada 12

• Fecha: [10 de junio]

• Hora de inicio – fin: [9:00am 11:00am]

•🔧 Actividades realizadas:

Impresión, planchado y puesto en acido de la placa de cobre

📍 Entrada 13

• Fecha: [11 de junio]

• Hora de inicio – fin: [10:30am 11:00am]

•🔧 Actividades realizadas:

Soldado de los componentes de la placa

📍 Entrada 14

• Fecha: [ 14 de Junio]

• Hora de inicio – fin: [17:30pm 18:00pm]

•🔧 Actividades realizadas:

Retiro de componentes

📍 Entrada 15

- Fecha [4 de julio]
- Hora de inicio – fin: [8:30am 11:30pm]
- 🔧 Actividades realizadas:

Se termino el diseño del circuito para las bombas de agua y se empezo la impresion y armado

📍 Entrada 16

• Fecha: [11 de julio]

• Hora de inicio – fin: [8:00am 12:00pm]

•🔧 Actividades realizadas: creado de soportes

Se empezó a realizar los soportes de los circuitos

📍 Entrada 17

• Fecha: [14 de julio]

• Hora de inicio – fin: [14:00pm 17:00pm]

•🔧 Actividades realizadas: primeras pruebas de apertura de colchón

Se empezó con la primera prueba de la apertura de colchón

📍 Entrada 18

• Fecha: [5 de agosto]

• Hora de inicio – fin: [14:00pm 16:30 pm]

•🔧 Actividades realizadas: primeras pruebas de temperatura de colchón

Se empezó a probar el control de temperatura del colchón

📍 Entrada 19

• Fecha: [13 de agosto]

• Hora de inicio – fin: [8:00am 12:00pm]

•🔧 Actividades realizadas: adaptación de planchas de aluminio

Se Modifico los tanques de agua adaptando planchas de aluminio previamente cortadas

📍 Entrada 20

• Fecha: [26 de agosto]

• Hora de inicio – fin: [8:00am 12:00pm]

•🔧 Actividades realizadas: adaptación de planchas de aluminio

Se terminaron de poner las planchas de aluminio y se sellaron fugas

📍 Entrada 21

• Fecha: [28 de agosto]

• Hora de inicio – fin: [8:00am 12:00pm]

•🔧 Actividades realizadas: adaptación de planchas de aluminio

se sellaron fugas de los tanques.

📍 Entrada 22

• Fecha: [16 de septiembre]

• Hora de inicio – fin: [10:00am 10:30am]

•🔧 Actividades realizadas: se abrió parte del colchón y se sacaron medidas

📍 Entrada 23

• Fecha: [19 de septiembre]

• Hora de inicio – fin: [8:00am 11:30am]

•🔧 Actividades realizadas: se agujereo, se soldó y trabajo con la placa de la pulsera

📍 Entrada 24

• Fecha: [23 de septiembre]

• Hora de inicio – fin: [9:00am 11:45am]

•🔧 Actividades realizadas: Terminar de armar la placa de la pulsera

📍 Entrada 25

• Fecha: [26 de septiembre]

• Hora de inicio – fin: [10:00am 12.00pm]

•🔧 Actividades realizadas: Se Probaron las nuevas placas y se arreglaron errores

📍Entrada 26

• Fecha: [3 de octubre]

• Hora de inicio – fin: [2:00pm 5pm]

•🔧Actividades realizadas: Prueba y arreglo de placa de pulsera

📍 Entrada 27

• Fecha: [7 de octubre]

• Hora de inicio – fin: [10:00am 12:00 pm]

•🔧 Actividades realizadas: Se empezó con la apertura del colchón

📍 Entrada 28

• Fecha: [8 de octubre]

• Hora de inicio – fin: [10:00am 12:00 pm]

•🔧 Actividades realizadas: Se termino con la apertura del colchón y el pasado de los caños

📍 Entrada 29

• Fecha: [8 de octubre]

• Hora de inicio – fin: [14:00pm 14:30]

•🔧 Actividades realizadas: Se probo el pasado de los caños por el colchón y su comodidad/funcionamiento

📍 Entrada 30

• Fecha: [14 de octubre]

• Hora de inicio – fin: [10:00am 12:00 pm]

•🔧 Actividades realizadas: Se probaron placas y se buscaron errores

📍 Entrada 31

• Fecha: [20 de octubre]

• Hora de inicio – fin: [8:00am 9:30am]

•🔧 Actividades realizadas: Se empezó con el diseño del banner

📍 Entrada 32

• Fecha: [21 de octubre]

• Hora de inicio – fin: [8:30am 9:00am]

•🔧 Actividades realizadas: Se trajo la base del colchón al colegio

📍 Entrada 33

• Fecha: [22 de octubre]

• Hora de inicio – fin: [8:00am 9:30am]

•🔧 Actividades realizadas: Se termino con el diseño del banner y se entrego

📍 Entrada 34

• Fecha: [30 de octubre]

• Hora de inicio – fin: [8:00am 11:45am]

•🔧 Actividades realizadas: Se grabaron las tomas para la video presentación

📍 Entrada 35

• Fecha: [30 de octubre]

• Hora de inicio – fin: [13:30pm 15:20pm]

•🔧 Actividades realizadas: Se empezó a hacer el manual de usuario

📍 Entrada 36

• Fecha: [31 de octubre]

• Hora de inicio – fin: [8:00am 11:00am]

•🔧 Actividades realizadas: Se empezó con la edición de el primer video presentación

📍 Entrada 37

• Fecha: [31 de octubre]

• Hora de inicio – fin: [15:30pm 16:00pm]

•🔧 Actividades realizadas: Se termino de editar y subir el primer modelo de la video presentación

📍 Entrada 38

• Fecha: [31 de octubre]

• Hora de inicio – fin: [16:10pm 17:00pm]

•🔧 Actividades realizadas: Se termino y subió el manual de usuario

📍 Entrada 39

• Fecha: [3 de noviembre]

• Hora de inicio – fin: [15:30pm 16:30pm]

•🔧 Actividades realizadas: Se cortaron y pulieron las patas para la base del colchón

📍 Entrada 40

• Fecha: [4 de noviembre]

• Hora de inicio – fin: [8:30am 10:30am]

•🔧 Actividades realizadas: Se empezó con la edición del modelo final del video presentación.

📍 Entrada 41

• Fecha: [5 de noviembre]

• Hora de inicio – fin: [15:30pm 17:00pm]

•🔧 Actividades realizadas: Se termino de editar y subir el modelo final del video presentación.

📍 Entrada 42

• Fecha: [12 de noviembre]

• Hora de inicio – fin: [9:00am 11:45am]

•🔧 Actividades realizadas: Se soldaron las patas de la cama.

📍 Entrada 43

• Fecha: [12 de noviembre]

• Hora de inicio – fin: [13:30pm 14:40pm]

•🔧 Actividades realizadas: Hice el curriculum vitae.

📍 Entrada 44

• Fecha: [12 de noviembre]

• Hora de inicio – fin: [15:00pm 16:30pm]

•🔧 Actividades realizadas: Se sellaron fugas del tanque de agua fría

📍 Entrada 45

• Fecha: [13 de noviembre]

• Hora de inicio – fin: [14:20pm 15:30pm]

•🔧 Actividades realizadas: Se puso a prueba el proyecto

📍 Entrada 46

• Fecha: [14 de noviembre]

• Hora de inicio – fin: [8:00am 9:30am]

•🔧 Actividades realizadas: armado y acomodación del stand

📍 Entrada 47

• Fecha: [15 de noviembre]

• Hora de inicio – fin: [13:00pm 19:00pm]

•🔧 Actividades realizadas: Se presento el proyecto en la muestra de fin de año

Integrante: Joaquín Vignetta

📆 Entradas de desarrollo

📍 Entrada 1

• Fecha: [15 de marzo]

• Hora de inicio – fin: [12:00pm 5:00pm]

• 🔧 Actividades realizadas:

Comienzo del ante proyecto, investigación de cómo se podría hacer análisis de costos y armado de la lista de materiales.

Investigación de a que grupos podríamos ayudar.

📍 Entrada 2

- Fecha [18 de marzo]
- Hora de inicio – fin: [08:00am 11:30am]
- 🔧 Actividades realizadas:

Comienzo del planificado del armado del proyecto y búsqueda de posibles materiales.

📍 Entrada 3

- Fecha [25 de marzo]
- Hora de inicio – fin: [10:00am 11:30am]
- 🔧 Actividades realizadas:

Busqueda de materiales para el proyecto.

📍 Entrada 4

- Fecha [20 de abril]
- Hora de inicio – fin: [2pm 5pm]
- 🔧 Actividades realizadas:

Actualizacion de lista de compras con materiales que se pudieron conseguir en los talleres

📍 Entrada 5

- Fecha [9 de Mayo]
- Hora de inicio – fin: [8:00am 11:40am]
- 🔧 Actividades realizadas:

Nos encontramos con la gerente de marketing de Simmons argentina y con el gerente de la sucursal de argentina. Nos dieron un recorrido, nos mostraron los tipos de colchones disponibles, su diseño y caracteristicas. Nos dieron un colchon y materiales que guardamos en la jaula.

📍 Entrada 6

- Fecha [19 de junio]
- Hora de inicio – fin: [2:30pm 5:00pm]
- 🔧 Actividades realizadas:

Fuimos a hablar con cooperadora junto al jefe de area para hacer pedidos de la lista de compras, conseguimos que hagan los pedidos, los caños de cobre se fueron a comprar por lorenzo y federico.

📍 Entrada 7

- Fecha [24 de junio]
- Hora de inicio – fin: [08:00am 10:40am]
- 🔧 Actividades realizadas:

Se empieza diseño de circuito para conectar las bombas de agua a la pico y poder controlarlas

📍 Entrada 8

- Fecha [3 de julio]
- Hora de inicio – fin: [2:30pm 5:30pm]
- 🔧 Actividades realizadas:

Se obtenieron componentes que llegaron de cooperadora y investigamos sobre sensores para crear una banda para poder medir el estado de una persona usando el colchon y pasar los datos a la pico.

📍 Entrada 9

- Fecha [4 de julio]
- Hora de inicio – fin: [8:30am 11:30pm]
- 🔧 Actividades realizadas:

Se termino el diseño del circuito para las bombas de agua y se empezo la impresion y armado

📍 Entrada 10

- Fecha [4 de julio]
- Hora de inicio – fin: [1:10pm 3:00pm]
- 🔧 Actividades realizadas:

Se penso el diseño de la banda y los materiales necesarios, se buscaron y se agregaron a lista de compras. Tambien se continuo el armado del circuito de las bombas de agua.

📍 Entrada 11

- Fecha [8 de julio]
- Hora de inicio – fin: [08:00am 11:30am]
- 🔧 Actividades realizadas:

Se investigo sobre el uso de Esp32 y busco huellas para diseño de un circuito usandolo para la banda

📍 Entrada 12

- Fecha [11 de julio]
- Hora de inicio – fin: [8:10am 11:30pm]
- 🔧 Actividades realizadas:

Se termina el armado del circuito de las bombas de agua.

📍 Entrada 13

- Fecha [5 de Agosto]
- Hora de inicio – fin: [2pm 4:30pm]
- 🔧 Actividades realizadas:

Prueba de calefaccion en el tanque y como se transmite por los materiales de la cama.

📍 Entrada 14

- Fecha [6 de Agosto]
- Hora de inicio – fin: [8:10am 11:30pm]
- 🔧 Actividades realizadas:

Diseño de controlador para la resistencia del tanque y armado.

📍 Entrada 15

- Fecha [12 de Agosto]
- Hora de inicio – fin: [2pm - 5pm]
- 🔧 Actividades realizadas:

Continua con la placa del calefon y se rehace la de la bomba

📍 Entrada 16

- Fecha [27 de Agosto]
- Hora de inicio – fin: [2pm - 5pm]
- 🔧 Actividades realizadas:

Se sueldan componentes que vinieron de cooperadora a las placas para terminarlas

📍 Entrada 17

- Fecha [29 de Agosto]
- Hora de inicio – fin: [2pm - 5pm]
- 🔧 Actividades realizadas:

Diseño de placa de pulsera con esp32.

📍 Entrada 18

- Fecha [2 de Septiembre]
- Hora de inicio – fin: [8am - 11:45am]
- 🔧 Actividades realizadas:

Soldadura de sensores para la placa de la pulsera y prueba de esp32.

📍 Entrada 19

- Fecha [19 de septiembre]
- Hora de inicio – fin: [8:10am 11:30pm]
- 🔧 Actividades realizadas: Impresión y comienzo de armado de placa pulsera

📍Entrada 20

• Fecha: [23 de septiembre]

• Hora de inicio – fin: [9:00am 11:45am]

•🔧Actividades realizadas: Terminar de soldar componentes de la placa de la pulsera

📍Entrada 21

• Fecha: [26 de septiembre]

• Hora de inicio – fin: [9:00am 11:45am]

•🔧Actividades realizadas: Prueba de placas de sensor y bomba

📍Entrada 22

• Fecha: [30 de septiembre]

• Hora de inicio – fin: [9:00am 11:45am]

•🔧Actividades realizadas:

Rediseño de placas de bomba y pulsera final

📍Entrada 23

• Fecha: [1 de octubre]

• Hora de inicio – fin: [2pm 4pm]

•🔧Actividades realizadas: Pasado de diseño a placas con cnc

📍Entrada 24

• Fecha: [3 de octubre]

• Hora de inicio – fin: [9:00am 11:45am]

•🔧Actividades realizadas: Soldado de placas de pulsera y bomba

📍Entrada 25

• Fecha: [3 de octubre]

• Hora de inicio – fin: [2:00pm 5pm]

•🔧Actividades realizadas: Prueba y arreglo de placa de pulsera

📍Entrada 26

• Fecha: [7 de octubre]

• Hora de inicio – fin: [9:00am 11:45am]

•🔧Actividades realizadas: Prueba de placa de bomba y ajuste

📍Entrada 27

• Fecha: [7 de octubre]

• Hora de inicio – fin: [2:00pm 5pm]

•🔧Actividades realizadas: Soldado de ajustes en la placa de la bomba

📍Entrada 28

• Fecha: [14 de octubre]

• Hora de inicio – fin: [9:00am 11:45am]

•🔧Actividades realizadas: Investigación de cargador para la batería y conectores

📍Entrada 29

• Fecha: [17 de octubre]

• Hora de inicio – fin: [9:00am 11:45am]

•🔧Actividades realizadas: Arreglo de soldadura en placa de bomba

📍Entrada 30

• Fecha: [22 de octubre]

• Hora de inicio – fin: [9:00am 11:45am]

•🔧Actividades realizadas: Diseño de placas para valvulas y raspberry

📍Entrada 31

• Fecha: [23 de octubre]

• Hora de inicio – fin: [9:00am 11:45am]

•🔧Actividades realizadas: Rediseño de placa de raspberry

📍Entrada 32

• Fecha: [23 de octubre]

• Hora de inicio – fin: [2pm 5pm]

•🔧Actividades realizadas:Impresion en CNC de placas de valvula y raspberry

📍Entrada 33

• Fecha: [24 de octubre]

• Hora de inicio – fin: [9:00 am 11:45am]

•🔧Actividades realizadas: Soldadura de placas de valvula

📍Entrada 34

• Fecha: [24 de octubre]

• Hora de inicio – fin: [2pm 5pm]

•🔧Actividades realizadas: Soldadura y prueba de placa de raspberry

📍Entrada 35

• Fecha: [29 de octubre]

• Hora de inicio – fin: [2pm 5pm]

•🔧Actividades realizadas: Compra de materiales para conecciones 220v

📍Entrada 36

• Fecha: [31 de octubre]

• Hora de inicio – fin: [2pm 5pm]

•🔧 Actividades realizadas: Agrego de texto al manual de usuario

📍Entrada 37

• Fecha: [5 de Noviembre]

• Hora de inicio – fin: [2pm 5pm]

•🔧 Actividades realizadas: Rediseño de placa de raspberry.

📍Entrada 38

• Fecha: [12 de Noviembre]

• Hora de inicio – fin: [2pm 5pm]

•🔧 Actividades realizadas: Impresion final de placa de raspberry y prueba

📍Entrada 39

• Fecha: [13de Noviembre]

• Hora de inicio – fin: 9am 11:45am]

•🔧 Actividades realizadas: Conexión de todas las partes del proyecto.

📍Entrada 40

• Fecha: [13 de Noviembre]

• Hora de inicio – fin: 2m 11:45am]

•🔧 Actividades realizadas: Conexión de todas las partes del proyecto

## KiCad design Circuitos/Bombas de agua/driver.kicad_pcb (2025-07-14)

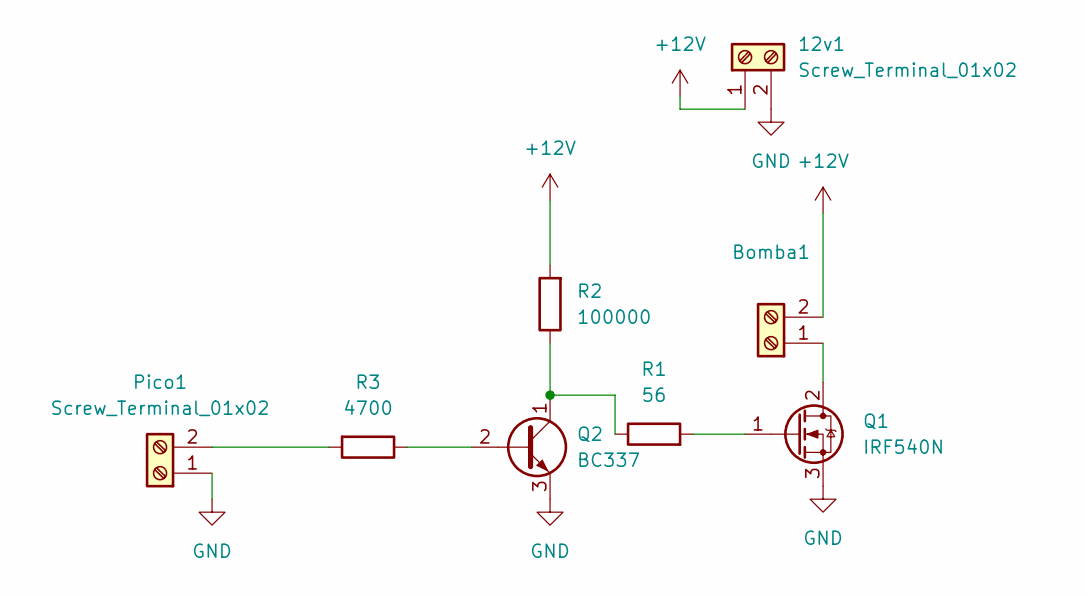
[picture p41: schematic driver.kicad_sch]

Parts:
12v1: Screw_Terminal_01x02; TerminalBlock_MaiXu_MX126-5.0-02P_1x02_P5.00mm
Bomba1: Screw_Terminal_01x02; TerminalBlock_MaiXu_MX126-5.0-02P_1x02_P5.00mm
Pico1: Screw_Terminal_01x02; TerminalBlock_MaiXu_MX126-5.0-02P_1x02_P5.00mm
Q1: IRF540N; TO-220-3_Vertical
Q2: BC337; TO-92_Inline
R1: 56; R_Box_L14.0mm_W5.0mm_P9.00mm
R2: 100000; R_Box_L14.0mm_W5.0mm_P9.00mm
R3: 4700; R_Box_L14.0mm_W5.0mm_P9.00mm

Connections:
unnamed: 12v1.1, Bomba1.2, R2.2
unnamed: 12v1.2, Pico1.1, Q1.3 (S), Q2.3 (E)
unnamed: Bomba1.1, Q1.2 (D)
unnamed: Pico1.2, R3.2
unnamed: Q1.1 (G), R1.2
unnamed: Q2.2 (B), R3.1
unnamed: Q2.1 (C), R1.1, R2.1

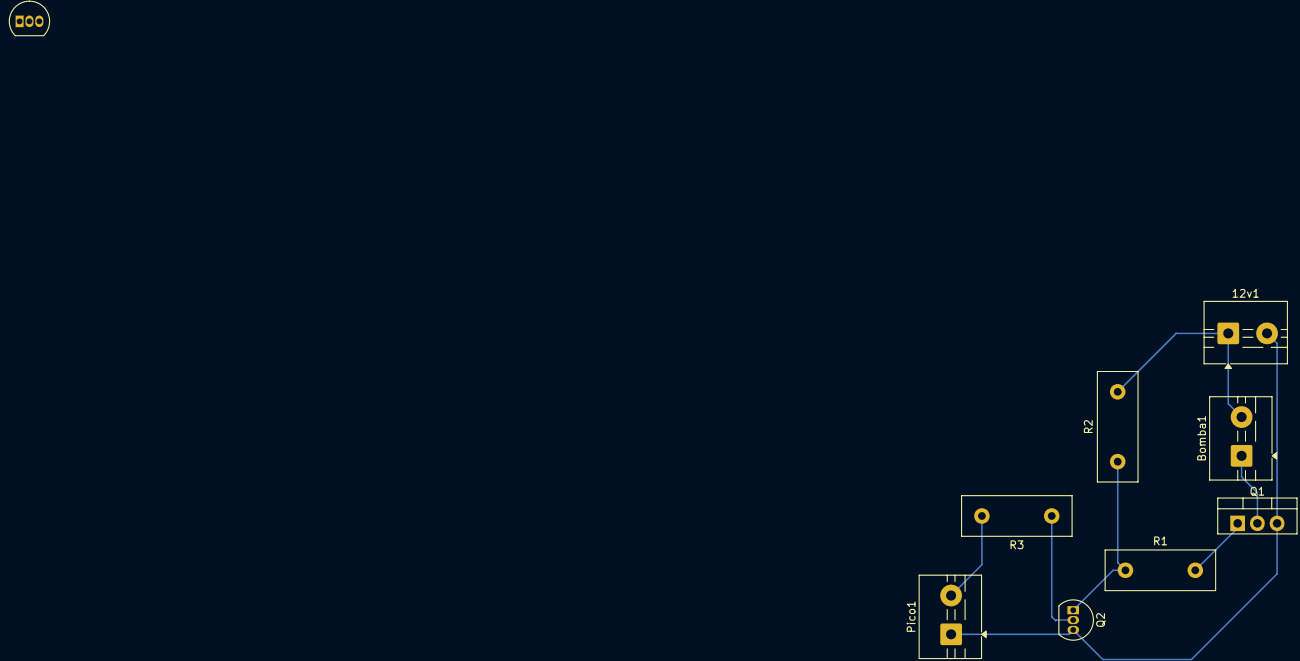
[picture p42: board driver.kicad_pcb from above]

Board: 2 copper layers, 9 parts (0 on the bottom side), 7 nets.

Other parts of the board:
Q1#2: BS108; TO-92_Inline

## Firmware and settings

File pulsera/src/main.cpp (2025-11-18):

#include <WiFi.h>
#include <PubSubClient.h>
#include <Wire.h>
#include <HTU21D.h>
#include <MAX30105.h>
#include <heartRate.h>
#include <SparkFun_MMA8452Q.h>

// Configuración WiFi
const char* ssid = "xiaomi";
const char* password = "raspberry";

// Configuración MQTT
const char* mqtt_server = "172.22.39.27";  // IP de tu Raspberry Pi
const int mqtt_port = 1883;
const char* mqtt_user = "tu_usuario";  // opcional
const char* mqtt_password = "tu_password";  // opcional

WiFiClient espClient;
PubSubClient client(espClient);

// Sensores
HTU21D htu21d;
MAX30105 max30102;
MMA8452Q accel;

// Variables de estado
bool htu21d_ok = false;
bool max30102_ok = false;
bool accel_ok = false;

// Variables para Heart Rate (basado en ejemplo oficial)
const byte RATE_SIZE = 4; // Increase this for more averaging. 4 is good.
byte rates[RATE_SIZE]; // Array of heart rates
byte rateSpot = 0;
long lastBeat = 0; // Time at which the last beat occurred
float beatsPerMinute = 0;
int beatAvg = 0;

void setup_wifi() {
  delay(10);
  WiFi.begin(ssid, password);
  
  int intentos = 0;
  while (WiFi.status() != WL_CONNECTED && intentos < 30) {
    delay(500);
    intentos++;
  }
}

void reconnect() {
  while (!client.connected()) {
    if (client.connect("ESP32Client_Sensores", mqtt_user, mqtt_password)) {
      client.publish("sensores/status", "ESP32 conectado - Iniciando lecturas de sensores");
    } else {
      delay(5000);
    }
  }
}

void setup() {
  // Inicializar I2C en pines del ESP32-C3
  Wire.begin(6, 7);  // SDA=GPIO6, SCL=GPIO7
  Wire.setClock(100000);  // 100kHz
  
  setup_wifi();
  client.setServer(mqtt_server, mqtt_port);
  
  // Conectar MQTT
  reconnect();
  
  client.publish("sensores/info", "Inicializando sensores en ESP32-C3");
  client.publish("sensores/config", "I2C: SDA=GPIO6, SCL=GPIO7, 100kHz");
  
  // Inicializar HTU21D (Temperatura y Humedad)
  if (htu21d.begin()) {
    htu21d_ok = true;
    client.publish("sensores/htu21d", "HTU21D inicializado correctamente");
  } else {
    htu21d_ok = false;
    client.publish("sensores/error", "HTU21D no encontrado");
  }
  
  // Inicializar MAX30105 (Pulso cardíaco)
  if (max30102.begin(Wire, I2C_SPEED_FAST)) { // Usar I2C_SPEED_FAST como en el ejemplo
    max30102.setup(); // Configuración por defecto como en el ejemplo
    max30102.setPulseAmplitudeRed(0x0A); // Turn Red LED to low to indicate sensor is running
    max30102.setPulseAmplitudeGreen(0);  // Turn off Green LED
    max30102_ok = true;
    client.publish("sensores/max30105", "MAX30105 inicializado correctamente");
  } else {
    max30102_ok = false;
    client.publish("sensores/error", "MAX30105 no encontrado");
  }
  
  // Inicializar MMA8452Q (Acelerómetro)
  if (accel.begin()) {
    accel.setScale(SCALE_2G);
    accel.setDataRate(ODR_12);
    accel_ok = true;
    client.publish("sensores/mma8452q", "MMA8452Q inicializado correctamente - Escala 2g");
  } else {
    accel_ok = false;
    client.publish("sensores/error", "MMA8452Q no encontrado");
  }
  
  // Resumen de inicialización
  String resumen = "Sensores activos: ";
  if (htu21d_ok) resumen += "HTU21D ";
  if (max30102_ok) resumen += "MAX30105 ";
  if (accel_ok) resumen += "MMA8452Q ";
  if (!htu21d_ok && !max30102_ok && !accel_ok) resumen += "NINGUNO";
  
  client.publish("sensores/resumen", resumen.c_str());
}

void loop() {
  if (!client.connected()) {
    reconnect();
  }
  client.loop();

  // Leer sensores cada 2 segundos
  static unsigned long lastMsg = 0;
  static int contador = 0;
  unsigned long now = millis();
  
  if (now - lastMsg > 2000) {  // Cada 2 segundos
    lastMsg = now;
    contador++;
    
    client.publish("sensores/contador", String(contador).c_str());
    
    // Enviar resumen cada 10 ciclos (cada 20 segundos)
    if (contador % 10 == 1) {
      String resumen = "Sensores activos: ";
      if (htu21d_ok) resumen += "HTU21D ";
      if (max30102_ok) resumen += "MAX30105 ";
      if (accel_ok) resumen += "MMA8452Q ";
      if (!htu21d_ok && !max30102_ok && !accel_ok) resumen += "NINGUNO";
      
      client.publish("sensores/resumen", resumen.c_str());
    }
    
    // ==================== LEER HTU21D ====================
    if (htu21d_ok) {
      if (htu21d.measure()) {
        float temperatura = htu21d.getTemperature();
        float humedad = htu21d.getHumidity();
        
        if (!isnan(temperatura) && temperatura >= -40 && temperatura <= 125) {
          client.publish("sensores/temperatura", String(temperatura, 2).c_str());
        } else {
          client.publish("sensores/error", "HTU21D: temperatura invalida");
        }
        
        if (!isnan(humedad) && humedad >= 0 && humedad <= 100) {
          client.publish("sensores/humedad", String(humedad, 2).c_str());
        } else {
          client.publish("sensores/error", "HTU21D: humedad invalida");
        }
      } else {
        client.publish("sensores/error", "HTU21D: fallo en medicion");
      }
    }
    
    // ==================== LEER MAX30105 ====================
    if (max30102_ok) {
      // Leer valor IR directamente (como en el ejemplo oficial)
      long irValue = max30102.getIR();
      
      // Publicar valor IR
      client.publish("sensores/ir_value", String(irValue).c_str());
      
      // Usar algoritmo oficial de SparkFun para detectar latidos
      if (checkForBeat(irValue) == true) {
        // ¡Detectamos un latido!
        long delta = millis() - lastBeat;
        lastBeat = millis();
        
        beatsPerMinute = 60 / (delta / 1000.0);
        
        if (beatsPerMinute < 255 && beatsPerMinute > 20) {
          // Almacenar esta lectura en el array
          rates[rateSpot++] = (byte)beatsPerMinute;
          rateSpot %= RATE_SIZE; // Wrap variable
          
          // Calcular promedio de lecturas
          beatAvg = 0;
          for (byte x = 0; x < RATE_SIZE; x++)
            beatAvg += rates[x];
          beatAvg /= RATE_SIZE;
        }
      }
      
      // Estado del dedo (igual que en el ejemplo oficial)
      String finger_status = (irValue < 50000) ? "no_detectado" : "detectado";
      
      // Publicar datos de heart rate
      client.publish("sensores/bpm", String((int)beatsPerMinute).c_str());
      client.publish("sensores/bpm_avg", String(beatAvg).c_str());
      client.publish("sensores/finger_status", finger_status.c_str());
      
      // JSON con datos del corazón
      String heart_json = "{\"ir\":" + String(irValue) + 
                        ",\"bpm\":" + String((int)beatsPerMinute) + 
                        ",\"bpm_avg\":" + String(beatAvg) + 
                        ",\"finger\":\"" + finger_status + "\"}";
      client.publish("sensores/heart_data", heart_json.c_str());
    }
    
    // ==================== LEER MMA8452Q ====================
    if (accel_ok) {
      if (accel.available()) {
        accel.read();
        
        float x = accel.getCalculatedX();
        float y = accel.getCalculatedY();
        float z = accel.getCalculatedZ();
        
        // Verificar valores válidos
        if (x >= -4 && x <= 4) {
          client.publish("sensores/accel_x", String(x, 3).c_str());
        }
        if (y >= -4 && y <= 4) {
          client.publish("sensores/accel_y", String(y, 3).c_str());
        }
        if (z >= -4 && z <= 4) {
          client.publish("sensores/accel_z", String(z, 3).c_str());
        }
        
        // Calcular magnitud
        float magnitud = sqrt(x*x + y*y + z*z);
        client.publish("sensores/accel_mag", String(magnitud, 3).c_str());
        
        // Detectar orientación
        String orientacion = "indefinida";
        if (abs(z) > abs(x) && abs(z) > abs(y)) {
          if (z > 0.5) orientacion = "boca_arriba";
          else if (z < -0.5) orientacion = "boca_abajo";
        }
        client.publish("sensores/orientacion", orientacion.c_str());
        
        // Detectar movimiento
        client.publish("sensores/movimiento", (magnitud > 1.5) ? "SI" : "NO");
        
        // Datos JSON combinados
        String accel_json = "{\"x\":" + String(x,3) + ",\"y\":" + String(y,3) + ",\"z\":" + String(z,3) + ",\"mag\":" + String(magnitud,3) + "}";
        client.publish("sensores/accel_datos", accel_json.c_str());
        
      } else {
        client.publish("sensores/error", "MMA8452Q: sin nuevos datos");
      }
    }
    
    // Estado del sistema
    client.publish("sistema/wifi_ip", WiFi.localIP().toString().c_str());
    client.publish("sistema/wifi_status", (WiFi.status() == WL_CONNECTED) ? "conectado" : "desconectado");
    client.publish("sistema/uptime", String(millis() / 1000).c_str());
    
    // Estado de sensores cada 5 ciclos (cada 10 segundos)
    if (contador % 5 == 0) {
      client.publish("sensores/estado_htu21d", htu21d_ok ? "OK" : "ERROR");
      client.publish("sensores/estado_max30105", max30102_ok ? "OK" : "ERROR");
      client.publish("sensores/estado_mma8452q", accel_ok ? "OK" : "ERROR");
  }
  }
}

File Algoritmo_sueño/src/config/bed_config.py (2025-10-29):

# CONFIGURACIÓN UNIFICADA PARA CAMA ORTOPÉDICA INTELIGENTE
# =========================================================
# Unifica config.py y bed_config.py en una sola configuración completa

# CONFIGURACIÓN BÁSICA
# --------------------
VERBOSE_OUTPUT = True  # Mostrar información detallada
STIMULUS_ACTIVE = False  # Activar estímulos (obsoleto)
SYSTEM_NAME = "Cama Ortopédica Inteligente v2.0 - REM Edition"

# HARDWARE - I2C ADDRESSES
# ------------------------
I2C_ACCEL_ADDR = 0x1D        # Dirección del acelerómetro MMA8452Q
I2C_MAX30102_ADDR = 0x57     # Dirección del sensor MAX30102
I2C_AHT10_ADDR = 0x38        # Dirección del sensor AHT10 (pulsera)
I2C_HTU21D_ADDR = 0x40       # Dirección del sensor HTU21D (temperatura cama)
ACCELEROMETER_ACTIVITY_THRESHOLD = 12.5  # Umbral de detección de movimiento

# SENSOR MAX30102 (Oximetría + HR + Temperatura ambiente)
# -------------------------------------------------------
MAX30102_ENABLED = True  # Usar MAX30102 en lugar de Bluetooth
FINGER_DETECTION_THRESHOLD = 50000  # Umbral para detectar dedo
SPO2_MIN_ALERT = 88  # SpO2 mínimo antes de alerta
SPO2_MAX_NORMAL = 100  # SpO2 máximo normal

# SENSOR AHT10 (Temperatura corporal en pulsera)
# ----------------------------------------------
AHT10_ENABLED = True  # Usar AHT10 para temperatura corporal
BODY_TEMP_MIN_ALERT = 35.5   # Temperatura corporal mínima (°C)
BODY_TEMP_MAX_ALERT = 38.0   # Temperatura corporal máxima (°C)
BODY_TEMP_FEVER = 38.0       # Umbral de fiebre (°C)

# SENSOR HTU21D (Temperatura de la cama)
# --------------------------------------
HTU21D_ENABLED = True        # Usar HTU21D para temperatura de la cama
BED_TEMP_MIN = 15.0          # Temperatura mínima de la cama (°C)
BED_TEMP_MAX = 30.0          # Temperatura máxima de la cama (°C)
BED_TEMP_TOLERANCE = 0.5     # Tolerancia antes de activar válvulas (°C)
BED_TEMP_UPDATE_INTERVAL = 5 # Intervalo de actualización en segundos

# CONTROL TÉRMICO PREDICTIVO - Basado en estudios científicos
# ----------------------------------------------------------
THERMAL_DESCENT_RATE = 0.8   # Descenso térmico natural durante sueño (°C)
THERMAL_VARIANCE_TOLERANCE = 2.0  # Variabilidad térmica normal (±°C)
THERMAL_ANTICIPATION_TIME = 10    # Tiempo de anticipación térmica (minutos)
THERMAL_RESPONSE_SENSITIVITY = 0.3 # Sensibilidad de respuesta térmica
SLEEP_THERMAL_ADAPTATION = True   # Activar adaptación térmica durante sueño

# ESTADOS DE SUEÑO (4 Estados - Incluye REM)
# ------------------------------------------
SLEEP_STATE_WAKE = 0
SLEEP_STATE_LIGHT = 1
SLEEP_STATE_REM = 2          # ✅ Nuevo estado REM
SLEEP_STATE_DEEP = 3         # ✅ Actualizado a valor 3

# DETECCIÓN DE SUEÑO - ACTIVIDAD
# ------------------------------
ACTIVITY_THRESHOLD_DEEP_SLEEP = 0.01   # < 0.01 = sueño profundo
ACTIVITY_THRESHOLD_REM = 0.008          # < 0.008 = REM (con micro-movimientos)
ACTIVITY_THRESHOLD_WAKE = 0.7           # > 0.7 = despierto

# DETECCIÓN DE SUEÑO - FRECUENCIA CARDÍACA  
# ----------------------------------------
HR_THRESHOLD_DEEP_SLEEP = 55   # < 55 BPM = sueño profundo
HR_THRESHOLD_REM = 70          # ≥ 70 BPM + baja actividad = REM
HR_THRESHOLD_WAKE = 75         # ≥ 75 BPM = despierto

# PESOS PARA ALGORITMO COMBINADO
# ------------------------------
ACTIVITY_WEIGHT = 0.6  # Peso de la actividad en la detección (60%)
HR_WEIGHT = 0.4        # Peso del HR en la detección (40%)

# INTEGRADOR DE ACTIVIDAD
# -----------------------
ACTIVITY_DECAY_CONSTANT = 2 * 60 * 1000.0      # Constante de decaimiento (2 min)
ACTIVITY_SPIKE_STRENGTH = 0.05                  # Fuerza del pico de actividad
ACTIVITY_DECAY_DELAY = 5 * 60 * 1000.0          # Retardo antes del decaimiento (5 min)
ACTIVITY_LOWER_BOUND = 1e-3                     # Límite inferior de actividad

# CONTROL DE TEMPERATURA POR ESTADO (4 Estados)
# -----------------------------------------------
# Rangos de temperatura por estado de sueño (°C)
TEMP_WAKE = {"min": 20, "max": 24}              # Despierto: confort normal
TEMP_LIGHT_SLEEP = {"min": 18, "max": 22}       # Sueño ligero: ligeramente más fresco
TEMP_REM_SLEEP = {"min": 19, "max": 23}         # ✅ REM: similar a vigilia (termorregulación alterada)
TEMP_DEEP_SLEEP = {"min": 16, "max": 20}        # Sueño profundo: más fresco para mejor descanso

# Ajustes automáticos
TEMP_ADJUSTMENT_STEP = 0.5      # Paso de ajuste de temperatura (°C)
TEMP_CHANGE_THRESHOLD = 1.0     # Umbral para cambiar temperatura (°C)
TEMP_UPDATE_INTERVAL = 30       # Intervalo de actualización (segundos)

# LÍMITES DE SEGURIDAD
# --------------------
MIN_SAFE_TEMP = 10     # Temperatura mínima absoluta (°C)
MAX_SAFE_TEMP = 30     # Temperatura máxima absoluta (°C)
MAX_HR_ALERT = 120     # HR máxima antes de alerta (BPM)
MIN_HR_ALERT = 40      # HR mínima antes de alerta (BPM)
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

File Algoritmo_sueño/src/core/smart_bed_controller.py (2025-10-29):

#!/usr/bin/env python3
"""
Sistema de Control Inteligente para Cama Ortopédica
Ajusta temperatura basado en estado de sueño, temperatura ambiente y corporal
Control de válvulas eléctricas de 220V para tanques de agua fría y caliente
Usa sensor MAX30102 para monitoreo de HR y SpO2
"""

import asyncio
import time
import numpy as np
from ..config import bed_config
from . import analyzer
from . import presence_detector
from ..sensors.drivers import MMA
from ..sensors.drivers import MAX30102
from ..sensors.drivers import HTU21D

# Importar driver AHT10 para temperatura ambiente
try:
    import adafruit_ahtx0
    import board
    import busio
    AHT10_AVAILABLE = True
except ImportError:
    print("⚠️ AHT10 no disponible - Usando temperatura del MAX30102")
    AHT10_AVAILABLE = False

# Importar GPIO para control de relés
try:
    import RPi.GPIO as GPIO
    GPIO_AVAILABLE = True
except ImportError:
    print("⚠️ GPIO no disponible - Modo simulación")
    GPIO_AVAILABLE = False

# Estados de sueño
WAKE = 0
LIGHT_SLEEP = 1
REM_SLEEP = 2
DEEP_SLEEP = 3

# Configuración de pines GPIO para relés de válvulas (220V)
VALVE_HOT_WATER_PIN = bed_config.VALVE_HOT_WATER_PIN    # Pin para relé de válvula agua caliente
VALVE_COLD_WATER_PIN = bed_config.VALVE_COLD_WATER_PIN  # Pin para relé de válvula agua fría
VALVE_SAFETY_PIN = bed_config.VALVE_SAFETY_PIN          # Pin para relé de seguridad (corte general)

class SmartBedController:
    def __init__(self):
        """
        Controlador inteligente para cama ortopédica con válvulas de agua
        Usa MAX30102 para monitoreo de HR y SpO2
        """
        # Sensor MAX30102 para HR y SpO2
        try:
            self.max30102 = MAX30102.MAX30102(bed_config.I2C_MAX30102_ADDR)
            self.max30102_available = True
            print("✅ MAX30102 inicializado correctamente")
        except Exception as e:
            print(f"⚠️ MAX30102 no disponible: {e}")
            self.max30102_available = False
        
        # Acelerómetro para detección de movimiento
        try:
            self.mma8452q = MMA.MMA8452Q()
            self.activity_threshold = bed_config.ACCELEROMETER_ACTIVITY_THRESHOLD
            print("✅ Acelerómetro MMA8452Q inicializado")
        except Exception as e:
            print(f"⚠️ Acelerómetro no disponible: {e}")
            self.mma8452q = None
        
        # Sensor AHT10 para temperatura corporal (pulsera)
        try:
            if AHT10_AVAILABLE:
                i2c = busio.I2C(board.SCL, board.SDA)
                self.aht10 = adafruit_ahtx0.AHTx0(i2c)
                self.aht10_available = True
                print("✅ Sensor AHT10 (pulsera) inicializado correctamente")
            else:
                self.aht10_available = False
        except Exception as e:
            print(f"⚠️ AHT10 (pulsera) no disponible: {e}")
            self.aht10_available = False
        
        # Sensor HTU21D para temperatura de la cama
        try:
            self.htu21d = HTU21D.HTU21D(bed_config.I2C_HTU21D_ADDR)
            self.htu21d_available = self.htu21d.is_available()
            if self.htu21d_available:
                print("✅ Sensor HTU21D (temperatura cama) inicializado correctamente")
            else:
                print("⚠️ HTU21D no disponible - Usando temperatura simulada")
        except Exception as e:
            print(f"⚠️ HTU21D no disponible: {e}")
            self.htu21d_available = False
            self.htu21d = None
        
        # Variables de estado
        self.activity = 0.0
        self.last_spike = -1e10
        self.last_acc = [0.0, 0.0, 0.0]
        self.last_t = int(round(time.time() * 1000))
        self.current_sleep_state = WAKE
        self.current_hr = 60
        self.current_spo2 = 98
        
        # Historial para cálculos HRV y análisis avanzado
        self.hr_history = []
        self.ibi_history = []  # Inter-beat intervals
        self.activity_history = []
        self.sleep_state_history = []
        self.timestamps = []
        
        # Análisis en tiempo real
        self.current_stress_score = 0.0
        self.current_sleep_quality = 0.0
        self.sleep_onset_detected = False
        self.sleep_onset_time = None
        self.last_analysis_time = time.time()
        
        # Detector de presencia en la cama
        self.presence_detector = presence_detector.BedPresenceDetector()
        
        # Control de temperatura con válvulas - BASADO EN ESTUDIOS CIENTÍFICOS
        # Datos: Descenso natural de ~0.8°C durante sueño, variabilidad ±1-2°C
        self.target_temperature = 22.0
        self.current_temperature = 22.0  # Temperatura actual del HTU21D
        self.comfort_zone = {
            # Ajustado según estudios de temperatura rectal y microclima
            WAKE: {"min": 21, "max": 25},        # Vigilia - temperatura basal alta
            LIGHT_SLEEP: {"min": 19, "max": 23}, # Inicio descenso (0.2-0.4°C)
            REM_SLEEP: {"min": 20, "max": 24},   # REM - actividad cerebral = similar vigilia
            DEEP_SLEEP: {"min": 17, "max": 21}   # Profundo - descenso máximo (0.8°C)
        }
        
        # Variables para control predictivo basado en estudios
        self.thermal_trend = 0.0           # Tendencia térmica para anticipación
        self.sleep_thermal_offset = 0.0    # Offset térmico acumulado durante sueño
        self.last_temp_reading_time = time.time()
        self.temp_change_rate = 0.0        # Velocidad de cambio térmico (°C/min)
        
        # Estado de válvulas
        self.hot_valve_open = False
        self.cold_valve_open = False
        self.safety_active = True
        
        # Configurar GPIO para control de válvulas
        self.setup_gpio()
        
        print("🛏️ Sistema de cama inteligente con MAX30102 inicializado")
        print(f"💧 Válvula agua caliente: Pin {VALVE_HOT_WATER_PIN}")
        print(f"❄️ Válvula agua fría: Pin {VALVE_COLD_WATER_PIN}")
        print(f"🔒 Seguridad: Pin {VALVE_SAFETY_PIN}")
        print(f"❤️ Sensor MAX30102: {'✅ Disponible' if self.max30102_available else '❌ No disponible'}")
        print(f"📱 Acelerómetro: {'✅ Disponible' if self.mma8452q else '❌ No disponible'}")
        print(f"🌡️ Sensor HTU21D (cama): {'✅ Disponible' if self.htu21d_available else '❌ No disponible'}")
        print(f"🌡️ Sensor AHT10 (pulsera): {'✅ Disponible' if self.aht10_available else '❌ No disponible'}")
        print(f"🛏️ Detector de presencia: ✅ Activo")
        
        # Configurar GPIO para control de válvulas
        self.setup_gpio()
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

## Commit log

2025-07-08 Página Web
    Subo la pagina web de oibsleep
    -Falta agregar fotos
2025-07-08 Update README.md
    se agrego el link de la pagina web al read me
2025-07-14 Subida de Bitacora
2025-07-14 feat: Agrego diseño de circuito de bombas de agua
    Diseño en kicad del circuito a usar de las bombas de agua
    [driver.kicad_pcb, driver.kicad_sch]
2025-10-22 feat: Actualizar Bitacora
    Entradas agregadas de parte de Fede y Vignetta
2025-10-29 algoritmo de sueño
    Agregue el algoritmo sin funcionalidades todavia faltan cambios
2025-10-29 subir el codigo de la pulsera
    andan 2 sensores pero 1 todavia no hace bien el calculo de ritmo cariaco, el sensor de temperatura no es detectado
2025-10-29 feat:borrar manual de usuario
    Error al subir archivo
2025-10-29 feat: Manual de Usuario
    se subió la primera parte del manual de usuario
2025-10-31 feat: Borrar documento Manual de usuario
    Borrar el documento para agregar una version actualizada
2025-10-31 feat: Agregar informacion a Manual de usuario
    Se agrego informacion general y de partes especificas del proyecto
2025-10-31 feat: Agrego versiones de circuito de bombas de agua
2025-10-31 feat: carpeta pulsera
    carpeta para los circuitos de pulsera
2025-10-31 feat: Circuito de pulsera
    Se sube ultima version del circuito de pulsera
2025-10-31 feat: Carpeta de circuitos
    Carpeta para circuitos de resistencia y valvula
2025-10-31 feat: Circuito para control
    Subo circuito para control de resistencia y valvula
2025-10-31 Update Carpeta_Técnica.pdf
    hice de la pagina 9 a la 14
2025-11-01 Delete Documentos/MANUAL DE USUARIO.docx
    Para subir la version actualizada
2025-11-01 feat: Manual de Usuario terminado
    Se termino de completar el manual de usuario
2025-11-01 feat: Video Presentación
    Se termino y subió el video presentación
2025-11-03 Rename Modelo 3D/CAMA2.blend to Modelo 3D/Cama/CAMA2.blend
    [CAMA2.blend]
2025-11-03 Rename Modelo 3D/bed.glb to Modelo 3D/Cama/bed.glb
2025-11-03 Rename Modelo 3D/d.blend to Modelo 3D/Brazalete/d.blend
    [d.blend]
2025-11-03 Rename Modelo 3D/acople.stl to Modelo 3D/Acople/acople.stl
    [acople.stl]
2025-11-03 Rename Modelo 3D/soportes.dwg to Modelo 3D/Soportes de circuitos/soportes.dwg
    [soportes.dwg]
2025-11-05 feat: Carpeta raspberry
    Se creo la carpeta para la placa de la raspberry pi zero 2 w
2025-11-05 waterController
    Empiezo el codigo defino los pines y los tiempos de las tareas
2025-11-05 sigo con el codigo
    definí todas las tareas
2025-11-05 Historias
    Subí las historias de usuario
2025-11-05 waterController
    determinar el tiempo
2025-11-05 WaterController
    Termine el codigo para mandar agua fria con delays
2025-11-06 feat: Video Presentacion - ACTUALIZADO
    Se subió la versión actualizada del video presentación
2025-11-06 feat: Actualizacion circuito de raspberry
    Se actualiza el circuito para disminuir el tamaño para que entre
2025-11-06 feat: Bitácora del Proyecto Grupal[1].docx
    Se elimino para actualizar
2025-11-06 feat: Bitacora de Grupo
2025-11-06 feat: Banner del Proyecto
    Modelo final del Banner de proyecto
2025-11-06 feat: Banner del Proyecto
    Se subio el banner del proyecto a documentos
2025-11-06 feat: Boceto Banner
    Se subio el Boceto del Banner a Documentos
2025-11-07 Explicacion de presence_detector
2025-11-07 Rename Imagen de WhatsApp 2025-11-06 a las 14.43.27_1ab5a3b6.jpg to boceto.jpg
2025-11-07 Rename Imagen de WhatsApp 2025-11-06 a las 14.43.27_a5c3106a.jpg to texto_boceto.jpg
2025-11-07 Rename Imagen de WhatsApp 2025-11-06 a las 14.43.28_50c6df23.jpg to banner.jpg
2025-11-07 Rename Modelo 3D/acople 2 .stl to Modelo 3D/Acople/acople 2 .stl
    Acople para la electro válvula
    [acople 2 .stl]
2025-11-07 feat: Bitácora del Proyecto Grupa
    se borro para actualizar
2025-11-07 feat: Bitácora del Proyecto Grupal
    Se actualizo la bitácora
2025-11-07 subir codigo de latex
2025-11-07 feat: Carpeta tecnica
    Se agrego informacion de circuitos a la carpeta tecnica
2025-11-07 carpeta tecnica
    Llegue hasta la pagina 50 para la revision faltan cambiar placeholders y poner fotos de circuitos rotas
2025-11-10 actualize la carpeta tecnica
    agregue diagramas de bloques y arreglue unos errores
2025-11-12 Carpeta tecnica
    agregue fotos y tambien subi una parte del la seccion de circuito que hice vignetta.
2025-11-12 Carpeta Tecnica
    Termine la carpeta tecnica (sin fotos de los participantes)
2025-11-12 Termine la carpeta tecnica
2025-11-14 feat: Actualizar bitacora de proyecto
2025-11-18 Actualizacion de la carpeta tecnica
    Agregue las fotos de la carpeta tecnica
2025-11-18 feat: Bitácora del Proyecto Grupal
    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
2025-11-18 feat: Bitácora del Proyecto Grupal
    Se actualizo la bitacora
2025-11-18 feat: Curriculum vitae
    Se creo la carpeta de Curriculum vitae
2025-11-20 feat: Agrego lista de compras
2025-11-20 feat: agrego redes del grupo
    Redes de instagram y linkedin del proyecto
2025-11-20 feat: Curriculum Vitae
    Carpeta de los curriculums
2025-11-20 feat: Curriculum Vitae
    su subio el curriculum
